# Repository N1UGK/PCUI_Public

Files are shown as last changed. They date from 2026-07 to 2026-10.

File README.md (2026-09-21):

# PCUI (Pocket Computer Universal Interface)
This is the official repo for firmware updates for the PCUI, owners manuals, and general information.  Further, this repo contains a collection of programs for various pocket computers and calculators supported by the PCUI.



## Development History

https://n1ugk.com/2025/12/pocket-computer-universal-interface/

## Features Summary

+ Provides cassette interface emulation to read and write programs and data directly to and from a micro SD card.
+ Provides a printer interface between the pocket computer or calculator and most standard “line printers” such as dot matrix, thermal receipt printers, serial, parallel, and Wi-Fi.
+ Supports printing of custom glyphs, including math, scientific and engineering symbols unique to each model.
+ Works independently without a computer and can be powered by a single 18650 lithium ion rechargeable battery.
+ OLED screen with user-friendly menu system and operating modes
+ Interface packs provide connectivity to each supported model, no need for OEM connection cables.
+ Updatable firmware and PC or Mac connectivity via USB for mounting micro SD card
+ Plotter emulation mode to provide printouts of plots using modern printers allowing programs which leveraged plotter features to be used on modern printers.
+ ASCII BASIC conversion to tokenized BASIC “on the fly”, allowing for program edits and program creation on a Mac or PC and directly sending it to a pocket computer.
+ Wi-Fi connectivity and web interface for program viewing, editing, UI control, printing, and status.
+ Online program library browsing and installing directly from GitHub allows you to view community released programs for various models of pocket computers directly from the PCUI.
+ True low-level cassette interface integration - byte level retrieval and storage of programs and data images, not just a simple "record" and "playback" mechanism.

## Supported Models

The following models are currently supported with more models in progress:

+ Texas Instruments	Graph Link Graphing Calculators
  + TI-82*, TI-85*, TI-86*, TI-89*, TI-92*, TI-92 Plus*, Voyage 200*
+ Sharp 9-pin “CE-121” / “CE-122” Compatibles
  + PC-1210, PC-1211, PC-1212, TRS-80 PC-1*
+ Sharp	Older 11-pin “CE-126P” Compatibles
  + PC-1245, PC-1246, PC-1246S, PC-1247, PC-1248, Tandy PC-8*
  + PC-1250, PC-1250A, PC-1251, PC-1251H, PC-1255, Tandy PC-3* and PC-3 A/B*, PC-1270
+ 11-pin “CE-126P” Compatibles
  + PC-1260, PC-1280
+ Sharp	Newer 11-pin “CE-126P” Compatibles
  + PC-1401, PC-1403*, PC-1421, PC-1430, PC-1450, EL-5500, EL-5500 II, EL-5500III*
+ Casio	12-pin PB-100 Series FP-12(S) Compatibles
  + PB-100, PB-110, PB-120, PB-200, PB-400, PB-410*, FX-700P, FX-710P, Tandy PC-4 Version B*, TRS-80 PC-4 Version A*
+ Casio	12-pin FX “Clamshell” Series
  + FX-770P, FX-780P, FX-781P, FX-785P, FX-790P, FX-791P, FX-795P, Tandy PC-5*, Tandy PC-6*
+ Casio	15-pin “FA-10” Compatibles
  + PB-700*, PB-770*
+ Casio	FX-702P*, FX-602P*

_*Tested and Verified, others should work since they use the same interface_

The PCUI Owners manual can be found in the [Documentation](./Documentation/) folder.

Firmware updates can be found in the [Firmware](./Firmware/) folder.

## Purchasing a Kit or Fully Assembled PCUI

A PCUI can be purchased as a kit or fully assembled.  

+ PCUI Kit - includes pre-flashed Pico 2 W, Main PCB and all components.  Interface pack kits are add-ons.  
  + Assembly instructions are located in the [Documentation](./Documentation/) folder.
  + The BOM, 3D model, KiCad Projects are located in the [Hardware](./Hardware/) folder.
+ PCUI Fully Assembled - includes a fully assembled PCUI and chosen interface pack add-ons.
+ A link to purchase either option will be added soon.

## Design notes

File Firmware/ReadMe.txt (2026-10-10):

Firmware Release Notes

Note - In order to update the firmware, you will need to place the PCUI into bootloader mode.  This can be done via the main menu, then Settings, then Update Firmware.  

The PCUI will reboot into it’s bootloader mode.  Plug the PCUI into a Mac or PC, and drag and drop the firmware file onto the removable drive that appears.  

The PCUI will decrypt the firmware file, verify the signature, and if it passes, it will pause for 5 seconds, flash, and reboot.  

Note that the PCUI bootloader is different from the Pico bootloader - if you use the bootsel button on the pico to get into the bootloader and drag and drop the PCUI firmware, it will be rejected as the Pico's bootloader cannot decrypt the firmware image.  You can easily determine which bootloader you are in by looking at the directory contents of the USB drive which appears on your computer.  If you see PCUI.txt, then you are in the PCUI's bootloader.  If you see another *UF2.txt file, then you are in the Pico's bootloader.

10-??-2026 - PCUI_V1.16_B????.uf2

Added 4 color pen support for plotter emulation, PNG and GIF, web live view (PB-700/PB-770).
Added Casio FP-100 plotter emulation.
Fixed HP LaserJet printer path for TI graphing calculators, as well as the scaling setting.
Added AP Setup mode for Wi-Fi - connect to the PCUI as an accesspoint and use your phone browser to enter SSID and PW

Backlog - Sharp Plotter Emulation

08-04-2026 - PCUI_V1.15_B2364.uf2

Added Hex Translation feature for printing from pocket computers with limited range of byte output.
Fixed plotter emulation for Casio models, bytes were not converted to ASCII before being dispatched to the plotter emulator.
Fixed plotter emulation for Sharp models, bytes were not routed to the plotter emulator.
Fixed race condition when exiting printer mode (CE-126 compatibles) during the 1.4 second EOL pause timer.
Added proper handling for when a PC or Mac host "ejects" our SD card passthrough.
Fixed issue where send menu options disappear when exiting SD card passthrough mode (some Sharp modes).
Added a settling delay for parallel port output before reading "busy" pin, enabled via Slow Printer in Printer menu.
Added Program Repo feature which allows browsing of the public GitHub Pocket Computer Programs folder to view and install programs per model, from the PCUI.
Added screen saver to prevent OLED burn in
Fixed issue where PNG and AGIF plotter emulation output was not saved if no printer is selected or if a non-graphics capable printer was selected.
Fixed PC-1245 tokenization issue with the "?" character and spacing causing keywords to fall through.

07-29-2026 - PCUI_V1.14_B2080.uf2

Fixed issue with Casio models which used the FA-3 cassette interface, timing issue with tape loading was present on the release build, debug builds unaffected.
Fixed issue with Sharp models, CE-126P compatibles, printing support in release mode, timing issue.
Fixed Casio FX-702P, open detect and printing support, timing issue in release mode.
Added RTS/CTS flow control support for RS-232 port.
Added preliminary Sharp PC-1260 and PC-1280 support, which is a combination of existing 1401 support (for tape) and 1245 support (for the printer).
Corrected last 4 pins displayed in self-set mode, buffer test.
Fixed display of mode "None" and menu option for this model/mode.  None now appears in the menu, and PCUI will be displayed on the home screen.
Updated frequency out generator in self-test mode for Pico2 (was set based on Pico1).
Added OE and Direction toggling for level shifting pocket computer buffer in self-test mode.

07-18-2026 - PCUI_V1.13_B1996.uf2

Fixed SD card mount issue after bootloader session, SD card mount failed.
Added debug output option when saving programs and variables.  This debug.bin will contain all framing and content received.

07-17-2026 - PCUI_V1.12_B1975.uf2

Fixed Sharp PC-1245 printer bug - an extra bit was introduced from an erroneous SEL2, BUSY pulse in some printing scenarios. 

07-16-2026 - PCUI_V1.11_B1968.uf2

Fixed tokenization and detokenization issues for Sharp PC-1245. 
Fixed SD card folder for Sharp PC-1245 (was incorrectly using PC-1246).
Added WIFI.TXT support (see owners manual for description).
Fixed issue where SD card removal (while powered on) would cause reboot if config is the same (unchanged).
SD card subfolders automatically created when mode is selected, rather than on-demand during save.
When in an empty BASIC folder, the web interface did not show the Create New button.

07-10-2026 - PCUI_V1.10_B1776.uf2

Support added for the Sharp PC-1210/PC-1211/PC-1212 (tested only on the PC-1211 / TRS-80 PC-1).  
Wi-Fi printer support using mDNS browser, HP LaserJet PCL modes only

07-04-2026 - PCUI_V1.01_B1658.uf2

This release addresses protocol bugs for the Casio PB-100 series devices and the Casio PB-700 series devices.  The printer and cassette interface was rewritten based on actual wire captures.  For the PB-700 series, ASCII mode program transfers are now reliable.

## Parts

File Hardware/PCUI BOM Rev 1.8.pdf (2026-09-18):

Id | Column2 | Footprint | Quantity Designation | Supplier and ref | Mouser
| 32 A01 | MODULE_SC0918 | 1 SC0918 | Pico 2W
| 7 C01, C02, C05, C28 | C1206 | 4 0.047uF | C1206C473J5RACTU | 80-C1206C473J5R (https://www.mouser.com/en/ProductDetail/KEMET/C1206C473J5RACTU?qs=nFy0p7co80TBuVc0Zw9RMQ%3D%3D)
| 3 C03, C04, C07, C18, C19, C20, C21, C22, C23, C24, C27, C31, C32, C33, C34 | CAPC3216X94N | 15 0.1uF | KAM31NR72A104KU | 581-KAM31NR72A104KU
| 21 C06, C08, C09, C10, C11, C12, C13, C14, C15, C16, C17 | CAPC3216X94N | 12 470pF | 12062A471KAT2A | 581-12062A471KAT2A
9 C25, C26, C29, C30 | CAPC1608X90N | 4 10uF | GRM188R60J106ME84D 81-GRM188R60J106ME4D
| 26 IC1 | SOIC127P1032X265-16N | 1 IIC 0x3A MAX7329AWE+T | MAX7329AWE+ | 700-MAX7329AWE
| 8 IC10, IC11, IC5, IC9 | SOIC127P1030X265-24N | 4 SN74LVC8T245DWRG4 | SN74LVC8T245DWRG4 | 595-74LVC8T245DWRG4
| 40 IC12 | SOP50P490X110-11N | 1 BQ24090DGQR | BQ24090DGQR | 595-BQ24090DGQR
| 15 IC2 | SOIC127P1032X265-16N | 1 IIC 0x39 MAX7329AWE+T | MAX7329AWE+ | 700-MAX7329AWE
| 22 IC3 | SOIC127P1032X265-16N | 1 IIC 0x38 MAX7329AWE+T | MAX7329AWE+ | 700-MAX7329AWE
| 35 IC4 | SOIC127P600X175-16N | 1 SP3232EEN-L_TR | SP3232EEN-L/TR | 701-SP3232EEN-L/TR
| 1 IC6 | SOP65P490X110-8N | 1 MCP1642B-50I_MS | MCP1642B-50I/MS | 579-MCP1642B-50I/MS
| 25 IC7 | SOIC127P1032X265-16N | 1 IIC 0x3B MAX7329AWE+T | MAX7329AWE+ | 700-MAX7329AWE
| 6 IC13, IC8 | SOT95P280X145-5N | 2 MAX40200AUK+T | MAX40200AUK+T | 700-MAX40200AUK+T
| 27 J01 | TSS-108-XX-YYY-D | 1 5V Connector
| 37 J02 | 23117661 | 1 2311766-1 | 2311766-1 | 571-2311766-1
| 19 J03 | PinHeader_1x02_P2.54mm_Vertical | 1 RX_J
| 5 J04, J05, J06, J07, J08, J09, J10, J11, J12, J13, J14, J16, J17, J18, J19, J20, J22, J23, J26, J28, J31, J32 | SAMTEC-HMTSW-101-24-X-S-290 | 22 SAMTEC-HMTSW-101-24-X-S-290
| 36 J15 | SJ2524SMTTR | 1 SJ-2524-SMT-TR | SJ-2524-SMT-TR | 490-SJ-2524-SMT-TR
| 20 J21 | PJS00821200 | 1 PJS008-2120-0
| 28 J24 | 6E17C009PBF221 | 1 RS-232 DB-9 | 6E17C009PBF221 | 523-6E17C009PBF221
| 30 J25 | PinHeader_1x02_P2.54mm_Vertical | 1 TX_J
| 39 J27 | SAMTEC_TSS-107-02-H-D | 1 3.3V Connector
| 16 J29 | PinHeader_1x02_P2.54mm_Vertical | 1 CTS_J
| 34 J30 | PinHeader_1x02_P2.54mm_Vertical | 1 RTS_J
| 18 L01 | EPL3015472MLC | 1 4.7uH | EPL3015-472MLC | 994-EPL3015-472MLC
| 11 LED1, LED2, LED3, LED4, LED5, LED7 | LEDM3528X200N | 6 HSMM-A100-S00J1 | HSMM-A100-S00J1 | 630-HSMM-A100-S00J1
| 23 LED6, LED8 | HSMSA100L00J1 | 2 HSMS-A100-L00J1 | HSMS-A100-L00J1 | 630-HSMS-A100-L00J1
| 17 Q01, Q02, Q03, Q04 | SOT95P240X120-3N | 4 BSS138 | BSS138 | 512-BSS138
| 10 R01, R03, R04, R32, R39, R40, R41, R42, R47 | RESC2013X65N | 9 3.3K | WCR0805-3K3FI | 756-WCR0805-3K3FI

4

| R02, R05, R06, R07, R08, R09, R10, R11, R12, R13, R15, R16, R17, R18, R19, R20, R21, R22, R23, R24,
| R25, R26, R27, R28, R29, R30, R31, R37, R44, R45, R46, R50, R55, R56, R57 | RESC2013X65N | 35 10K | WCR0805-10KFI | 756-WCR0805-10KFI
| 13 R38 | RESC2013X65N | 1 100K | CRCW0805100KJNECC | 71-CRCW0805100KJNECC
| 33 R43, R52 | RESC2013X65N | 2 150 | WCR0805-150RFI | 756-WCR0805-150RFI
| 24 R53 | RESC2013X65N | 1 2K | GWCR0805-2K0FT5 | 756-GWCR0805-2K0FT5
| 2 R54 | RESC2013X65N | 1 1K | WCR0805LF1001FPLT | 66-WCR0805LF1001FPLT
12 S01, S02, S03, S04 | TS026655BK160LCRD | 4 TS02-66-55-BK-160-LCR-D | TS02-66-55-BK-160-LCR-D 179-TS026655BK160LCR
| 29 S05 | MHSS1104 | 1 MHSS1104 | MHSS1104 | 642-MHSS1104
| 38 U03 | Display_128x64_096_I2C | 1 IIC 0x3C DM-OLED096-636
| 31 U05 | 1043 | 1 1043 | 1043 | 534-1043

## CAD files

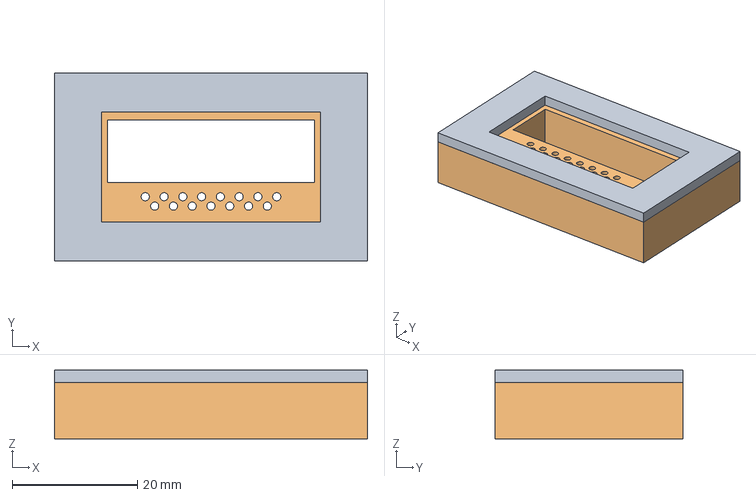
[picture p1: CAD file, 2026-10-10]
Hardware/KiCad/PB-700 Connector/PB-700 Jig.FCStd
50.0 x 30.0 x 11.0 mm

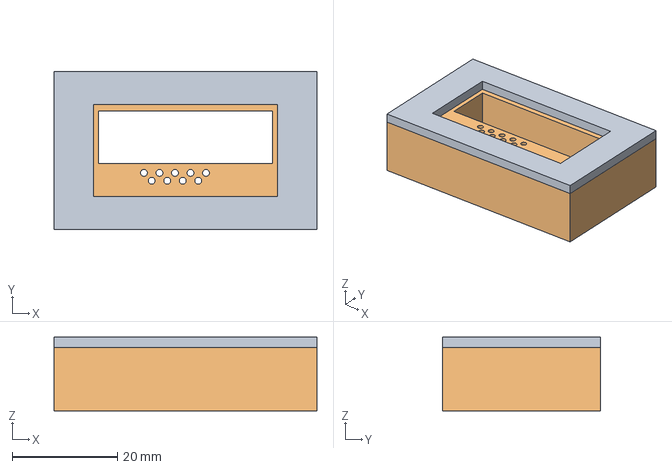
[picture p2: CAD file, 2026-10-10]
Hardware/KiCad/FX-702P Connector/FX-702P.FCStd
50.0 x 30.0 x 14.0 mm

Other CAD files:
Hardware/KiCad/FX-702P Connector/FX-702P Jig.stl
Hardware/KiCad/FX-750P Connector/FX-750P Connector.step
Hardware/KiCad/PC1 Connector/PC1 Connector.step
Hardware/KiCad/PC6 Connector/PC6 Connector.step
Hardware/KiCad/PC8 Connector/PC8 Connector.step
Hardware/KiCad/PocketComputerUniversalInterface/PocketComputerUniversalInterface.step
Hardware/KiCad/PB-700 Connector/PB-700 Connector.step
Hardware/KiCad/PB-700 Connector/PB-700 Jig.stl
Hardware/KiCad/PocketComputerUniversalInterface/PocketComputerUniversalInterface.stl

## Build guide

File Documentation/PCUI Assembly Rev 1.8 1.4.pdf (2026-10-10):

Pocket Computer Universal Interface (PCUI)
Hardware Version 1.8
Document Version 1.4
October 10, 2026

# Assembly Instructions

I. Introduction

Even though these instructions are intended to be as detailed as possible, some experience is absolutely required. Not only is assembly required, surface mount technology (SMT) is utilized throughout the design and sourcing of components for the PCUI.

Unfortunately, through-hole versions of components were not always available for some integrated circuits needed for this project. Therefore, experience soldering SMT components will be required.

Below are some of the tools needed for assembling the PCUI:

### 1. Soldering Iron

A good quality temperature stabilized, and temperature adjustable soldering iron is required. Further, due to SMT components used in this design, an SMT soldering iron tip is required. For example, I have had good results using this soldering tip for SMT: Hakko T18-BR02 - Bent Conical, 0.2mm Radius/30°

If you are prone to making a few mistakes, I recommend solder wick for removing solder.

Be sure to use a quality solder you are familiar with – whether it be leaded or lead-free, know the best temperature for your type of solder and

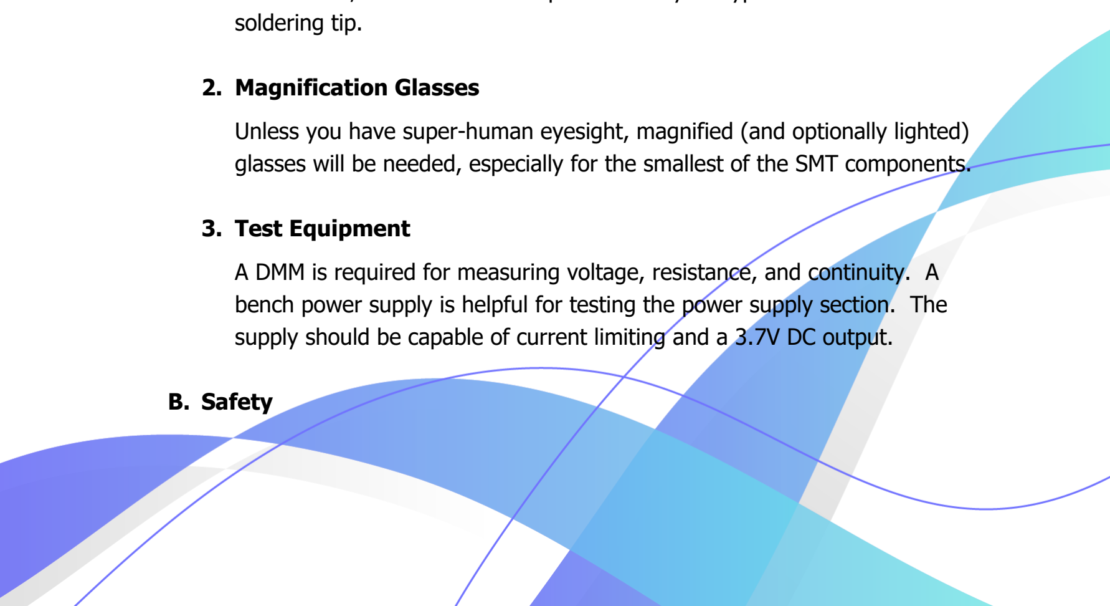
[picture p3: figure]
soldering tip.; 2. Magnification Glasses; 3. Test Equipment; B. Safety

Unless you have super-human eyesight, magnified (and optionally lighted) glasses will be needed, especially for the smallest of the SMT components.

A DMM is required for measuring voltage, resistance, and continuity. A bench power supply is helpful for testing the power supply section. The supply should be capable of current limiting and a 3.7V DC output.

This kit operates on 5 volts and 3.3 volts and is considered “low voltage”. However, safety procedures should be followed to prevent damage to USB ports, batteries, and other components. Lithium-ion batteries can discharge quickly and some are low quality and lack safety measures found in modern battery management systems (BMS). Not all lithium-ion batteries are created equal nor are they all protected from short circuits. Use caution when working with lithium-ion batteries and USB ports.

Regarding lithium-ion batteries, the PCUI is not shipped with a lithium-ion battery due to shipping regulations and safety. A battery is recommended but is not required for the PCUI. If not using a battery, then a USB power source would be required such as a power bank or computer.

C. Patience

Follow these instructions carefully and do not rush. Fully understand the instructions before proceeding. This will help prevent mistakes. Perhaps sharpen your soldering skills by practicing on spare boards and parts before jumping into this kit or a particular step in this build.

D. Hardware Versioning

Please be sure you are reading the most recent document version for the specific hardware version you have. Because the PCUI is distributed either assembled or as a kit, and there are several variants of the hardware that have been distributed, this document is updated accordingly.

The hardware version is provided as silkscreen lettering on the PCUI board. It will be marked similar to “Rev 1.8” as an example.

E. Order of Assembly

Do try and follow the order of assembly outlined in this guide. The reason for doing so is to be sure you can test along the way, reducing the risk of
damage to components should a mistake be made.

II. Inventory of Parts

A. Kit Variations

The PCUI kit you purchased may not have all the interface packs outlined in this guide. Interface packs might be different for each model of pocket computer or calculator you wish to use with the PCUI.

B. Identifying Components

Many components themselves are not labelled or are not necessarily easy to identify. It is recommended to leave components in their packaging or with their labelling until they are needed.

Please note that any pictures included in these assembly instructions are for example only. The actual components you receive might have variations in color or appearance, as substitutions may be made as needed due to parts availability and pricing.

It was intended that all PCUI components be readily available from multiple sources. If you inadvertently damage a component, chances are you can purchase a replacement yourself if you wish, or from the same source as you received the PCUI kit from.

C. Parts and Components

### 1. Raspberry Pi Pico 2 W

Your PCUI kit will contain a variant of the Raspberry Pi Pico 2 W. It has been pre-flashed with the bootloader and the firmware available at the time it was flashed. The firmware will most likely need updating and can be done by connecting the PCUI to a computer. Instructions for updating the firmware are included in the Owners Manual.

### 2. PCUI Main PCB

The PCUI is comprised of a single main PCB and one or more pocket computer interface pack PCBs (if applicable). The main PCB will be identified with a hardware version number – be sure the version number on your kit matches the version number of this guide.

### 3. Pocket Computer Interface Packs

Your PCUI kit might have one or more pocket computer interface packs. These packs contain a small PCB, a connector, and some have additional components. An interface pack is designed for a particular line of pocket computers that share a specific bus interface or pinout.

### 4. Lithium Ion Battery

The PCUI uses an 18650 lithium-ion battery for portable use. The battery itself is not included due to shipping regulations. 18650 batteries can be purchased from many online retailers such as Amazon and are very inexpensive. The PCUI currently does not have a charging circuit for the battery, and therefore the battery should be charged using an external charger.

Note that a battery is not required for PCUI operation. If a battery is not used, then a USB based power source would be required.

### 5. Test Headers

The PCUI includes test header pin locations on the PCB which are optional. These would be useful for debugging or troubleshooting. They are convenient for attaching test leads and can be added later if you need them.

III. Getting Started

A. Unpacking and Inspection

When you first receive your PCUI kit, make sure all components are intact, not damaged, and avoid removing components from their packaging or removing labels until those components are needed. Many components are not individually labelled.

1. Inspect the packaging for any signs of damage during shipping.
2. Check that all components are present, based on the particular kit options you selected.
B. PCUI Main Board

The fully assembled PCUI main board is shown below. Assembly instructions for each section if the main board is described in the next sections.

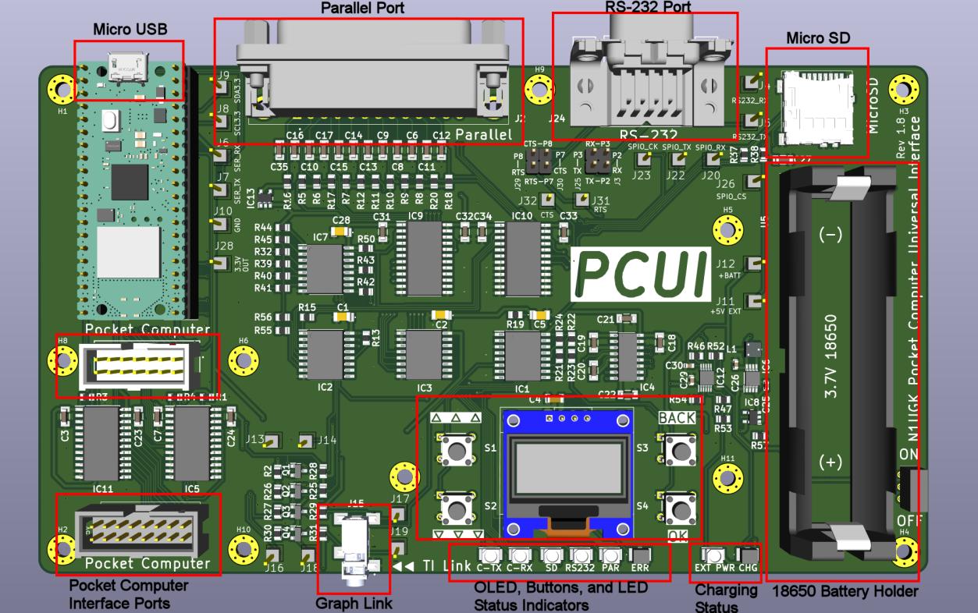
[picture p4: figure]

IV. PCUI Main Board Assembly Instructions

A. Power Supply Section

### 1. Assembly

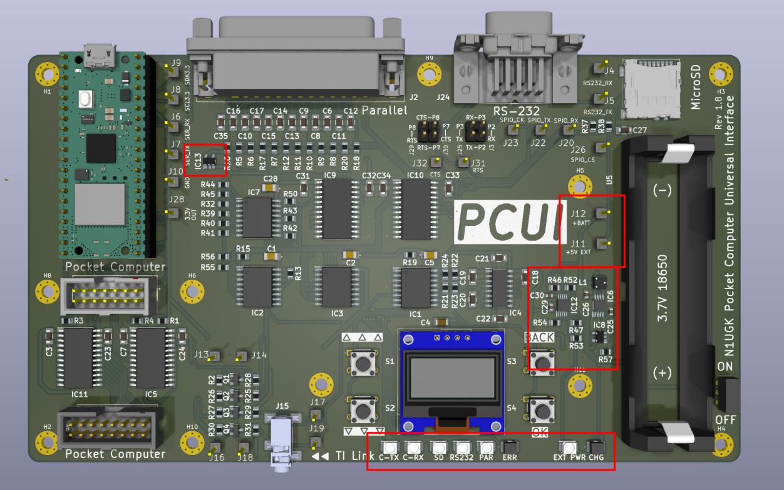
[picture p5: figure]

- Solder L1 (EPL3015-472MLC) then test the connection across the two pins of IC6 as shown below. It should indicate a “short”, meaning the inductor is correctly soldered and making contact. Avoid using too much heat on this inductor, and avoid touching the case with the iron, as it will melt.

I have found it easiest to place solder paste on one pad on the PCB, then position the inductor so that only about ½ of the surface of each leg (underside) is on the pads, exposing a good portion of the pads on the PCB for the iron to heat up effectively, pressing lightly down on the inductor when heating the pad with the solder paste. Then, once solidly affixed on one side, heat the other pad, add solder, and the solder should travel across the pad to the leg of the inductor.

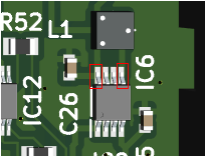
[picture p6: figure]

- Solder IC6 (BQ24090DGQR)
- Solder IC12 (MCP1642B-50I/MS)
- Solder IC8 and IC13 (MAX40200AUK+T Ideal Diode)
- Solder 2 150 ohm resistors R43, R52
- Solder 2 10K resistors R46, R57
- Solder 1 3.3K resistor R47
- Solder 1 2K resistor R53
- Solder 1 1K resistor R54
- Solder 4 10 uF capacitors C26, C25, C29, C30.
- Solder S5 (power switch).

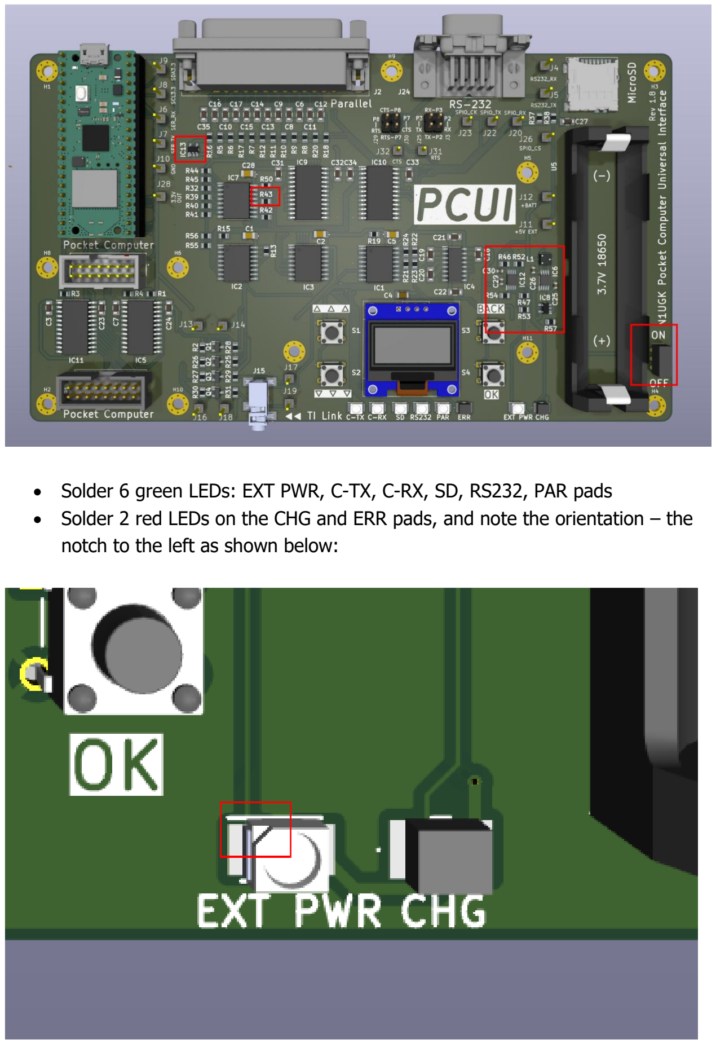
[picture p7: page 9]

- Solder 6 green LEDs: EXT PWR, C-TX, C-RX, SD, RS232, PAR pads
- Solder 2 red LEDs on the CHG and ERR pads, and note the orientation – the notch to the left as shown below:

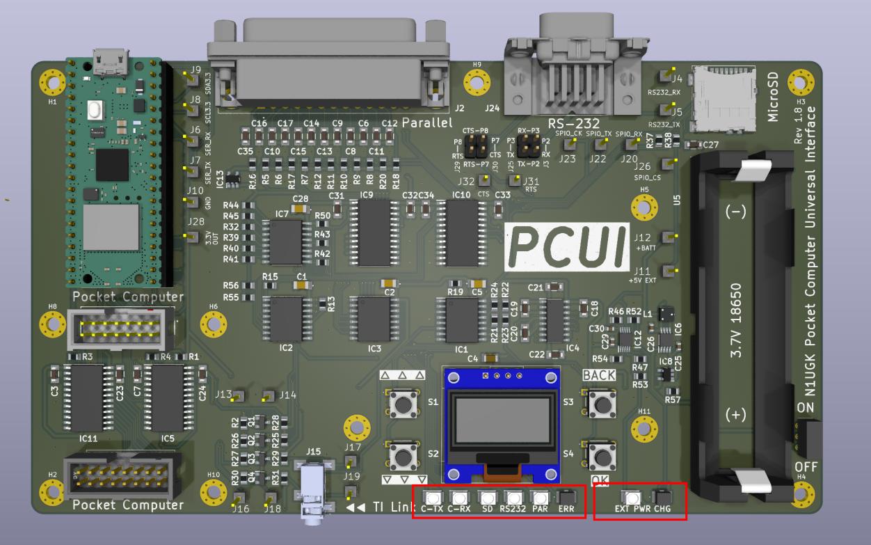
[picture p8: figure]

Note the cathode side is marked with a notch on the corner as shown in the image below. The cathode is the negative or GND side of the LED. This should point to the LEFT on the PCB for all LEDs.

- Solder a header pin to J12, J11, and J10.

### 2. Testing

Apply 3.7 volts DC to pin J12, and limit current to about 100mA. Use J10 as GND. Turn the power switch S5 on the PCUI ON. Measure the voltage from pin J11. You should see 5 volts DC on pin J11.

If you do not see 5 volts and excessive current, look for a solder bridge on the ICs you soldered. If you do not see 5 volts and no current draw, double check L1 and the capacitors you soldered – if there’s an “open” connection on any parts, the power supply will not output voltage. You can lightly press on each component and pin for example to check for missing connections or bad solder joints.

Once you get the DC/DC step up working (+5 volts from J11), connect your bench power supply to the top right most pin of the Pico board, which is VBUS. Set the supply to 5 volts DC, with a current limit of 100 mA. Use J10 for GND. Turn on the bench supply and check that the green EXT PWR light illuminates.

If the EXT PWR light does not illuminate, make sure the orientation of the LED is correct, and then check IC12 for solder bridges or pins without a good connection. Also check capacitors and resistors to make sure they are well connected.

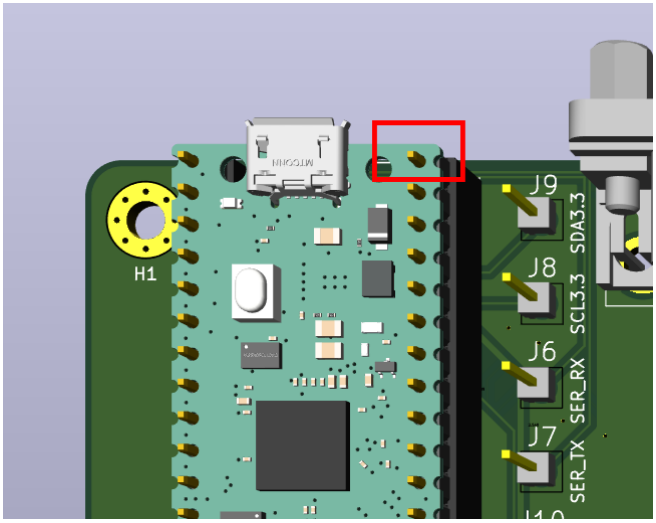
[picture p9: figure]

B. MAX 7329 AWE Port Expanders
- Solder 4 MAX 7329 AWE Port Expanders IC1, IC2, IC3, IC7:

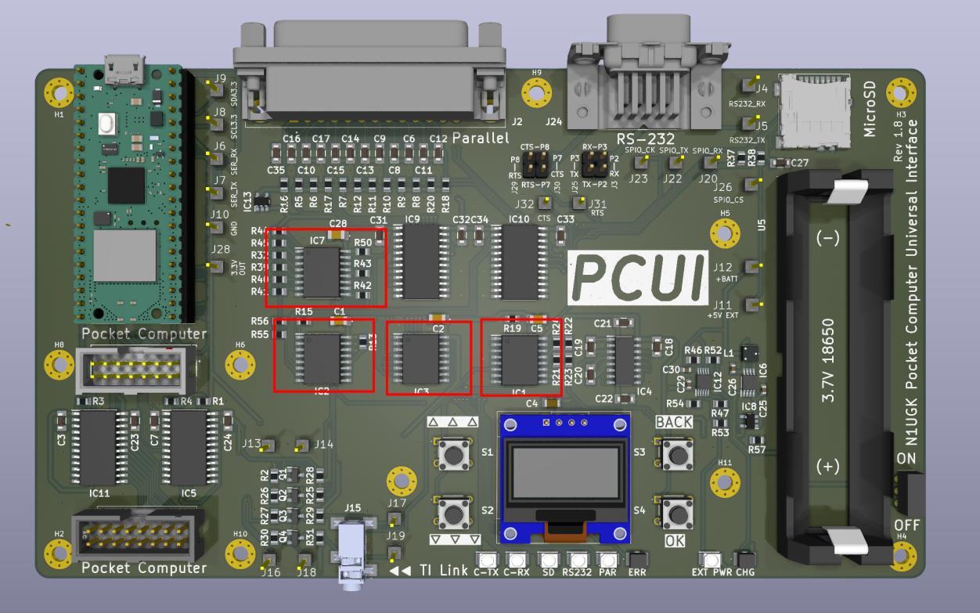
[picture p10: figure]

C. SP3232 RS-232 Interface IC
- An SP3232 RS-232 interface IC needs to be soldered onto the PCB where the silkscreen indicates IC4 (see highlighted area below):

Be sure to note the orientation of the SP3232 IC – Pin 1 is indicated on the silkscreen on the top right corner with a horizontal line.

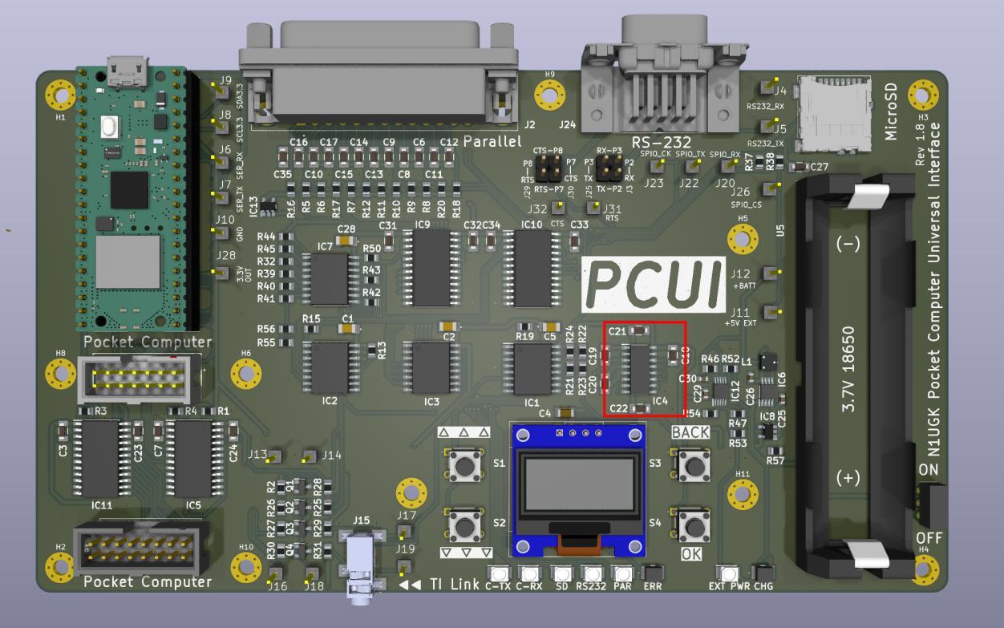
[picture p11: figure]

D. SN74LVC8T245DWRG4 Buffers
- 4 SN74LVC8T245DWRG4 buffer ICs need to be soldered onto the PCB where the silkscreen indicates IC11, IC5, IC9, and IC10 (see highlighted area below):

Be sure to note the orientation of the SN74LVC8T245DWRG4 IC – Pin 1 is indicated on the silkscreen on the top right corner with a horizontal line.

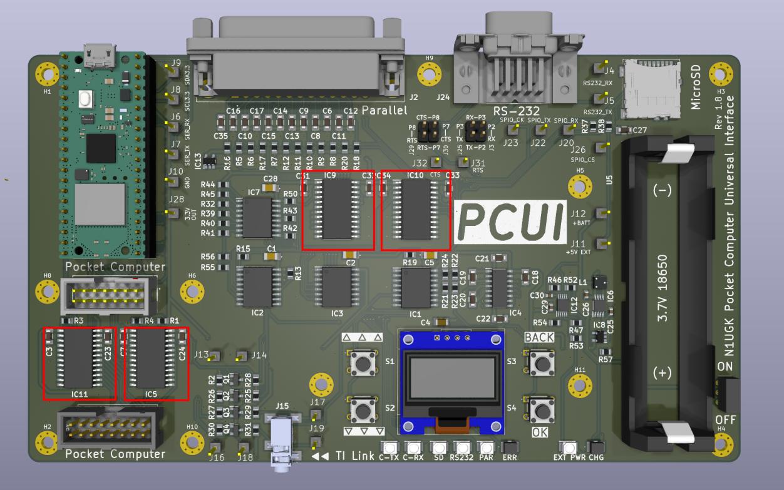
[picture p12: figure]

E. BSS138s
- Solder 4 BSS138s for Q1, Q2, Q3, and Q4.

See highlighted area below:

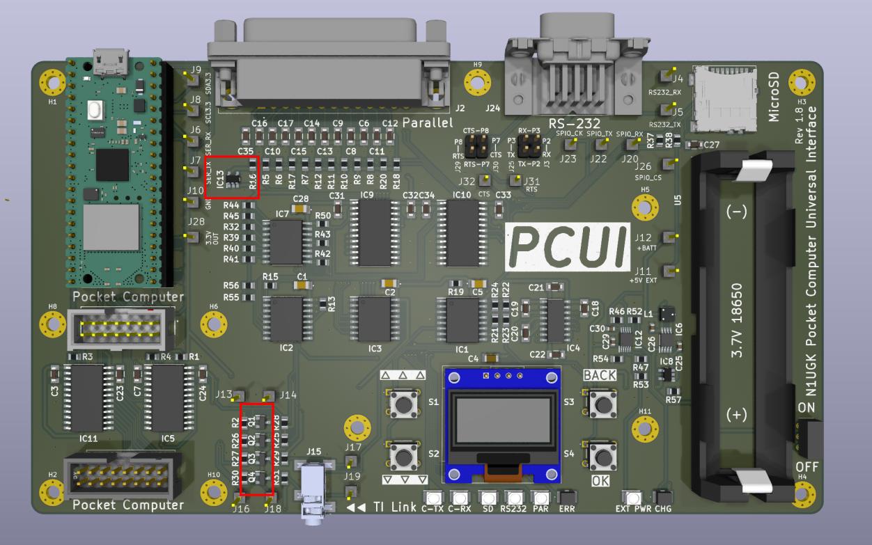
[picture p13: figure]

F. 0.1 uF SMT Capacitors
- Solder 15 0.1 uF capacitors C03, C04, C07, C18, C19, C20, C21, C22, C23, C24, C27, C31, C32, C33, C34

See highlighted areas below:

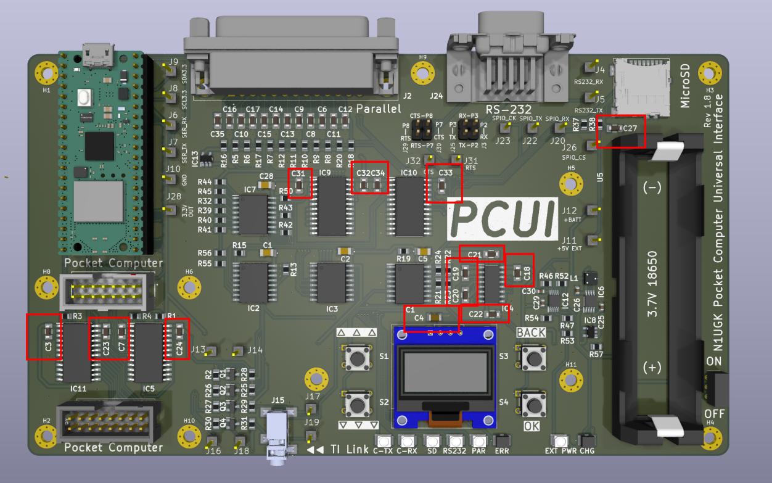
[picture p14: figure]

G. 470 pF SMT Capacitors
- Solder 12 470 pF capacitors C06, C08, C09, C10, C11, C12, C13, C14, C15, C16, C17.

See highlighted areas below:

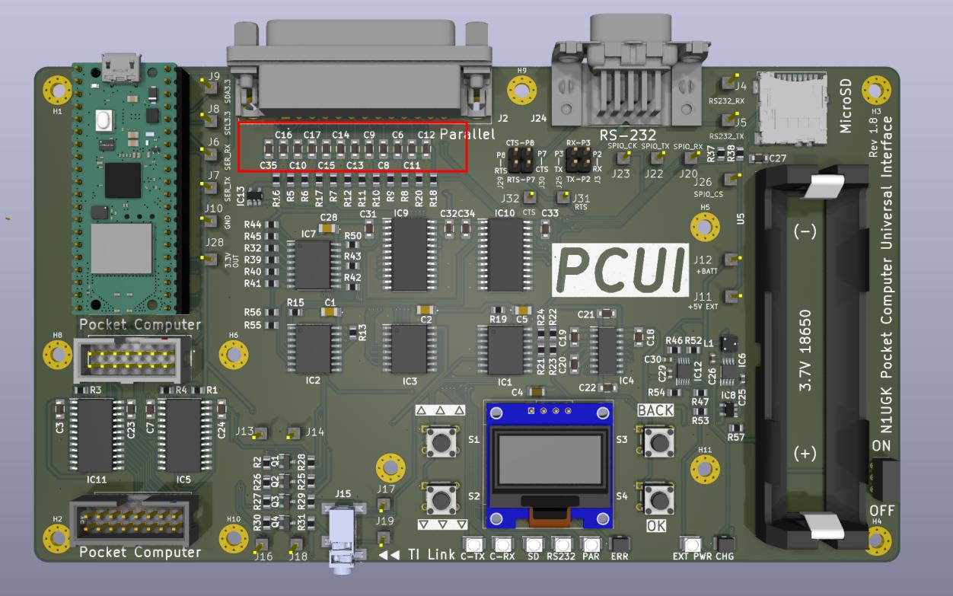
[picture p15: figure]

V. PCUI Main Board Assembly Instructions
A. Power Supply Section 3.3 K SMT Resistors
- Solder 8 3.3K resistors R01, R03, R04, R32, R39, R40, R41, R42.

See highlighted areas below:

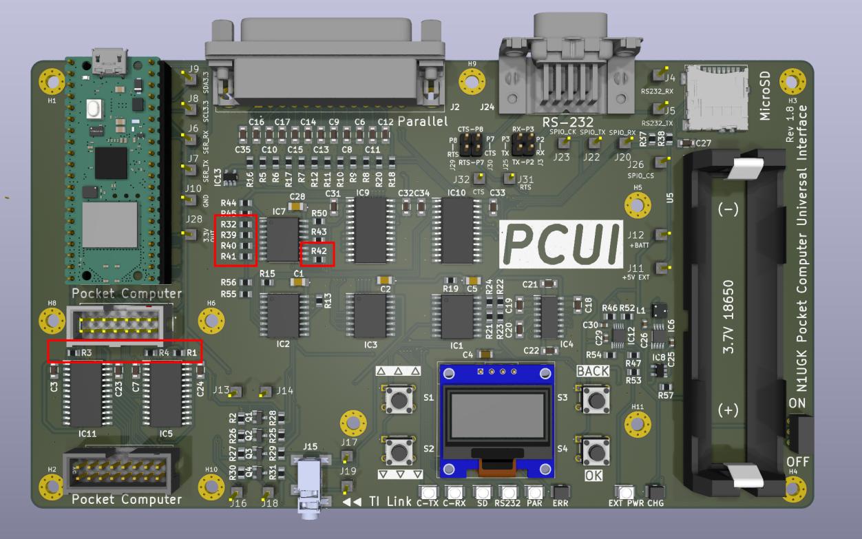
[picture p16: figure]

B. 100 K SMT Resistor
- Solder 1 100K resistor R38.

See highlighted areas below:

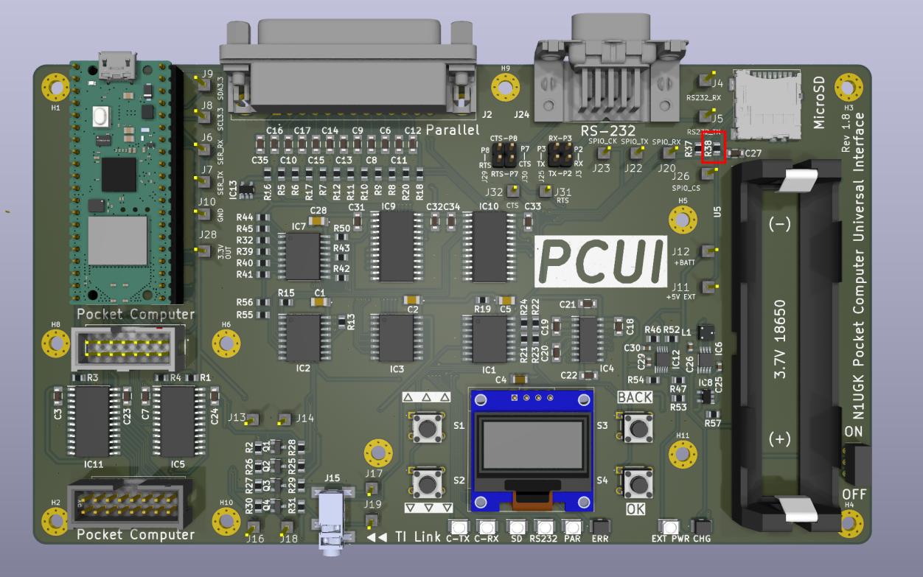
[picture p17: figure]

C. 10 K SMT Resistors
- Solder 33 10K resistors R02, R05, R06, R07, R08, R09, R10, R11, R12, R13, R15, R16, R17, R18, R19, R20, R21, R22, R23, R24, R25, R26, R27, R28, R29, R30, R31, R37, R44, R45, R50, R55, R56.

At this point in the assembly, all other resistor footprints/pads remaining are 10K. See highlighted areas below:

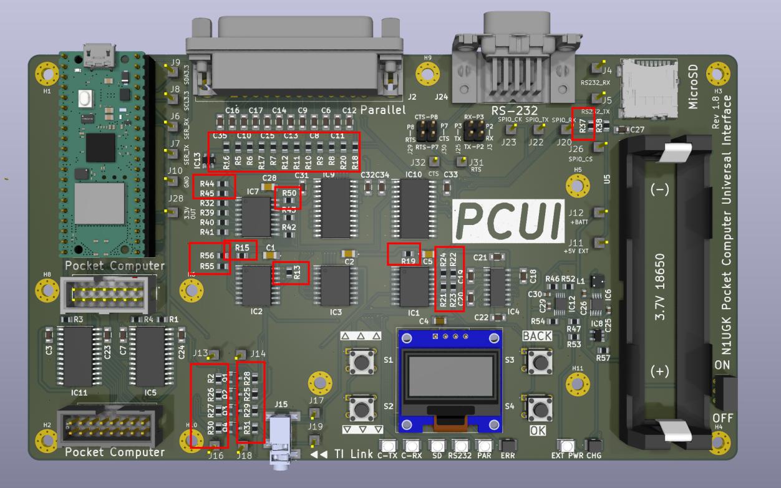
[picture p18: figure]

D. Micro SD
- Solder the micro SD holder.
- Insert the micro SD card into the slot after it is soldered.

See highlighted area below:

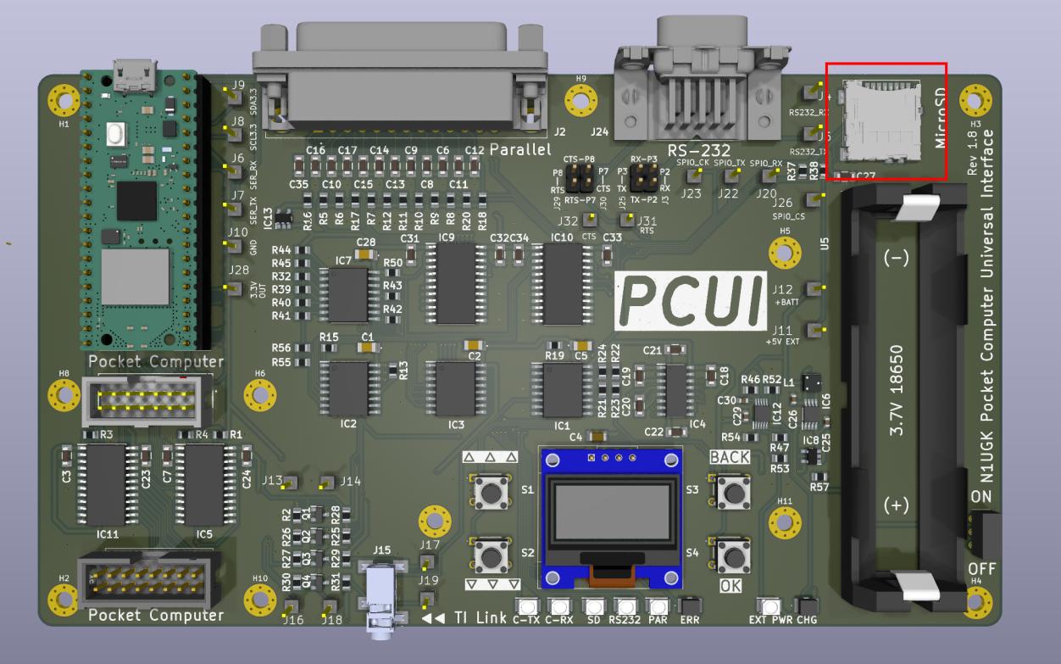
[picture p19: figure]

A micro SD holder needs to be soldered onto the PCB in the area labelled J21. Be extremely careful in soldering this holder onto the PCB. Use very little solder, as little as possible on the pin connections. Too much solder will result in clearance issues with the SD

card. Solder paste would be recommended.

Also note the card switch contact highlighted below. Use very little solder here, as this pin connector is very close to the metal housing which is grounded. If too much solder is used here, you will end up with a solder bridge to the housing and grounding this signal line. If this happens, SD card detection will not work properly, and the SD card functions will be disabled.

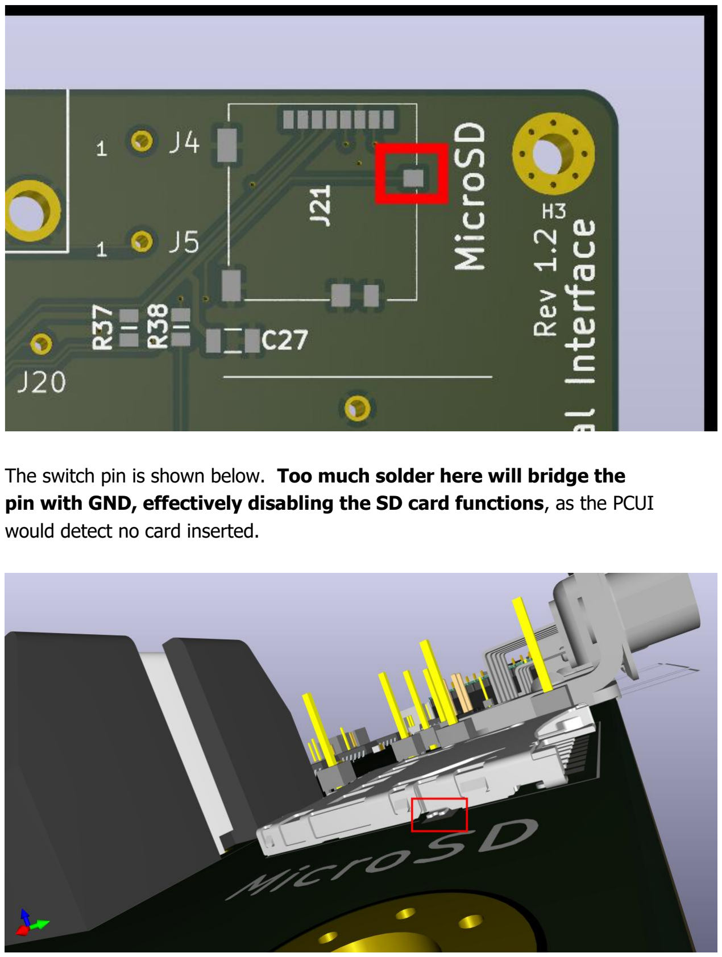
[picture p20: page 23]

The switch pin is shown below. Too much solder here will bridge the pin with GND, effectively disabling the SD card functions, as the PCUI would detect no card inserted.

E. RS-232 Jumpers and RS-232 DB-9 Connector
- Solder jumpers for RTS/CTS and RX/TX for the RS-232 port.
- Place jumpers in a vertical position over the RX/TX section, and leave the jumpers off for the RTS/CTS flow control.
- Solder the DB-9 connector onto the PCB. Be sure to solder all pins in order to provide adequate grounding / shielding as well as mechanical stability. Be sure to solder the metal binding posts as well. Soldering the binding posts will provide mechanical stability and prevent damage to the PCB and the connector from forces applied when plugging and unplugging connectors to and from this port.

See highlighted areas below:

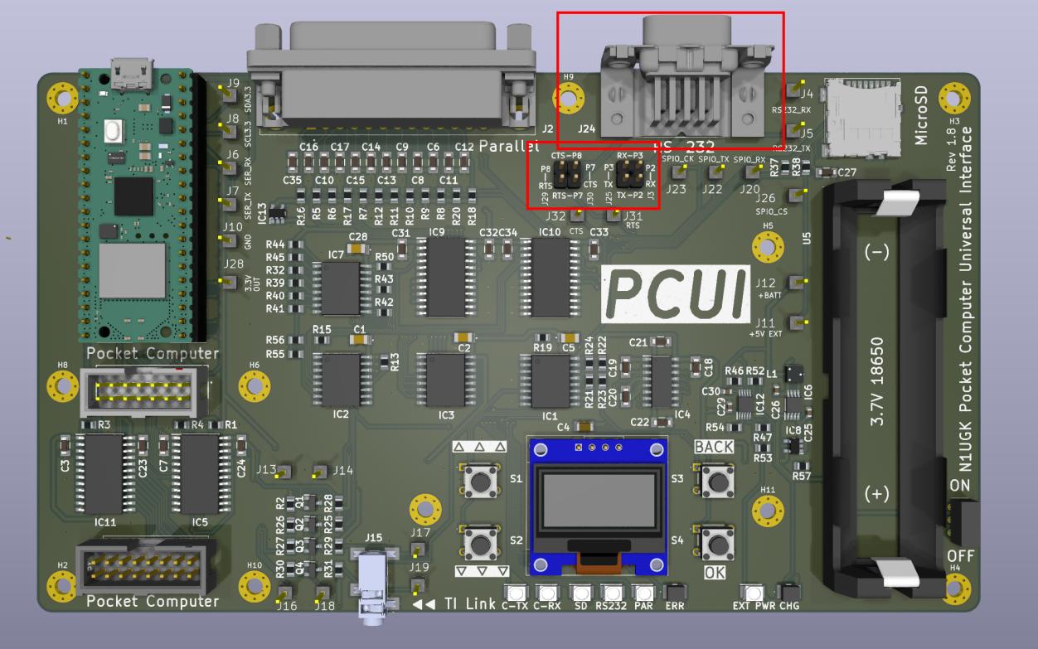
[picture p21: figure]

F. Parallel Port Connector
- Solder the 25-pin connector onto the PCB. Be sure to solder all pins in order to provide adequate grounding / shielding as well as mechanical stability. Be sure to solder the metal binding posts as well. Soldering the binding posts will provide mechanical stability and prevent damage to the PCB and the connector from forces applied when plugging and unplugging connectors to and from this port.

See highlighted areas below:

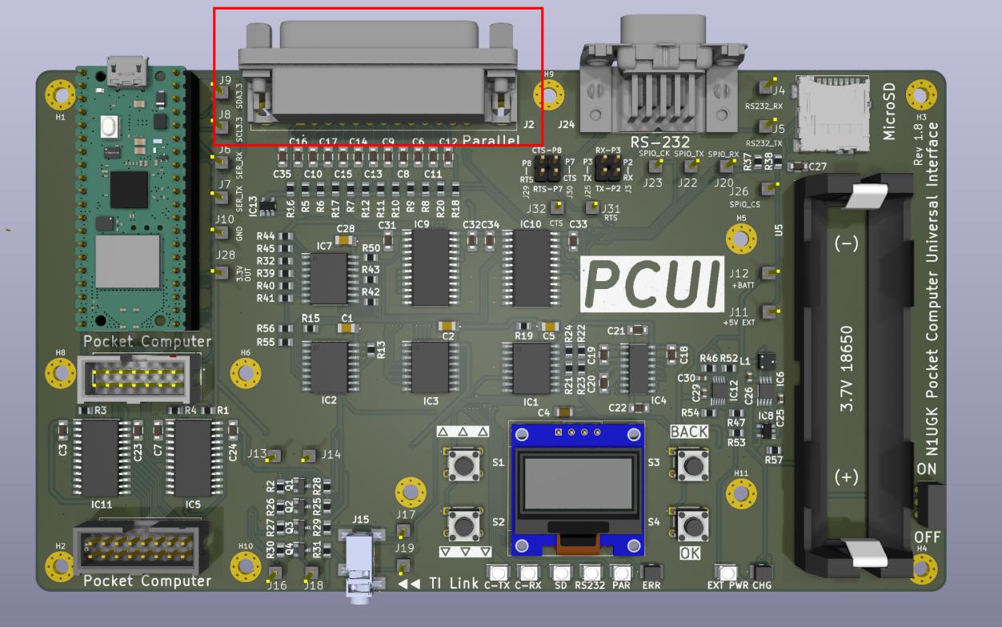
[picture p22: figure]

G. Pocket Computer 14 and 16-pin Connectors
- Solder the 14-pin IDC header for J27
- Solder the 16-pin IDC header for J1.

Be sure the “notch” faces upward toward the top of the PCB.

See highlighted areas below:

H. TI-Link Connector
- Solder the 3.5mm stereo connector for J15.

See highlighted area below:

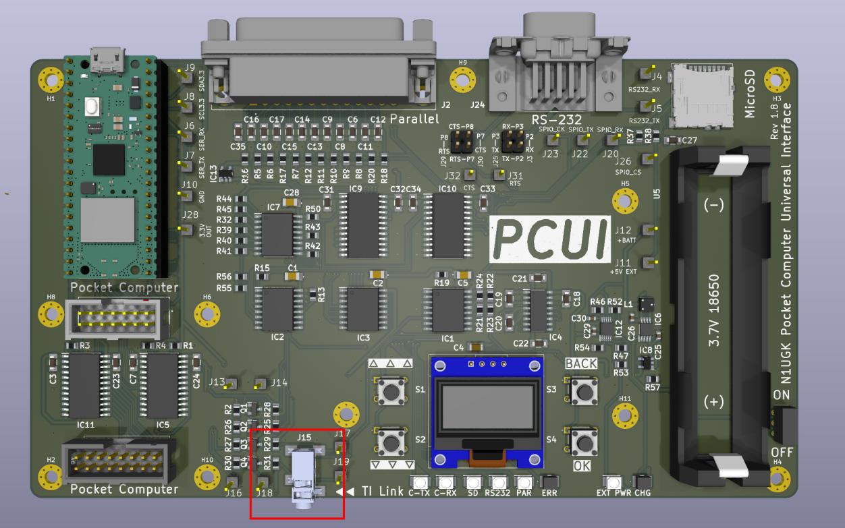
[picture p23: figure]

I. 18650 Battery Holder
- Solder the 18650 battery holder onto the PCB. Do not add an 18650 battery at this point.

See highlighted area below:

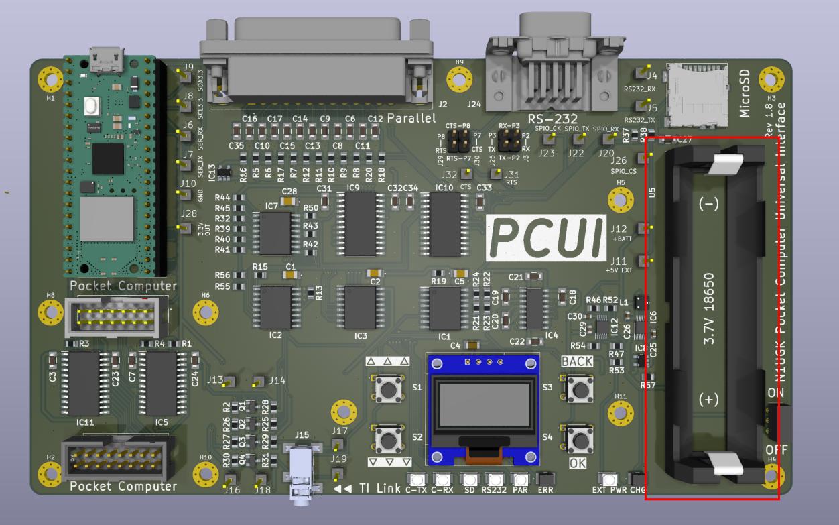
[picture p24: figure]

J. Pico 2 W
- Solder the Pico 2 W onto the PCB.

Be sure the USB connector on the Pico 2 faces the top of the board.

See highlighted area below:

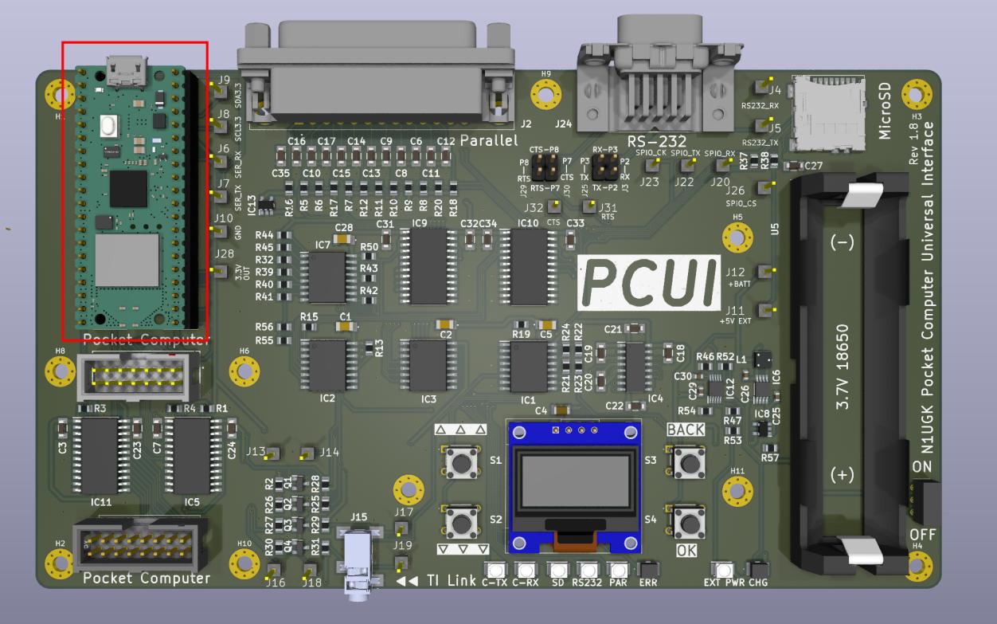
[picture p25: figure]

K. Micro Push Buttons and OLED
- Solder 4 micro pushbutton switches S1, S2, S3, S4.

See highlighted areas below:

Note that the pins on these micro switches should be oriented so that they are on the left and right sides of the switch (not the top and bottom of the switch)

Mounting bolts for the OLED need to be attached – use two nuts on each bolt (underside). For example, see pictures below:

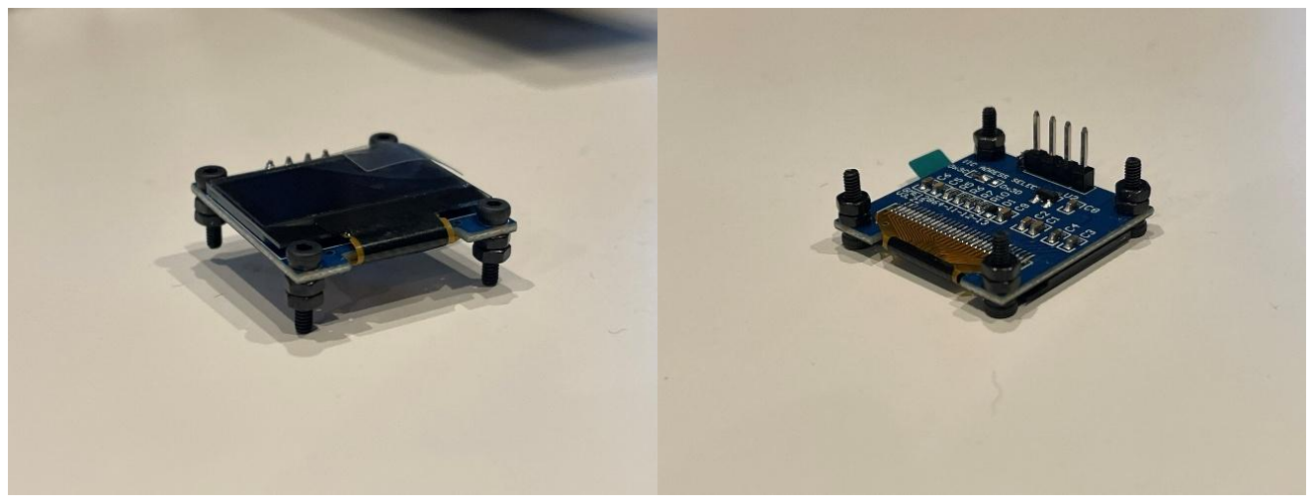
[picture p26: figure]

These nuts add spacing needed for leveling of the OLED against the PCB.

Then fasten the OLED onto the PCB with the 4 remaining nuts, then solder the 4 pins.

L. Nylon Standoffs

If you ordered a case for the PCUI, skip this step.

Install 11 nylon standoffs for H1, H2, H3, H4, H5, H6, H7, H8, H9, H10, H11.

See highlighted areas below:

VI. TRS-80 PC-1 / Sharp PC-1211 Interface Pack

The TRS-80 PC-1 / Sharp PC-1211 interface pack is a double sided PCB, meaning there are components on both sides.

A. 10K SMT Resistors
- Solder 5 10K SMT resistors R01, R03, R04, R05, R06, R07.
B. Green SMT LED
- Solder a green SMT LED, LED01. Note the notch on the LED should point to the left.
C. 16-Pin IDC Connector
- Solder a 16-pin IDC connector J2. Be sure to solder this connector on the correct side of the PCB. It is to be soldered on the side with the 4 resistors, not the side with the 1 resistor and 1 LED. Note the notch orientation points downward.
D. 9-Pin Pocket Computer Connector
- Solder the 9-pin pocket computer connector J1. Be sure to solder this connector on the correct side of the PCB. It is to be soldered on the side with the 1 LED and 1 resistor, not the side with 4 resistors and the J2 connector.

VII. Casio PB-700/PB-770 Interface Pack

The Casio PB-700 and PB-770 interface pack is a double sided PCB, meaning there are components on both sides.

A. 15-Pin Pocket Computer Connector
- Solder the 15-pin pocket computer connector. Be sure to solder this connector on the correct side of the PCB. It is to be soldered so that the pins come out on the side with the 1 LED and resistors, meaning the soldering happens on the same side as connector J1.
- Use the 3D printed mold to place the PCB with J1 upward. Then place the 15 pins straight down so that they protrude just a few millimeters above the surface of the PCB – then solder in place.
B. 10K SMT Resistors
- Solder 6 10K SMT resistors R01, R02, R03, R04, R06, R07.
C. Green SMT LED
- Solder a green SMT LED, LED01. Note the notch on the LED should point to the left.
D. 16-Pin IDC Connector
- Solder a 16-pin IDC connector J1. Be sure to solder this connector on the correct side of the PCB. It is to be soldered on the side without the resistors and 1 LED. Note the notch orientation points downward.

VIII.Casio FX-702P/FX-602P Interface Pack

The Casio FX-702P and FX-602P interface pack is a double sided PCB, meaning there are components on both sides.

A. 7-Pin Pocket Computer Connector
- Solder the 7-pin pocket computer connector. Be sure to solder this connector on the correct side of the PCB. It is to be soldered so that the pins come out on the side with the 1 LED and resistor, meaning the soldering happens on the same side as connector J27.
- Use the 3D printed mold to place the PCB with J27 upward. Then place the 7 pins straight down so that they protrude just a few millimeters above the surface of the PCB – then solder in place.

•

B. 10K SMT Resistor
- Solder 1 10K SMT resistor R06.
C. Green SMT LED
- Solder a green SMT LED, LED01. Note the notch on the LED should point to the left.
D. 14-Pin IDC Connector
- Solder a 14-pin IDC connector J27. Be sure to solder this connector on the correct side of the PCB. It is to be soldered on the side without the resistors and 1 LED. Note the notch orientation points downward.

IX. Casio PB-100 Interface Pack

The Casio PB-100 interface pack is a double sided PCB, meaning there are components on both sides.

A. 10K SMT Resistors
- Solder 5 10K SMT resistor R01, R02, R03, R04, R06.
B. Green SMT LED
- Solder a green SMT LED, LED01. Note the notch on the LED should point to the left.
C. 12-Pin Pocket Computer Connector
- Solder the 12-pin pocket computer connector. Be sure to solder this connector on the correct side of the PCB. It is to be soldered so that the pins come out on the side with the 1 LED and resistors, meaning the soldering happens on the same side as connector J2. It is recommended to solder just 1 pin first, then ensure the connector pins are “level”, adjusting the one soldered pin as needed. Once the connector is level, then solder the rest of the pins.
D. 16-Pin IDC Connector
- Solder a 16-pin IDC connector J2. Be sure to solder this connector on the correct side of the PCB. It is to be soldered on the side without the resistors and 1 LED. Note the notch orientation points downward, regardless of the silkscreen notation. Rev 1.5 of the PCB incorrectly indicated the notch points upward.

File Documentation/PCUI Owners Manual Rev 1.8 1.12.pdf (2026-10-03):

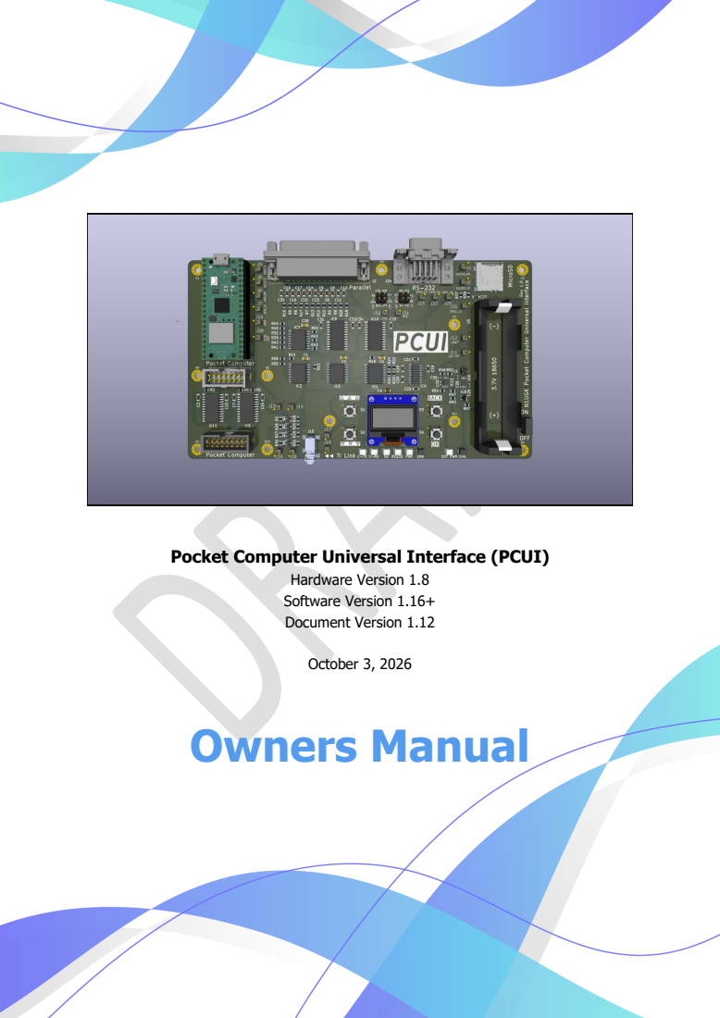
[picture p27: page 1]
Hardware Version 1.8; Software Version 1.16+; Document Version 1.12; October 3, 2026; Owners Manual

Pocket Computer Universal Interface (PCUI)

## Table of Contents

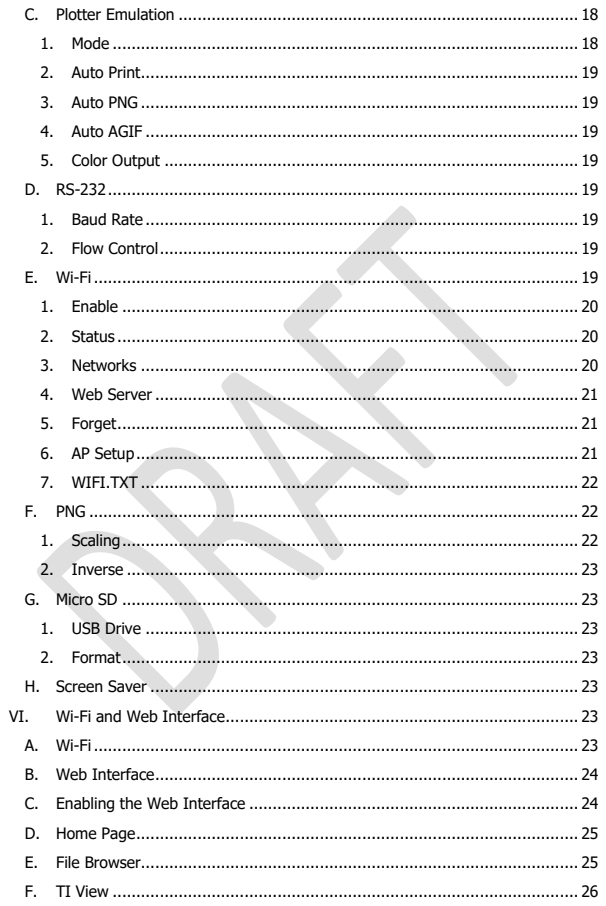
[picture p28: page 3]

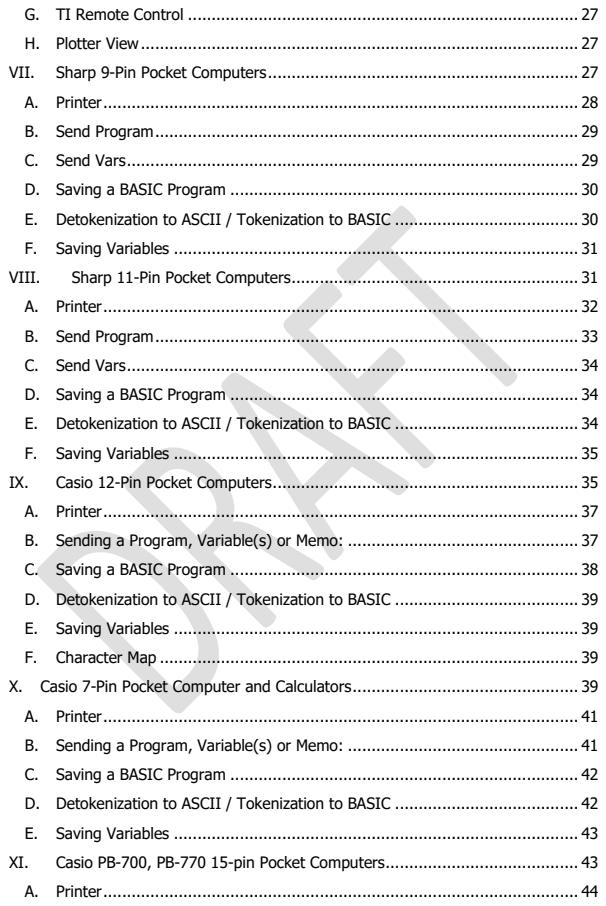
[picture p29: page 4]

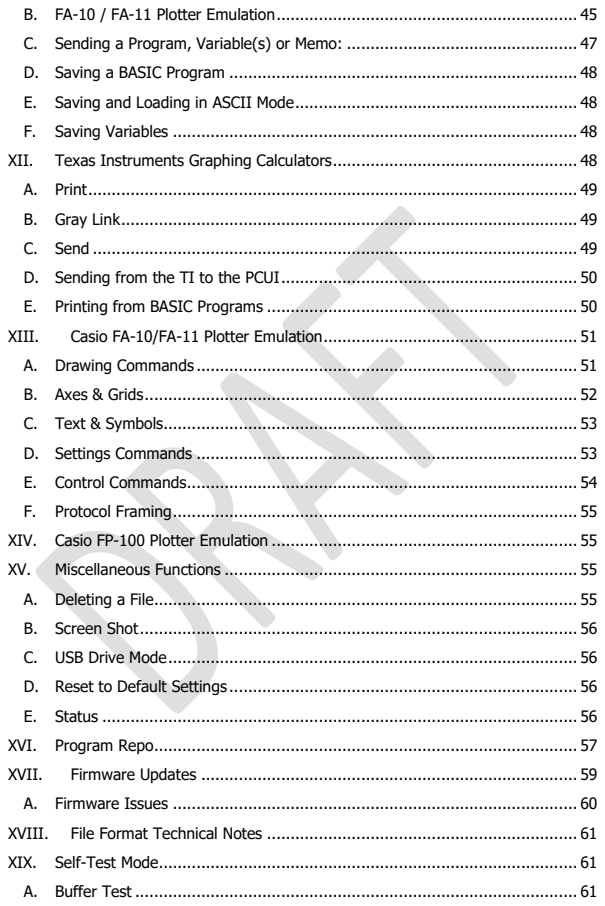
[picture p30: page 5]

I. Introduction
A. Purpose

The Pocket Computer Universal Interface (PCUI) provides a printer and storage interface for various models of vintage pocket computers and scientific / graphing calculators. Because many of these pocket computers’ printers and cassette interfaces are difficult to find these days, expensive, and use consumables that are difficult or impossible to find, the PCUI provides a modern replacement for those peripherals.

Although some pocket computers had printers which were thermal, and therefore in theory had consumables (such as the paper) still available today, others had plotters which used pens. Even though it is possible to find pens today, they are either used and potentially dried up, or will eventually dry up. Newly manufactured pens (hard to find) are made of plastic and do not work in vertical carousel plotters (such as the Casio FP-100 or the Sharp 515P, etc).

At least one pocket computer, the Casio FX-702P, used a “spark” printer, which requires aluminum coated paper, no longer made today.

For all of the reasons above, and perhaps others such as scarcity, expense, maintenance / repairs, the PCUI provides a modern printer interface to many of these vintage pocket computers and calculators.

Regarding the cassette storage options for these same pocket computers and calculators, the cassette interfaces are also sometimes difficult to find, expensive, and they are sometimes difficult to get the levels correct. Often times loads from cassette fail due to poor quality recordings, cassettes, or both.

The PCUI eliminates the frustration of loading from cassette or computers by using modern micro SD storage media. Further, edits can be made to programs on a PC or Mac, and then transferred to the pocket computer via a removable drive interface with the PCUI. The PCUI can “tokenize” or convert plain ASCII files to BASIC programs the pocket computer recognizes.

B. Features Summary
- Provides cassette interface emulation to read and write programs and data directly to and from a micro SD card.

- Provides a printer interface between the pocket computer or calculator and most standard "line printers" such as dot matrix, thermal receipt printers, serial, parallel, and Wi-Fi.
- Supports printing of custom glyphs, including math, scientific and engineering symbols unique to each model.
- Works independently without a computer and can be powered by a single 18650 lithium ion rechargeable battery.
- OLED screen with user-friendly menu system and operating modes
- Interface packs provide connectivity to each supported model, no need for OEM connection cables.
- Updatable firmware and PC or Mac connectivity via USB for mounting micro SD card
- Plotter emulation mode to provide printouts of plots using modern printers allowing programs which leveraged plotter features to be used on modern printers.
- ASCII BASIC conversion to and from tokenized BASIC "on the fly", allowing for program edits and program creation on a Mac or PC and directly sending it to a pocket computer.
- Wi-Fi connectivity and web interface for program viewing, editing, UI control, printing, and status.
- Online program library browsing and installing directly from GitHub allows you to view community released programs for various models of pocket computers directly from the PCUI.
- True low-level cassette interface integration - byte level retrieval and storage of programs and data images, not just a simple "record" and "playback" mechanism.
C. Supported Models
Brand | Model(s)
Texas Instruments | Graph Link Graphing Calculators TI-82*, TI-85*, TI-86*, TI-89*, TI-92*, TI-92 Plus*, Voyage 200*
Sharp Radio Shack | 9-Pin “CE-121” / “CE-122” Compatibles PC-1210, PC-1211, PC-1212, TRS-80 PC-1*

Sharp Tandy | Older 11-pin "CE-126P" Compatibles PC-1245, PC-1246, PC-1246S, PC-1247, PC-1248, Tandy PC-8* PC-1250, PC-1250A, PC-1251, PC-1251H, PC-1255, Tandy PC-3* and PC-3 A/B*, PC-1270
Sharp | 11-pin “CE-126P” Compatibles PC-1260, PC-1280
Sharp | Newer 11-pin "CE-126P" Compatibles PC-1401, PC-1403*, PC-1421, PC-1430, PC-1450, EL-5500, EL-5500 II, EL-5500III*
Casio Radio Shack Tandy | 12-pin PB-100 Series FP-12(S) Compatibles PB-100, PB-110, PB-120, PB-200, PB-400, PB-410*, FX-700P, FX-710P, Tandy PC-4 Version B*, TRS-80 PC-4 Version A*
Casio Tandy | 12-pin FX "Clamshell" Series FX-770P, FX-780P, FX-781P, FX-785P, FX-790P, FX-791P, FX-795P, Tandy PC-5*, Tandy PC-6*
Casio | 15-pin FA-10 / FA-11 Compatibles PB-700*, PB-770*
Casio | FX-702P*, FX-602P*

* Tested and Verified, others should work since they use the same interface

D. Parts and Components

### 1. PCUI Main PCB

The PCUI is comprised of a single main PC board (PCB) and one or more pocket computer interface pack PCBs (if applicable). The main PCB will be identified with a hardware version number – be sure the version number on your unit matches the version number of this guide.

### 2. Pocket Computer Interface Packs

Your PCUI kit might have one or more pocket computer interface packs. These packs contain a small PCB, a connector, and some have additional components. An interface pack is designed for a particular line of pocket computers that share a specific bus interface or pinout.

Use of the TTL pocket computer interface packs will plug into the 16-pin shrouded IDC style header on the main PCB. Use of the CMOS pocket computer interface packs will plug into the 14-pin shrouded IDC style header on the main PCB.

If using a Texas Instruments graphing calculator, a 2.5mm stereo jack is on the main PCB labelled TI Link. The connection cable itself is not included. Any standard “stereo” or 3 pin 2.5mm cable will work if you do not have the original Texas Instruments graph link cable.

### 3. Lithium Ion Battery

The PCUI uses an 18650 lithium ion battery for portable use. The battery itself is not included due to shipping regulations. 18650 batteries can be purchased from many online retailers such as Amazon and are very inexpensive. The PCUI can charge the battery when the PCUI is plugged into a USB port.

Note that a battery is not required for PCUI operation. If a battery is not used, then a USB based power source would be required.

### 4. Test Headers

The PCUI includes test header pin locations on the PCB which are optional. These would be useful for debugging or troubleshooting. They are convenient for attaching test leads and can be added later on if you need them.

II.Getting Started

A. Unpacking and Inspection

When you first receive your PCUI, make sure all components are intact, not damaged.

1. Inspect the packaging for any signs of damage during shipping.

2. Check that all components are present, based on the particular options you selected.
B. PCUI Main Board

The PCUI main board is shown below:

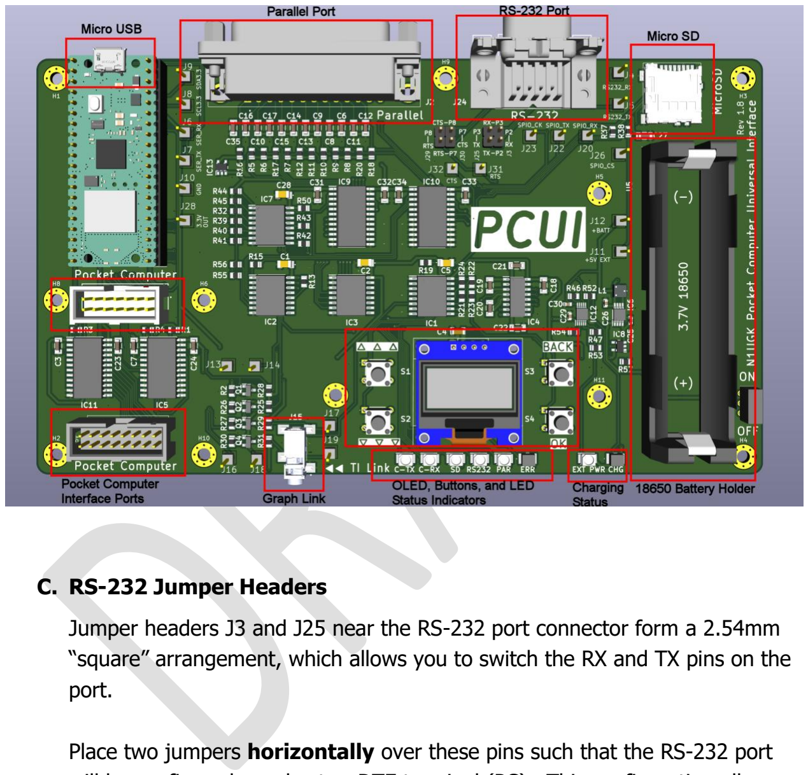
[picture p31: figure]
C. RS-232 Jumper Headers; port.

Jumper headers J3 and J25 near the RS-232 port connector form a 2.54mm “square” arrangement, which allows you to switch the RX and TX pins on the

Place two jumpers horizontally over these pins such that the RS-232 port will be configured as a host or DTE terminal (PC). This configuration allows for the use of a standard serial cable to connect between the PCUI and a serial printer or DCE device without a null modem cable.

Similarly, jumper headers J31 and J32 near the RS-232 port connector form a 2.54mm “square” arrangement, which allows you to switch the RTS and CTS pins on the port. Or, if you wish to disconnect these pins completely, remove the two jumpers.

If planning on connecting the PCUI to a PC or DTE device, or, if connecting to a printer with a null modem cable, then place the jumpers in a vertical orientation.

These jumpers allow for easy switching between DTE and DCE without the need for a null modem adapter.

III. Operation

The PCUI is designed to interface with various pocket computers and graphing calculators. Depending on the options you have chosen when purchasing your PCUI kit, some features may not be available.

Before using your PCUI, be sure to install an 18650 Lithium Ion battery (if using the PCUI in a portable environment), or, plug the PCUI into a USB power source such as a battery bank, PC, or Mac.

WARNING! Note the battery polarity indicator on the silkscreen on the PCB. Plus or positive points downward toward the OLED or near the on/off switch, whereas negative points upwards towards the micro SD holder. Irreversible damage to the PCUI and/or the battery will occur if polarity is reversed.

Also install a micro SD card into the micro SD holder. Note that the PCUI supports SDHC models only.

The OLED display is used for configuration and status of the PCUI, along with the four hotkey buttons around the OLED display provide the user interface.

Although there is labelling on the silkscreen for each of the hotkeys, depending on the context, the function of each key may change from what they are labelled as.

An example of the home screen for the Voyage 200 mode:

In this example, the upper left hotkey is for settings, the lower right hotkey is to perform a screen capture and print from the attached TI Voyage 200 graphing calculator.

WARNING! Be sure to use the correct interface pack for the pocket computer or calculator you have the mode set to and for your model! Otherwise, serious irreversible damage can be done to the PCUI and/or the attached device.

Also, be sure to plug the interface pack into the pocket computer or calculator with the correct orientation. The interface packs are labelled with direction on the silkscreen.

Lastly, be sure both devices are turned off before unplugging or plugging in any interface packs into either device.

Order of operations for powering up:

If connecting for the first time, or when switching modes (new model):

1. Start with both devices off (the PCUI and the pocket computer or calculator).
2. If you have yet to select the operating model/mode or are changing the operating mode, power up the PCUI without any interface pack plugged into the PCUI. Using the settings menu, choose the correct model from the calculator model selection.
3. Turn on the PCUI first. Double check the operating model/mode is correct.

4. Connect the interface pack to the pocket computer or calculator (device) first if it is not already connected.
5. Connect the other end of the interface pack to the PCUI.
6. Turn the pocket computer or calculator on.

Order of operations for powering down:

1. Turn off the pocket computer or calculator.
2. Turn off the PCUI.
3. Disconnect the interface pack from the PCUI (if necessary).
4. Disconnect the interface pack from the device (if necessary).

A bit of explanation is necessary for the above steps. The PCUI should always be off or the interface pack not connected to the PCUI when plugging the other end of the interface pack into the pocket computer or calculator. The reason is that many of the pocket computers have metal housing very close to where the interface pack is to be plugged into. This allows for an easy short circuit across the pins of the interface pack, which would damage the PCUI TTL buffer.

As a reminder, the green LED on the calculator side of the interface pack lights up when it is connected to the PCUI and the PCUI is turned on. Never plug in or unplug the interface pack to/from the calculator when the green LED is lit.

In addition, selecting the incorrect mode or model on the PCUI with a calculator connected can cause damage to either the PCUI and/or the calculator – the reason this is possible is different models have different pins assigned to inputs and outputs. If two outputs are connected, one or the other can be damaged. Starting up the PCUI without being connected to any calculator ensures that the correct mode is selected before making a connection.

The reason for powering up the PCUI first, before the pocket computer or calculator is this follows the same order as most instruction manuals for the printer and cassette interfaces designed for the pocket computer or calculator.

These precautions and process are important for the PCUI, since it is a multi-use device, not dedicated to any particular model.

IV. Battery Charging Circuit

The PCUI has a battery charging management circuit that will automatically charge an 18650 lithium ion battery. Avoid using other types of batteries as these may not be compatible with the charging profile assumed in the management IC.

There are two LEDs that indicate the charger circuit status:

A. EXT PWR

This LED indicates external power is connected to the USB port on the PCUI. This indicates power is available for the charging circuit.

B. CHG

This LED indicates the battery is currently being charged. It is recommended to leave the USB power connected until this indicator turns off – this way the battery receives a full constant current charge stage AND a constant voltage stage. Interrupting the charging cycle may not provide the best conditioning possible for the lithium ion battery. The charge cycle is completed when this indicator turns off.

V. Settings

The PCUI settings need to be configured based on the calculator you are connecting it to and the peripherals you have attached, such as a printer. The settings menu can be accessed from the home screen:

The settings screens combine pick lists and other interfaces to select or change options. The UP/DOWN hotkeys change the selection of a picklist, while the OK hotkey can be used for either selection of a choice in the list, or continuing onward to the next submenu. The BACK hotkey will jump back to the previous screen or menu.

A. Calc Model

Before using the PCUI, the calculator model must be chosen. This choice drives the functionality of the rest of the PCUI and making a selection here first may open other menus or choices which can be set later.

If using a TI graphing calculator, be sure to use the TI Link connector on the PCUI. If using any other supported pocket computer, use the Pocket Computer header for connection to your device and the appropriate connection pack.

B. Printer

If you wish to use a printer with the PCUI, choose a type of printer you are attaching. However, if you are not using a printer, be sure to set this choice to None. This will prevent lockups or attempts by the PCUI to print to an attached printer.

### 1. Type

The Generic printer choice should be chosen for any standard line printer which does not have any specific emulation support. Most vintage printers accept standard ASCII bytes for printing, and this should be selected for those printers.

The ESC/POS choice is for Epson ESC/POS thermal receipt printers.

The ProPrinter X24 choice should be chosen if your printer supports this emulation mode, while the Epson LQ choice is similarly available.

### 2. Port

You can attach either a parallel, serial, or Wi-Fi printer to the PCUI. Make your selection accordingly for the Port. Note that if you select RS-232, be sure to set the RS-232 parameters under the RS-232 settings menu.

If printing to a Wi-Fi printer, be sure it’s model is supported first, in the Type list, such as LaserJet, then be sure Wi-Fi is enabled first.

The PCUI will scan for printers using mDNS. Pick from the available list:

### 3. Pixel Width

This sets the horizontal pixel width of the attached printer. For ESC/POS this would be 512, for an IBM ProPrinter compatible, this would be 2880.

### 4. Scaling

Depending on the width of your printer and its graphics density, you may wish to increase the scaling or output size for the printouts. Note that a selection here does not guarantee your printer can print to the scale you choose. The PCUI will automatically limit the scaling accordingly.

### 5. Transpose

This option will rotate the printout by 90 degrees. Depending on the attached printer and paper size, this rotation results in a larger printout in most cases.

### 6. Auto Cut

This option will send the paper cut command to the printer once a screen shot is done printing. Note this is relevant only to models which support screen shots and the ESC/POS printer types.

### 7. Char Size

Because many vintage pocket computer printers had relatively small paper width and characters per row (20 chars for example), if using a larger printer on the PCUI with a wider character per row capability, you can increase the font or character size of the printer output if desired. A good setting here would be 2.

### 8. Hex Translation

Because many vintage pocket computers have limited capability to output bytes outside the printable output character range, such as 0x00, 0x25, etc. The result is some pocket computers cannot make use ESC/POS commands, or plotter escape sequences, or other control codes.

If enabled, the PCUI will intercept an escape sequence of “?X” and what follows is hexadecimal format of the bytes to send out to the attached printer. An example would be that the bytes 0x1C 0x25 are required for the Casio FA-10 plotter to switch to plotter mode. A Sharp PC-1401 cannot send these characters out over the printer port, they come over as 0x20. But, the Sharp PC-1401 can send “?X1C25” and the PCUI will see this and send 0x1C 0x25 out to the printer port.

### 9. Debug Mode

If you are seeing mismatched character outputs between an attached pocket computer, calculator or graphing calculator and the attached printer, enabling debug mode will output the character code in hex along with the character to help determine what characters are actually being sent to the attached printer.

### 10. Char Delay

If you are seeing errors printing such as buffer overflow, missed characters, or printer error messages, this may be due to a printer which is asserting the busy flag and the PCUI is missing it and overflowing the printer’s buffer. Enabling the char delay option will force the PCUI to pause between characters for the delay you specify here.

C. Plotter Emulation

The PCUI can emulate a plotter, such as the Casio FA-10/FA-11 for example. If this feature is enabled, and the attached pocket computer sends plotter commands, the PCUI will capture and process those commands in memory on a virtual canvas, and then print the result when character mode is enabled again.

### 1. Mode

This disables plotter emulation or enables the emulation for a given type of plotter.

### 2. Auto Print

If set to Yes, when the return to character mode plotter command is received, the virtual canvas will be printed to the attached printer.

### 3. Auto PNG

If set to Yes, when the return to character mode plotter command is received, the virtual canvas will be saved to the micro SD card as a PNG file. This will function even if you no not have a graphics capable printer attached, or no printer selected at all.

### 4. Auto AGIF

If set to Yes, when the return to character mode plotter command is received, the virtual canvas will be saved to the micro SD card as an animated GIF file. This will function even if you no not have a graphics capable printer attached, or no printer selected at all.

### 5. Color Output

If set to Yes, the PCUI will render the saved PNG and AGIF in color, according to the pen(s) selected during plotting. If you see memory overflow errors, set this to B&W.

D. RS-232

### 1. Baud Rate

If you wish to use a serial printer with the PCUI, set the appropriate baud rate here. Or, if you are using the PCUI RS-232 port for another function, the baud rate should be set appropriately.

### 2. Flow Control

If you wish to use hardware flow control, enable the RTS/CTS option. Otherwise, you can leave this disabled.

E. Wi-Fi

The PCUI can connect to a Wi-Fi network to get the current date and time as well as fetch programs and data from an online repository. If Wi-Fi is enabled and the PCUI is able to fetch the time and date, file(s) written to the micro SD card will use the current date and time value, otherwise no date and time will be stamped on files written to the micro SD card.

If Wi-Fi is enabled and the PCUI is connected to the Wi-Fi network, then the green LED will illuminate on the Pico 2 W. It will then blink with Wi-Fi activity.

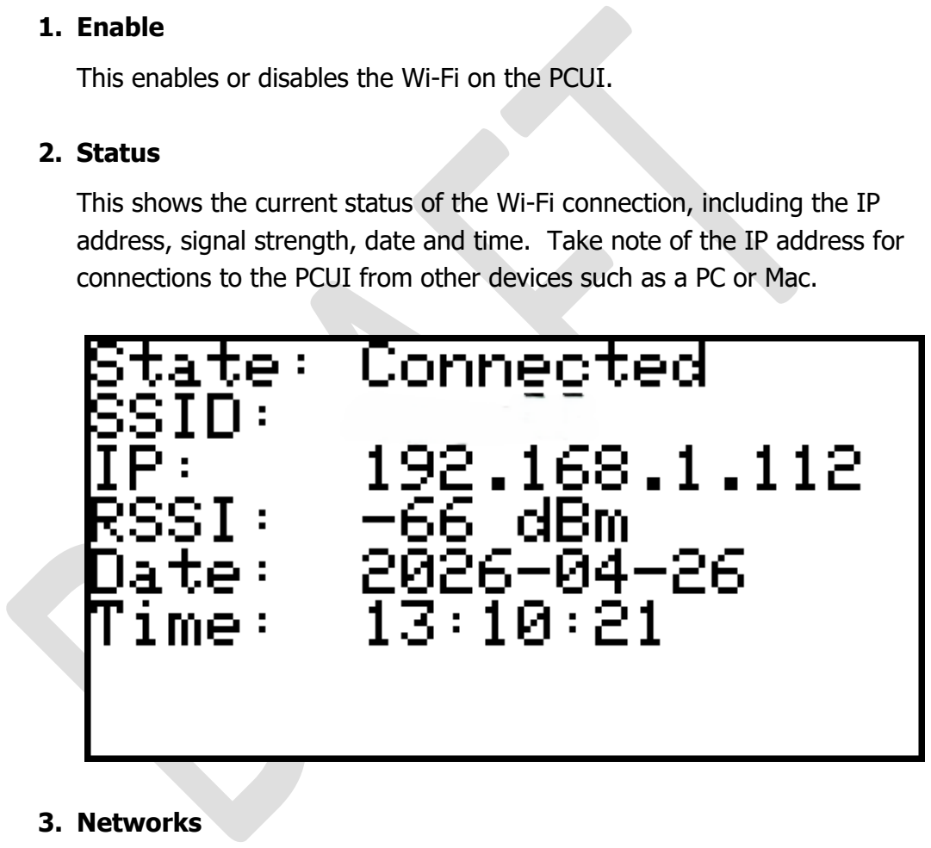
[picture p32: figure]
1. Enable; 2. Status; 3. Networks

This enables or disables the Wi-Fi on the PCUI.

This shows the current status of the Wi-Fi connection, including the IP address, signal strength, date and time. Take note of the IP address for connections to the PCUI from other devices such as a PC or Mac.

This is where you select a Wi-Fi network to join. The screen will show current visible networks. Scroll down to select the network you want to connect to. A password entry screen will then appear.

Note that the Wi-Fi password will be stored on the micro SD card. AES encryption is used to prevent casual viewing of the password should the SD card be removed and read. Further, the encryption key is tied to the unique device ID (Pico W in the PCUI), the password cannot be read in another PCUI.

Note that if Wi-Fi is enabled and authentication fails, the ERR LED will be illimunated.

Note: The PCUI will appear on your network as “PCUI”. You can find the IP address assigned to the PCUI on the Status screen.

### 4. Web Server

The PCUI has a basic web interface, if you wish to enable this feature, you can do so here.

### 5. Forget

Choosing this option will disconnect from the current Wi-Fi network and no longer connect automatically. The stored password will be removed.

### 6. AP Setup

Due to the limited screen size and lack of proper keyboard on the PCUI, it might be easier to use the AP Setup option. If you choose this option, the PCUI will become a WiFi access point. Using your PC, Mac, or smartphone, connect to the PCUI’s WiFi network, using the SSID and password shown on the display.

Your PC, Mac, or smartphone should direct you to the PCUI’s web setup page where you can enter the SSID and password of your WiFi network. Once you click Save, the PCUI will store this information, disable it’s access point network, and connect to your WiFi network.

If your PC, Mac, or smartphone do not automatically direct you to the PCUI’s web setup page, open a browser and go to the IP address shown on the OLED, which should be http://192.168.4.1.

### 7. WIFI.TXT

Due to the limited screen size and lack of proper keyboard on the PCUI, it might be easier to mount the SD card to an attached computer, provide the SSID and password in a text file, and have the PCUI load this information on startup.

To mount the SD card, either remove it from the PCUI and mount it directly in your computer, or, connect the PCUI via USB to your computer and simultaneously press the Back and Ok buttons to mount the drive over USB.

Create a WIFI.TXT file with the first line being the SSID of your Wi-Fi network and the second line being the password for your Wi-Fi network. Save the file and unmount the USB drive. The PCUI will read the WIFI.TXT file and update it’s internal configuration accordingly, then it will delete the WIFI.TXT file.

F. PNG

The PCUI can write screen shots or other outputs to the micro SD card. This menu allows changing the scaling of the PNG files generated as well as other options.

### 1. Scaling

This sets the scale for the captured PNG image(s).

### 2. Inverse

The PNG can be inverted such that the “on” pixels are black on a white background. If this is enabled, a black border is added to the screen capture.

G. Micro SD

The PCUI can write screen shots or other outputs to the micro SD card. The micro SD card will be used to store saved programs and data as well.

### 1. USB Drive

If the PCUI is plugged into a PC or Mac, the USB Drive feature will present the micro SD card as a USB Drive. You can then copy files, screen shots, or other data to and from the micro SD card.

### 2. Format

This will format the micro SD card, which erases all contents.

H. Screen Saver

During extensive testing and prototyping for the PCUI, it was discovered that many, if not all of the OLED screens used had experienced at least a minor form of “burn in” where the home screen LED pixels were slightly dimmer than pixels that were not on for the home screen. This is particularly noticeable during the self-test when the OLED is inverted.

It is recommended that the screen saver be enabled, which will engage after 5 minutes of no activity. Pressing any button will cancel the screen saver. In addition, any attached device with bus activity will also cancel the screen saver.

If this is not desirable, the screen saver can be disabled. Further, there are several “effects” you can choose from.

VI. Wi-Fi and Web Interface

A. Wi-Fi

The PCUI can connect to a Wi-Fi network for various functions, mainly for getting the current date and time. This is useful for the micro SD card writes, as without the date and time, all files modified or created on the SD card will be without a timestamp.

B. Web Interface

The PCUI provides a web interface for status, program viewing and editing, and more. In order to use the web interface, a standard browser is required. Wi-Fi must be enabled in order for the web interface to be enabled.

C. Enabling the Web Interface

To use the web interface, enable Wi-Fi and web server options in the settings menus. The PCUI will connect to the Wi-Fi network and request an IP address via DHCP. Then, browse to the IP address shown on the Wi-Fi status screen:

When Wi-Fi is enabled, mDNS is active and the PCUI will broadcast it’s device name as “device name”.local, and in the example above, the name would be PCUI-476dc70e.local, and therefore you can access the PCUI web interface at http://PCUI-476dc70e.local. Note that your router must allow mDNS and your device (Mac, PC, etc) must support mDNS – if not, simply use the IP address shown, such as http://192.168.1.199. Note that your router may have a different name for your network than “local”.

D. Home Page

The web interface has a navigation bar at the top indicating the device name along with the current firmware build, and navigation buttons to the right.

The home page includes a “live” view of the PCUI’s OLED display, along with the four interface buttons located around the display.

E. File Browser

The web interface includes a file browser which allows deleting, renaming, creation, and editing of programs.

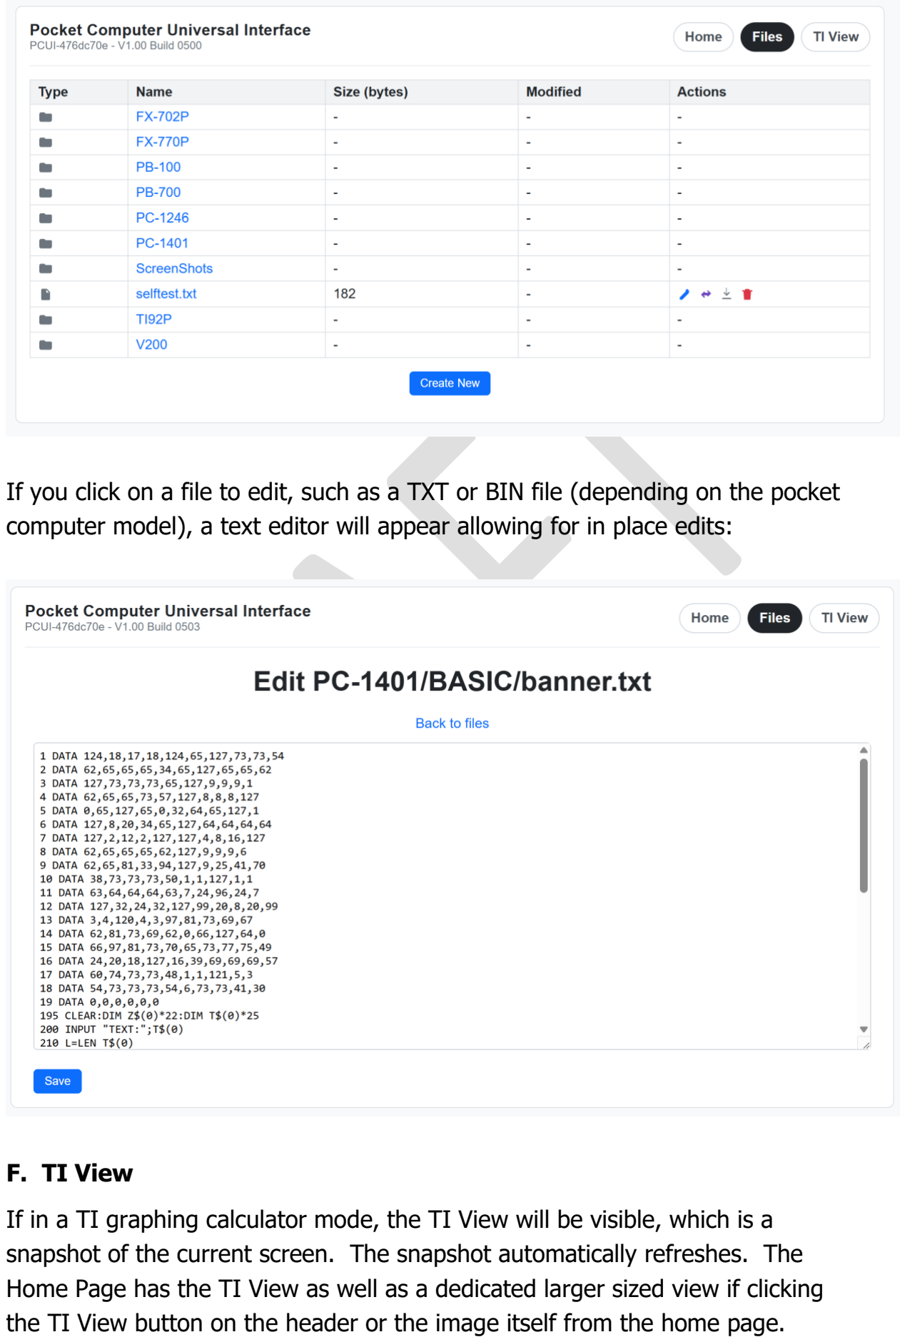
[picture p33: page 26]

If you click on a file to edit, such as a TXT or BIN file (depending on the pocket computer model), a text editor will appear allowing for in place edits:

F. TI View

If in a TI graphing calculator mode, the TI View will be visible, which is a snapshot of the current screen. The snapshot automatically refreshes. The Home Page has the TI View as well as a dedicated larger sized view if clicking the TI View button on the header or the image itself from the home page.

G. TI Remote Control

The PCUI will accept characters while typing with this page open, and translate and send them to the attached TI, such as the TI-92, TI-92+ and Voyage 200. Keys such as the arrow keys, F-keys, enter, backspace, and others have the required mapping to the TI remote keypress.

H. Plotter View

If the PCUI is currently in plotter mode (if plotter emulation is enabled), Plotter View will be available, which will show the current plotting progress (PB-700 mode only), and when plotting is completed, the PNG of the plot will be displayed.

VII. Sharp 9-Pin Pocket Computers

PC-1210, PC-1211*, TRS-80 Pocket Computer* / PC-1*

The asterisks indicate actual testing was done on these models. Other models mentioned use the same peripherals and should also be compatible.

For all models mentioned above, select PC-1211. A subfolder named “PC-1211” will be used as the root directory for all micro SD card functions for these models.

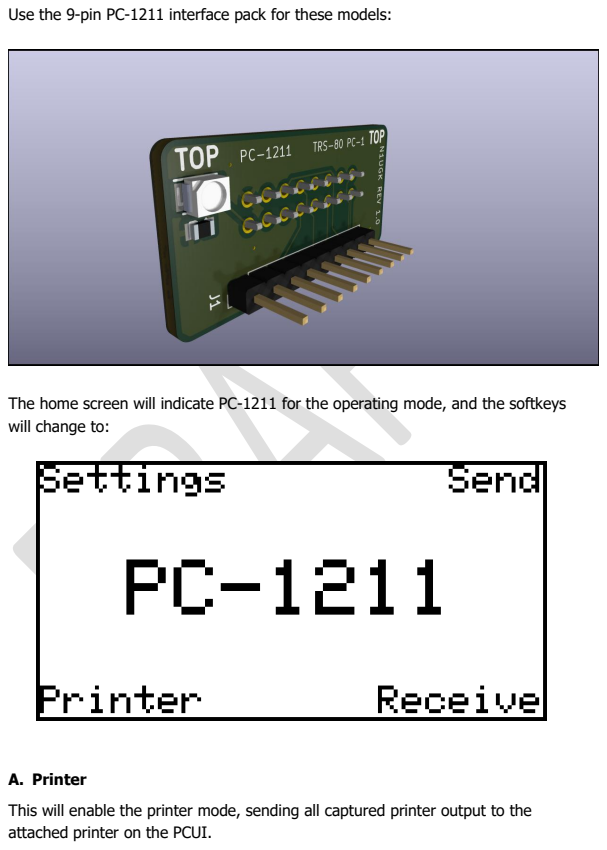
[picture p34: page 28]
A. Printer

Use the 9-pin PC-1211 interface pack for these models:

The home screen will indicate PC-1211 for the operating mode, and the softkeys
will change to:

This will enable the printer mode, sending all captured printer output to the
attached printer on the PCUI.

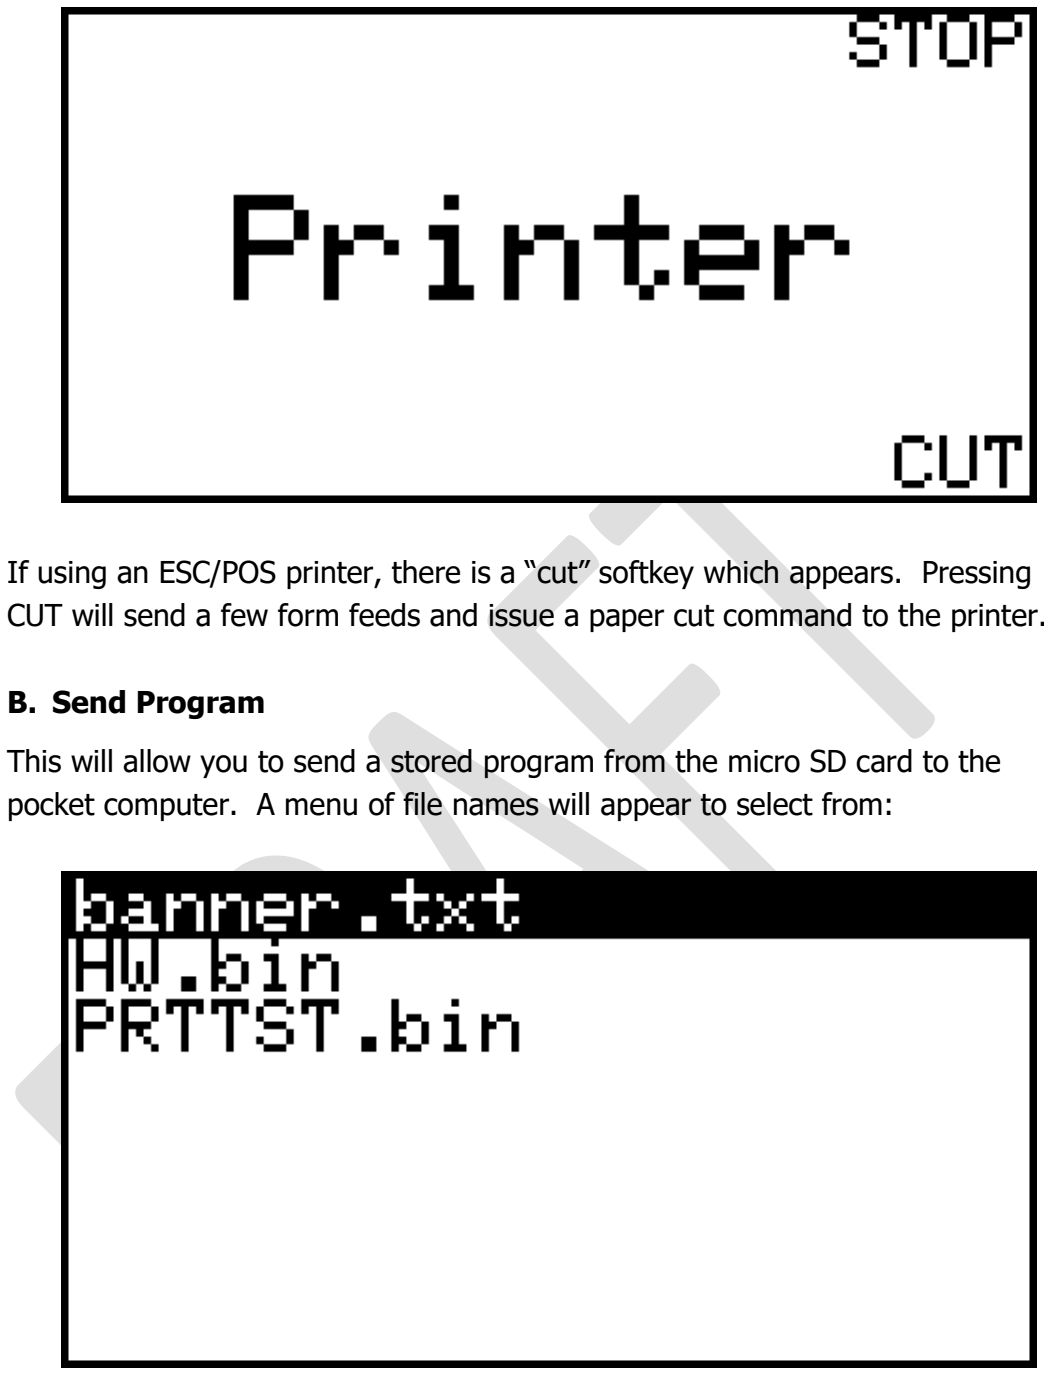
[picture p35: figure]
B. Send Program

If using an ESC/POS printer, there is a “cut” softkey which appears. Pressing CUT will send a few form feeds and issue a paper cut command to the printer.

This will allow you to send a stored program from the micro SD card to the pocket computer. A menu of file names will appear to select from:

Be sure to type CLOAD and enter on the pocket computer before sending a program. The file name for CLOAD on the pocket computer is required. For example CLOAD”BANNER”. The pocket computer will compare the file name you specify with the file name sent by the PCUI. If they do not match, then the pocket computer will not accept the incoming file.

C. Send Vars

This will allow you to send stored variables from the micro SD card to the pocket computer. A menu of file names will appear to select from:

Be sure to type INPUT#, the file name, and enter on the pocket computer before sending variable contents. The file name for INPUT# on the pocket computer is required. For example, INPUT#”BANMEM”. The pocket computer will compare the file name you specify with the file name sent by the PCUI. If they do not match, then the pocket computer will not accept the incoming file.

D. Saving a BASIC Program

To save a BASIC program to the micro SD card, press the Receive softkey on the PCUI, then type CSAVE, the file name, and enter on the pocket computer.

The file name for CSAVE on the pocket computer is required. For example, CSAVE”BANNER”.

E. Detokenization to ASCII / Tokenization to BASIC

Any BASIC program saved on the micro SD card as a BIN file will be automatically detokenized from BIN format to ASCII format and saved with the same name as a .txt file. This is the BASIC source and allows for easy viewing and editing via the web interface or if mounting the SD card as removable storage on a PC or Mac.

When sending a file to the pocket computer, if you select a .txt file, which should be an ASCII BASIC file, the PCUI will tokenize the file on the fly and send it to the pocket computer in a tokenized BASIC format. This allows you to create or edit a program using the web interface or if mounting the SD card as removable storage on a PC or Mac and send it without needing to convert it first.

F. Saving Variables

To save the variable contents on the pocket computer to the micro SD card, press the Receive softkey on the PCU, then type PRINT#, the file name, then enter on the pocket computer.

The file name for PRINT# on the pocket computer is required. For example, PRINT#”BANMEM”.

VIII.Sharp 11-Pin Pocket Computers

PC-1245, PC-1246*, PC-1246S, PC-1247, PC-1248, Tandy PC-8*
PC-1250 Tandy PC-3 and PC-3 A*, PC-1250A Tandy PC-3 B*, PC-1251, PC-1251H, PC-1255, PC-1270

The asterisks indicate actual testing was done on these models. Other models mentioned use the same peripherals and should also be compatible.

For all models mentioned above, select PC-1245 (the first in this series of pocket computers). A subfolder named “PC-1245” will be used as the root directory for all micro SD card functions for these models.

PC-1260, PC-1280

For all models mentioned above, select PC-1260 or PC-1280. A subfolder named “PC-1260” or “PC-1280” will be used as the root directory for all micro SD card functions for these models.

PC-1401, PC-1402, PC-1403*, EL-5500, EL-5500 II, EL-5500 III*

The asterisks indicate actual testing was done on these models. Other models mentioned use the same peripherals and should also be compatible.

For all models mentioned above, select PC-1401 (the first in this series of pocket computers). A subfolder named “PC-1401” will be used as the root directory for all micro SD card functions for these models.

Use the 11-pin PC-124x interface pack for these models:

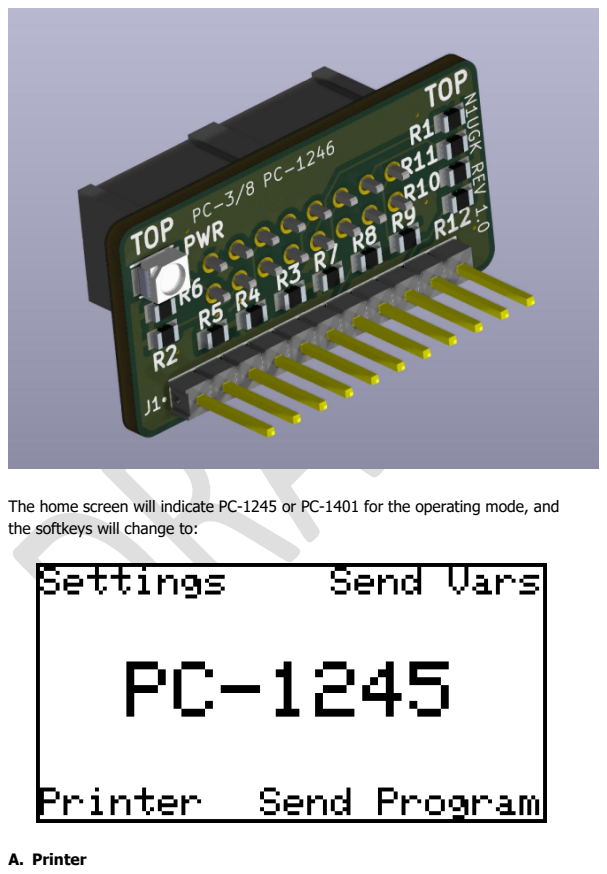
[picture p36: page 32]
A. Printer

The home screen will indicate PC-1245 or PC-1401 for the operating mode, and
the softkeys will change to:

This will enable the printer mode, sending all captured printer output to the attached printer on the PCUI.

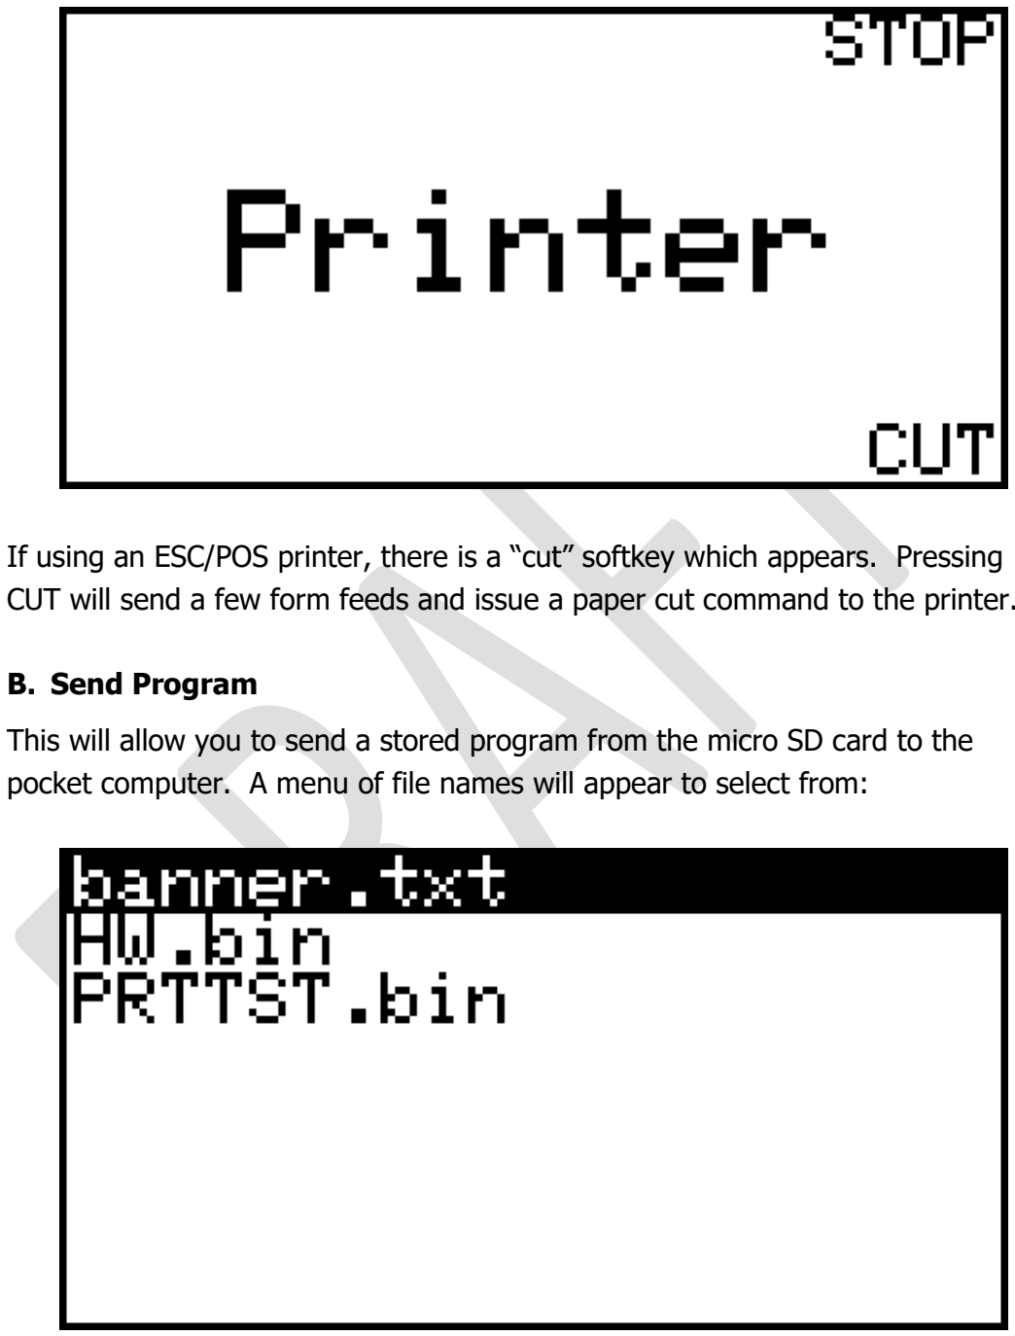
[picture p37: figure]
B. Send Program

If using an ESC/POS printer, there is a “cut” softkey which appears. Pressing CUT will send a few form feeds and issue a paper cut command to the printer.

This will allow you to send a stored program from the micro SD card to the pocket computer. A menu of file names will appear to select from:

Be sure to type CLOAD and enter on the pocket computer before sending a program. The file name for CLOAD on the pocket computer is optional. If you specify a file name, then the pocket computer will compare the file name you specify with the file name sent by the PCUI. If they do not match, then the pocket computer will not accept the incoming file.

C. Send Vars

This will allow you to send stored variables from the micro SD card to the pocket computer. A menu of file names will appear to select from:

Be sure to type INPUT# and enter on the pocket computer before sending variable contents. The file name for INPUT# on the pocket computer is optional. If you specify a file name, then the pocket computer will compare the file name you specify with the file name sent by the PCUI. If they do not match, then the pocket computer will not accept the incoming file.

D. Saving a BASIC Program

To save a BASIC program to the micro SD card, type CSAVE and enter on the pocket computer. Be sure to do this only when the PCUI is on the home screen, not when printer mode or any other menu or function is being displayed.

The file name for CSAVE on the pocket computer is optional. If you specify a file name, then the PCUI will save the incoming BASIC program onto the micro SD card with the name you specify. If you do not specify a file name, the PCUI will name the file BAS_xxx where xxx is a sequential number.

E. Detokenization to ASCII / Tokenization to BASIC

Any BASIC program saved on the micro SD card as a BIN file will be automatically detokenized from BIN format to ASCII format and saved with the same name as a .txt file. This is the BASIC source and allows for easy viewing and editing via the web interface or if mounting the SD card as removable storage on a PC or Mac.

When sending a file to the pocket computer, if you select a .txt file, which should be an ASCII BASIC file, the PCUI will tokenize the file on the fly and send it to the pocket computer in a tokenized BASIC format. This allows you to create or edit a program using the web interface or if mounting the SD card as removable storage on a PC or Mac and send it without needing to convert it first.

F. Saving Variables

To save the variable contents on the pocket computer to the micro SD card, type PRINT# and enter on the pocket computer. Be sure to do this only when the PCUI is on the home screen, not when printer mode or any other menu or function is being displayed.

The file name for PRINT# on the pocket computer is optional. If you specify a file name, then the PCUI will save the incoming variable contents onto the micro SD card with the name you specify. If you do not specify a file name, the PCUI will name the file mem_xxx where xxx is a sequential number.

IX. Casio 12-Pin Pocket Computers

12-pin PB-100 Series FP-12(S) Compatibles

PB-100, PB-110, PB-120, PB-200, PB-400, PB-410*, FX-700P, FX-710P, Tandy PC-4 Version B*, TRS-80 PC-4 Version A*

The asterisks indicate actual testing was done on this model. Other models mentioned use the same peripherals and should also be compatible.

For all models mentioned here, select PB-100 (the first in this series of pocket computers). A subfolder named “PB-100” will be used as the root directory for all micro SD card functions for these models.

FX-770P, FX-780P, FX-781P, FX-785P, FX-790P, FX-791P, FX-795P, Tandy PC-5*, Tandy PC-6*

The asterisks indicate actual testing was done on this model. Other models mentioned use the same peripherals and should also be compatible.

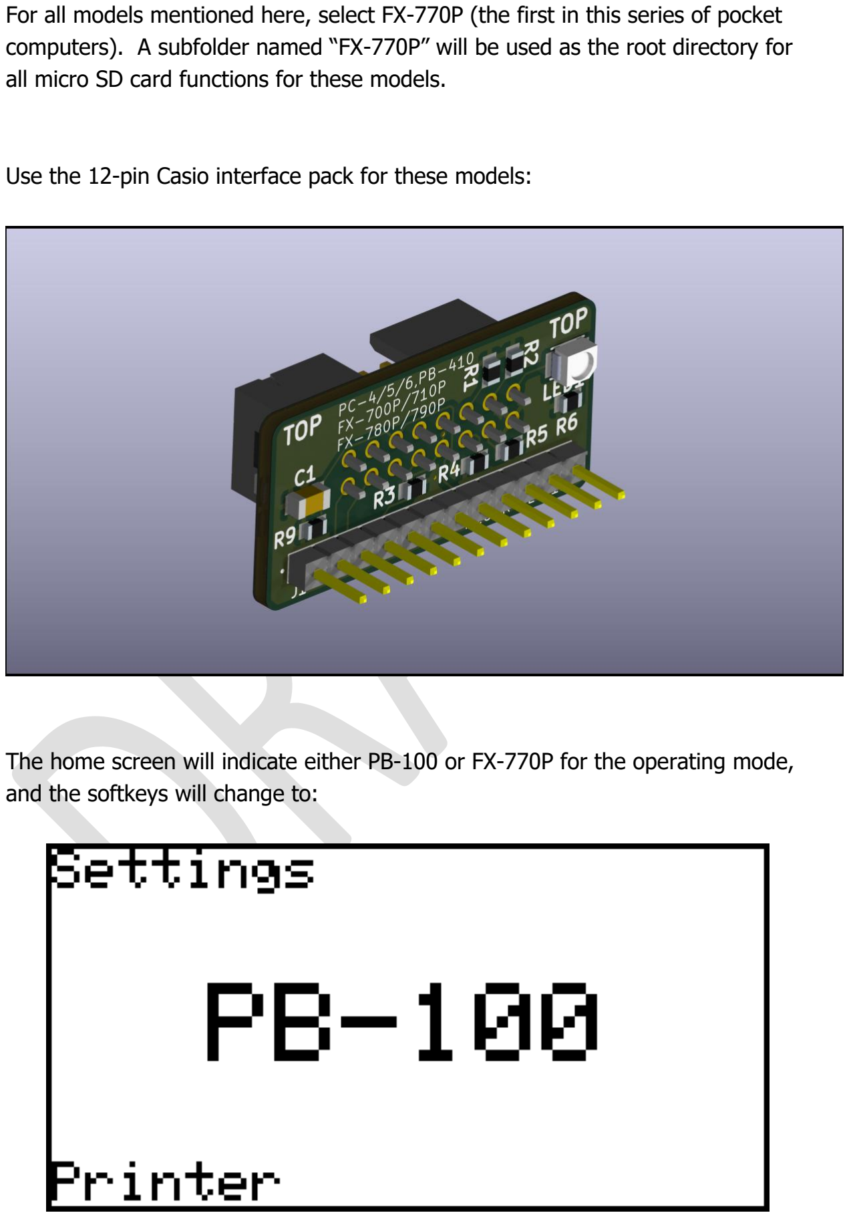
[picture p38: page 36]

For all models mentioned here, select FX-770P (the first in this series of pocket computers). A subfolder named “FX-770P” will be used as the root directory for all micro SD card functions for these models.

Use the 12-pin Casio interface pack for these models:

The home screen will indicate either PB-100 or FX-770P for the operating mode, and the softkeys will change to:

A. Printer

This will enable the printer mode, sending all captured printer output to the attached printer on the PCUI.

It should be noted that the Casio FP-12S printer (and it’s variants) had a maximum of 20 characters per line. However, there is no forced carriage return on the bus protocol for these pocket computers after 20 characters. Your BASIC programs can use the full width of the attached printer, beyond 20 characters. If using an ESC/POS printer, there is a “cut” softkey which appears. Pressing CUT will send a few form feeds and issue a paper cut command to the printer.

B. Sending a Program, Variable(s) or Memo:

This will allow you to send a stored program, variables, or memos from the micro SD card to the pocket computer. To initiate the transfer, type LOAD or GET on the PB-100. The PCUI will detect the status on the bus and automatically open the send menu:

Select the appropriate type of file to send (based on your LOAD/GET command) and then a menu of file names will appear to select from:

The file name for LOAD or GET on the pocket computer is optional. If you specify a file name, then the pocket computer will compare the file name you specify with the file name sent by the PCUI. If they do not match, then the pocket computer will not accept the incoming file.

C. Saving a BASIC Program

To save a BASIC program to the micro SD card, type SAVE and enter on the pocket computer. Be sure to do this only when the PCUI is on the home screen, not when printer mode or any other menu or function is being displayed.

The file name for SAVE on the pocket computer is optional. If you specify a file name, then the PCUI will save the incoming BASIC program onto the micro SD card with the name you specify. If you do not specify a file name, the PCUI will name the file BAS_xxx where xxx is a sequential number.

D. Detokenization to ASCII / Tokenization to BASIC

Any BASIC program saved on the micro SD card as a BIN file will be automatically detokenized from BIN format to ASCII format and saved with the same name as a .txt file. This is the BASIC source and allows for easy viewing and editing via the web interface or if mounting the SD card as removable storage on a PC or Mac.

When sending a file to the pocket computer, if you select a .txt file, which should be an ASCII BASIC file, the PCUI will tokenize the file on the fly and send it to the pocket computer in a tokenized BASIC format. This allows you to create or edit a program using the web interface or if mounting the SD card as removable storage on a PC or Mac and send it without needing to convert it first.

E. Saving Variables

To save the variable contents on the pocket computer to the micro SD card, type PUT and enter on the pocket computer. Be sure to do this only when the PCUI is on the home screen, not when printer mode or any other menu or function is being displayed.

The file name for PUT on the pocket computer is optional. If you specify a file name, then the PCUI will save the incoming variable contents onto the micro SD card with the name you specify. If you do not specify a file name, the PCUI will name the file mem_xxx where xxx is a sequential number.

F. Character Map

There are some characters in these models which do not have a direct ASCII mapping for line printers. If using an ESC/POS printer, these characters from the Casio character set will automatically be defined as custom characters in the ESC/POS printer attached.

X. Casio 7-Pin Pocket Computer and Calculators

FX-501P, FX-502P*, FX-601P, FX-602P*, FX-603P, FX-702P*

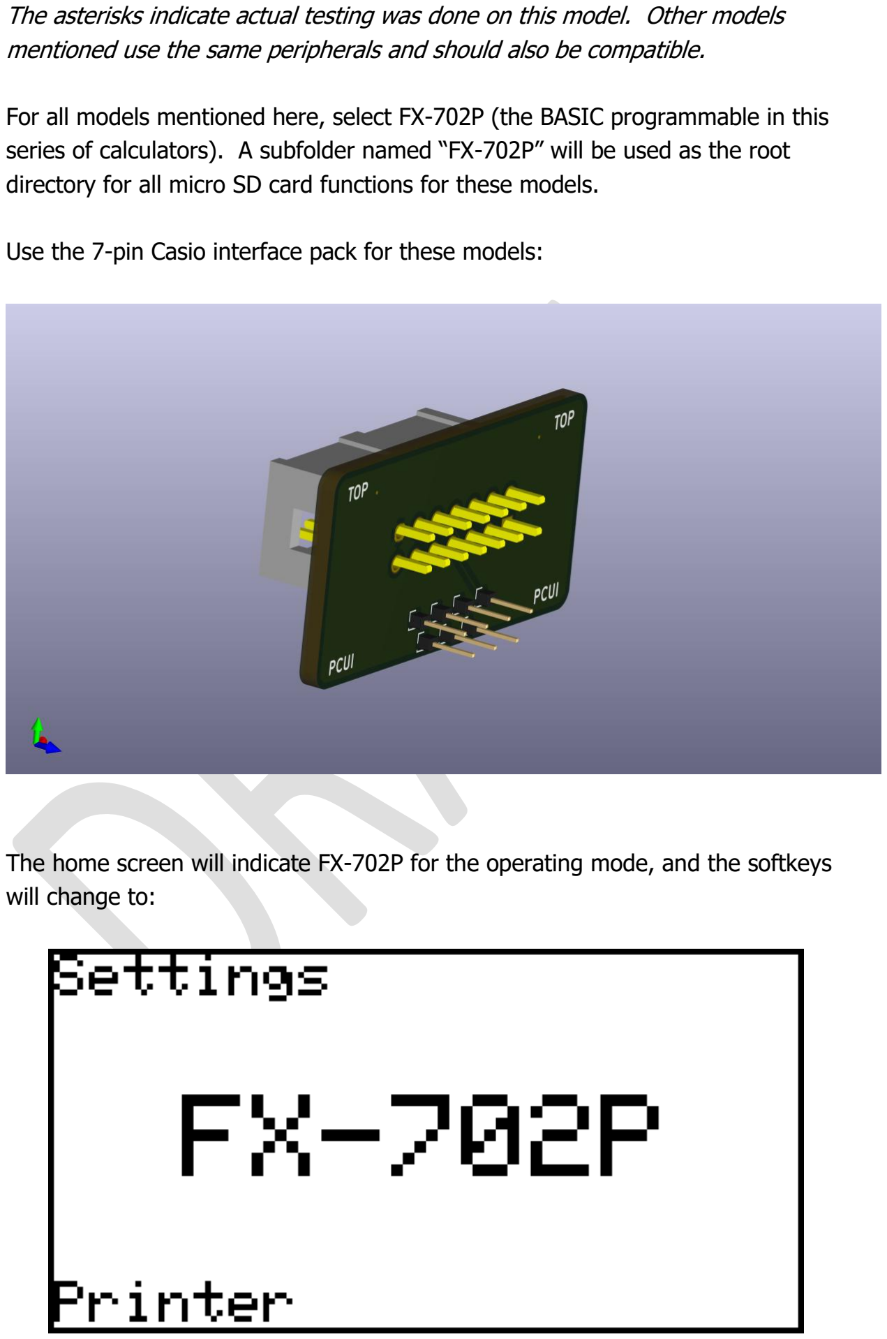
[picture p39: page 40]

The asterisks indicate actual testing was done on this model. Other models mentioned use the same peripherals and should also be compatible.

For all models mentioned here, select FX-702P (the BASIC programmable in this series of calculators). A subfolder named “FX-702P” will be used as the root directory for all micro SD card functions for these models.

Use the 7-pin Casio interface pack for these models:

The home screen will indicate FX-702P for the operating mode, and the softkeys will change to:

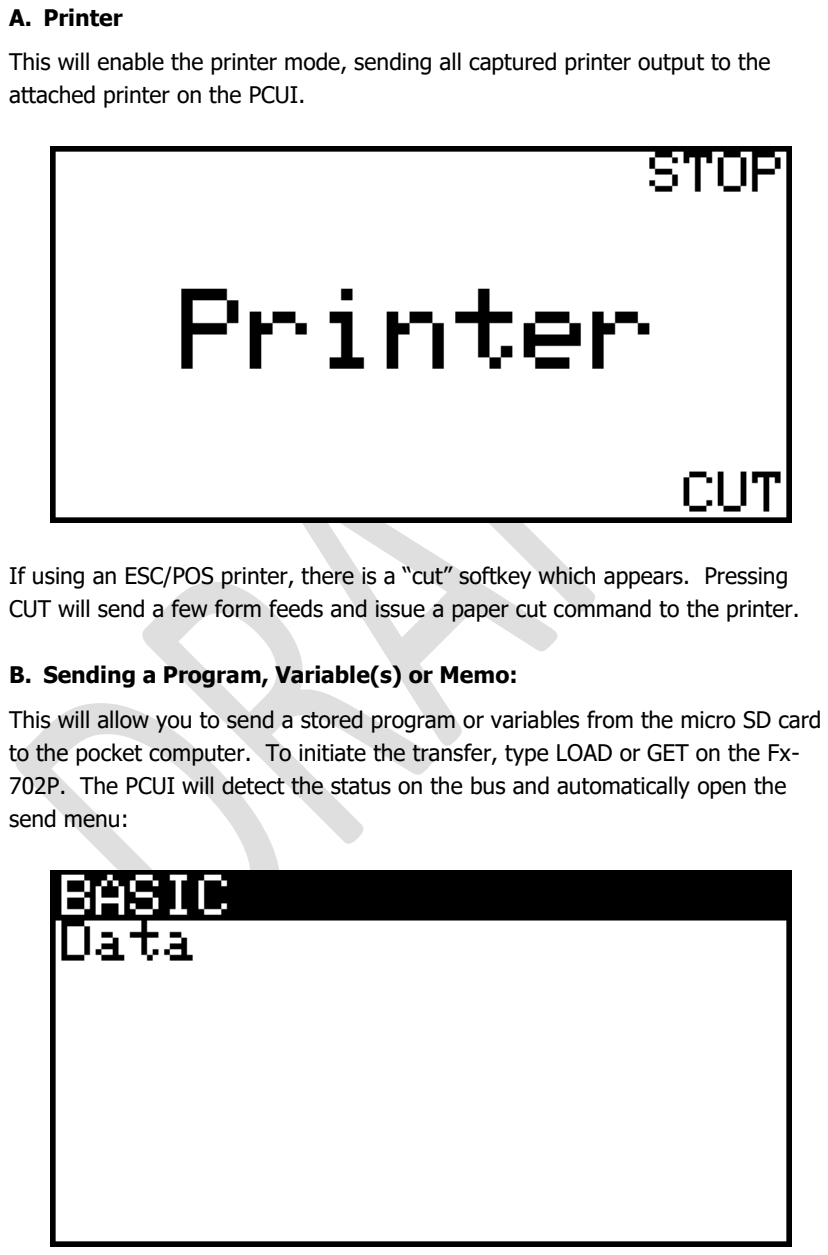
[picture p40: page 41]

A. Printer

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

B. Sending a Program, Variable(s) or Memo:

This will allow you to send a stored program or variables from the micro SD card to the pocket computer. To initiate the transfer, type LOAD or GET on the Fx-702P. The PCUI will detect the status on the bus and automatically open the send menu:

Select the appropriate type of file to send (based on your LOAD/GET command) and then a menu of file names will appear to select from:

The file name for LOAD or GET on the pocket computer is optional. If you specify a file name, then the pocket computer will compare the file name you specify with the file name sent by the PCUI. If they do not match, then the pocket computer will not accept the incoming file.

C. Saving a BASIC Program

To save a BASIC program to the micro SD card, type SAVE and enter on the pocket computer. Be sure to do this only when the PCUI is on the home screen, not when printer mode or any other menu or function is being displayed.

The file name for SAVE on the pocket computer is optional. If you specify a file name, then the PCUI will save the incoming BASIC program onto the micro SD card with the name you specify. If you do not specify a file name, the PCUI will name the file BAS_xxx where xxx is a sequential number.

D. Detokenization to ASCII / Tokenization to BASIC

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

E. Saving Variables

To save the variable contents on the pocket computer to the micro SD card, type PUT and enter on the pocket computer. Be sure to do this only when the PCUI is on the home screen, not when printer mode or any other menu or function is being displayed.

The file name for PUT on the pocket computer is optional. If you specify a file name, then the PCUI will save the incoming variable contents onto the micro SD card with the name you specify. If you do not specify a file name, the PCUI will name the file mem_xxx where xxx is a sequential number.

XI. Casio PB-700, PB-770 15-pin Pocket Computers

PB-700, PB-770

Actual testing was done on both of these models.

For both models mentioned here, select PB-700. A subfolder named “PB-700” will be used as the root directory for all micro SD card functions for these models.

Use the 15-pin Casio interface pack for these models:

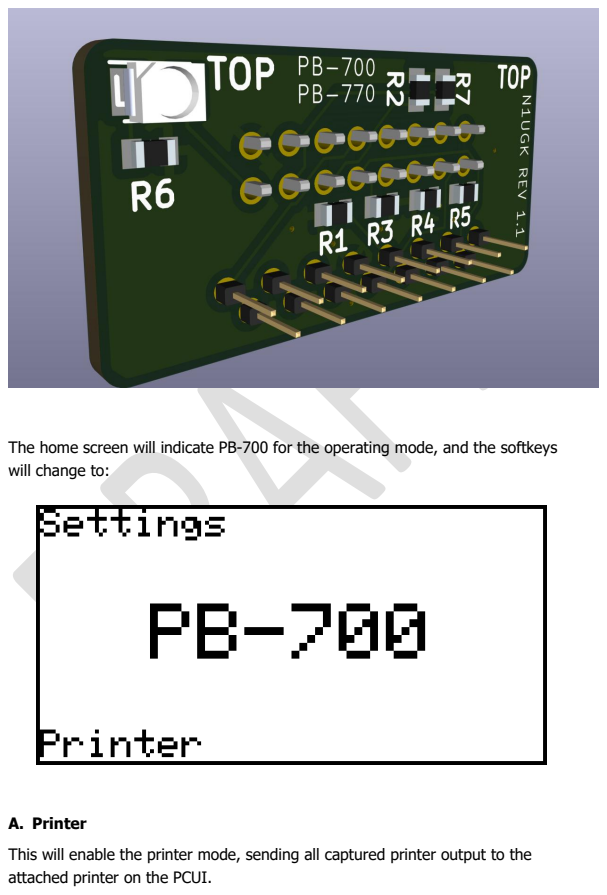
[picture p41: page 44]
A. Printer

The home screen will indicate PB-700 for the operating mode, and the softkeys
will change to:

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

B. FA-10 / FA-11 Plotter Emulation

The FA-10 plotter for the PB-700 and PB-770 provided for methods to plot lines, shapes, points, and text. The PCUI has a plotter emulation which will listen for the plotter commands, plot them on a canvas in memory, and then print out the canvas when the return to character mode is received.

In addition, a PNG file of the canvas will be saved. The PCUI can print the plots to a printer that supports either ESC/POS or ProPrinter modes.

Below is an example of a plot from the FA-10 owners manual, output by the PCUI in PNG format:

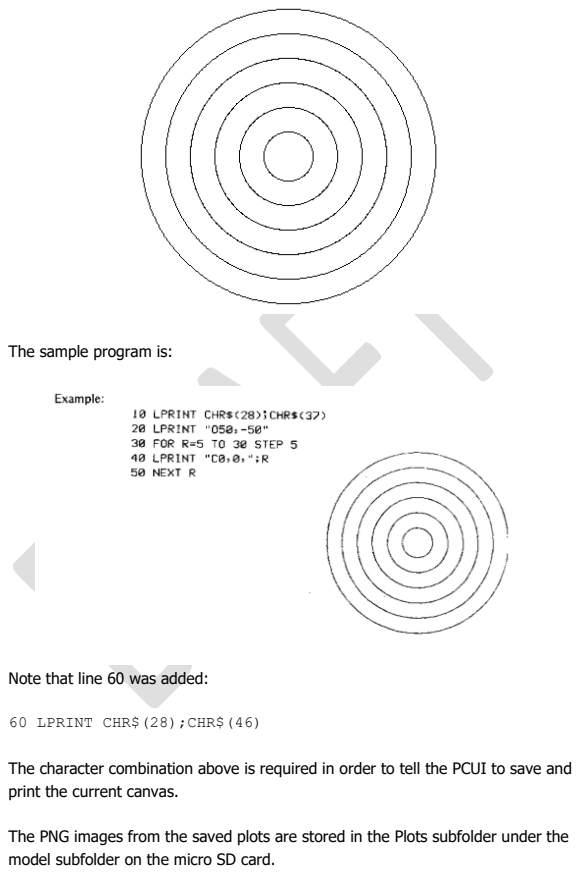
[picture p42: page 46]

The sample program is:

Note that line 60 was added:

60 LPRINT CHR$(28);CHR$(46)

The character combination above is required in order to tell the PCUI to save and
print the current canvas.

The PNG images from the saved plots are stored in the Plots subfolder under the
model subfolder on the micro SD card.

C. Sending a Program, Variable(s) or Memo:

This will allow you to send a stored program or variables from the micro SD card to the pocket computer. To initiate the transfer, type LOAD or GET on the pocket computer. The PCUI will detect the status on the bus and automatically open the send menu:


Select the appropriate type of file to send (based on your LOAD/GET command) and then a menu of file names will appear to select from:

The file name for LOAD or GET on the pocket computer is optional. If you specify a file name, then the pocket computer will compare the file name you specify with the file name sent by the PCUI. If they do not match, then the pocket computer will not accept the incoming file.

D. Saving a BASIC Program

To save a BASIC program to the micro SD card, type SAVE and enter on the pocket computer. Be sure to do this only when the PCUI is on the home screen, not when printer mode or any other menu or function is being displayed.

The file name for SAVE on the pocket computer is optional. If you specify a file name, then the PCUI will save the incoming BASIC program onto the micro SD card with the name you specify. If you do not specify a file name, the PCUI will name the file BAS_xxx where xxx is a sequential number.

E. Saving and Loading in ASCII Mode

The PB-700 and PB-770 allow saving BASIC programs to ASCII and loading from ASCII. The PCUI will save and load ASCII files, which is convenient for editing with a text editor on a computer and then loading directly into the pocket computer.

Use the SAVE,A and LOAD,A variants for this mode.

Note that unexpected format, lines longer than the PB-700 supports, and syntax issues will cause a RW Error to occur when loading. This is relevant if creating or editing a program from a PC or Mac. Also, be sure to terminate the file with two line feeds in a row (or two carriage return and line feed combos).

F. Saving Variables

To save the variable contents on the pocket computer to the micro SD card, type PUT and enter on the pocket computer. Be sure to do this only when the PCUI is on the home screen, not when printer mode or any other menu or function is being displayed.

The file name for PUT on the pocket computer is optional. If you specify a file name, then the PCUI will save the incoming variable contents onto the micro SD card with the name you specify. If you do not specify a file name, the PCUI will name the file mem_xxx where xxx is a sequential number.

XII. Texas Instruments Graphing Calculators

TI-82*, TI-85*, TI-86*, TI-89*, TI-92*, TI-92 Plus*, Voyage 200*

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

A subfolder named by model will be used as the root directory for all micro SD card functions for these models.

A. Print; enabled).; B. Gray Link; to communicate to the TI via the PCUI.

This will grab the current screen from the attached TI graphing calculator and save a PNG of the screen as well as print out to the attached printer (if printer is

This will enable the passthrough mode between the attached TI graphing calculator and the virtual COM port on the USB connector. This effectively emulates a “Gray Link” USB cable, allowing both TI software and TiLP software

C. Send

This will send a selected program, string, text, or other object type to the attached TI graphing calculator.

D. Sending from the TI to the PCUI

You can send a program, string, text, or other object at any time to the PCUI, provided the PCUI is on the home screen. The object will be stored in the appropriate subfolder on the micro SD card.

E. Printing from BASIC Programs

The PCUI adds printer support to BASIC programs with a creative hack. Since the PCUI can receive variables, and the TI BASIC allows for programs to send variables using the “sendcalc” function, the PCUI can intercept these variables and use the variable contents to drive settings and/or send data to the attached printer.

This functionality works by inspection of the variable name and then directing the contents according to the name. The following table outlines the specific variable names the PCUI recognizes and their purpose / function:

Variable Name | Variable Type | Purpose / Function
print | String | Sends a string to the attached printer
print | Integer | Sends the integer (byte value ranging from 0 – 255) to the printer
prtscr | String | If the PCUI receives this variable with any content, it will request a print screen from the

| | TI and print it to the attached printer
prtx | Integer | The x offset of the print screen location, default is 0
prty | Integer | The y offset of the print screen location, default is 0
prtw | Integer | The number of pixels for the width of the screen shot
prty | Integer | The number of pixels for the height of the screen shot
prtscl | Integer | The scaling factor for the screen shot printout
prtcut | Integer | If the value is 1, enables the automatic paper cut after printing the screen, default is zero.

Example:

“Test 123” → print
SendCalc(print)

XIII.Casio FA-10/FA-11 Plotter Emulation

The PCUI supports Casio FA-10/FA-11 plotters by recognizing the plotting commands and utilizing an in-memory canvas, save to PNG, and output to printer process.

Note that all commands must terminate a 0x0D character or any char between 0x01 and 0x0F. This is automatic on pocket computers which supported plotters but not necessarily those that do not.

The same commands noted in the Casio FA-10 or FA-11 owners manual are included here as a reference:

A. Drawing Commands

Cmd; Name; Syntax; Description; Draw; Relative; Move; Move pen by a relative; Quadrangle; Draw a rectangle defined by; Circle/Arc; B. Axes & Grids; Axis; X dir,div,count

Draw lines. First pair sets
starting point (pen move);
subsequent pairs draw line
segments. If the first
parameter is omitted
(D,x2,y2,...), drawing starts
from the current pen
position.

Draw lines using relative
offsets from the current pen
position. Multiple pairs chain
together.

Move pen to absolute
position (relative to ORG).
No drawing.

offset. No drawing.

two opposite corners.

Draw a circle or arc. Center
can be omitted
(,r,start,end) to use current
pen position. If start/end
angles are omitted, a full
circle is drawn. Angles in
degrees.

cx,cy,r[,start,end]

Draw an axis from the ORG
origin. dir: 0=+Y, 1=+X,
2=−Y, 3=−X. div: tick

Cmd; Name; Syntax; Description; Grid; C. Text & Symbols; Print; P<text>; Mark; N type; D. Settings Commands; Origin; Set the; coordinate origin.; No params =; current pen; position becomes; origin.; Line Type

spacing (mm). count:
number of divisions.

Draw a grid rectangle with
internal lines. dir:
1=horizontal stripes,
2=vertical
stripes. sep defaults to 1.

dir,xrange,yrange[,sep]

Print a character string at the current pen
position using the current scale, rotation,
and spacing settings. ASCII 0x20–0x7E.

Draw a marker symbol at the current pen
position. Types: 1=+, 2=×, 3=* (+ and

Set line style:
0=solid,
1=broken,
2=one-dot chain,
3=two-dot chain.

Cmd; Name; Syntax; Description; Line Scale; Alpha Scale; Alpha Rotate; Set text rotation:; CCW, 2=180°,; 3=270° CCW.; Space; charspace[,linespace]; Horizontal/Vertical; New Pen; E. Control Commands; Home; Line; Feed; Advance pen downward by n lines (based

Set pitch (mm)
for broken/chain
line types. Default

Set character size
(0–9). Rendered
as (n+1)× scale.

Set character
spacing and line
spacing (in plotter
units).

Set text direction:
0=horizontal,
1=vertical.

Set pen colour:
0=black, 1=blue,
2=green, 3=red.
(Stored but
rendered mono.)

With parameter: feed paper and reset
origin to (0,0). Without: return pen to
origin.

on current scale/spacing).

Cmd | Name | Syntax | Description
@ | Test | @ | Draw 4 small rectangles (colour-check pattern).
F. Protocol Framing
- Enter graphic mode: 0x1C 0x25 (FS %)
- Exit graphic mode: 0x1C 0x2E (FS .) — triggers rendering, PNG save, and printing
- Commands are terminated by any control character (0x01–0x1F) or by the start of the next command letter
- All command letters are case-insensitive
- Parameters are comma-separated signed decimals (integers or floats)
- Coordinates are in mm relative to the current ORG unless otherwise noted

Note that your program can issue a return to text mode CHR$(28);CHR$(46) which will cause the PCUI to automatically print the canvas and form feed or cut the paper (if this option is enabled). Alternatively, you can press the PRINT softkey manually to perform the same task.

XIV. Casio FP-100 Plotter Emulation

The PCUI supports Casio FP-100 plotters by recognizing the plotting commands and utilizing an in-memory canvas, similar to the FA-10/FA-11 emulation.

Note that all commands must terminate a 0x0D character or any char between 0x01 and 0x0F. This is automatic on pocket computers which supported plotters but not necessarily those that do not.

XV. Miscellaneous Functions

A. Deleting a File

On any file selection dialog, you can delete the file by pressing BACK and OK simultaneously.

B. Screen Shot

On most screens, a screen shot can be taken by pressing the UP and DOWN keys simultaneously. The file is saved in PNG format.

C. USB Drive Mode

On most screens, USB drive mode can be enabled by pressing the BACK and OK buttons simultaneously.

D. Reset to Default Settings

If you need to start up with default settings, press both the BACK and OK keys when powering on the PCUI, until the main screen appears.

E. Status

If you need to troubleshoot inputs such as buttons, micro SD card switch, or others, the Status menu under Settings will display those items. This is useful if for example you need to troubleshoot the micro SD card switch contact point, parallel port input(s), etc.

XVI. Program Repo; programs available for that model.

The PCUI public GitHub repo has pocket computer programs for various models. The PCUI can “browse” this repo, assuming you enable Wi-Fi and have internet access available through the Wi-Fi connection.

Depending on the model / mode you are currently in, the PCUI will fetch a catalog of

You can browse this repo from the Settings Menu, then Wi-Fi menu.

If there are programs available, then they will be listed by title and if there is enough room on the OLED, the version will be displayed as well:


Clicking OK on a title will bring up the menu allowing you to view the details of the
program, the “Read Me” for the program, and lastly an Install option to copy the
program’s files onto your SD card:

For example, details of a program are displayed as follows:

The Read Me can be displayed as well, and the Up/Down arrow keys can be used to

As with almost everything which has embedded software in it these days, the PCUI is no exception when it comes to the need for periodic firmware updates.

Updates may fix bugs and/or add new features. Check the web site often for updates, and if one is available, you can download the update and save it on your computer.

In order to update the firmware, you will need to place the PCUI into bootloader mode. This can be done via the main menu, then Settings, then Update Firmware.

The PCUI will reboot into it’s bootloader mode. Plug the PCUI into a Mac or PC, and drag and drop the firmware file onto the removable drive that appears.

The PCUI will decrypt the firmware file, verify the signature, and if it passes, it will pause for 5 seconds, flash, and reboot.

Note that the PCUI bootloader is different from the Pico bootloader - if you use the bootsel button on the pico to get into the bootloader and drag and drop the PCUI firmware, it will be rejected as the Pico's bootloader cannot decrypt the firmware

image. You can easily determine which bootloader you are in by looking at the directory contents of the USB drive which appears on your computer. If you see PCUI.txt, then you are in the PCUI's bootloader. If you see another *UF2.txt file,

You can confirm the current running firmware by clicking the Settings menu and

Sometimes issues occur with firmware updates or the firmware itself has a defect which prevents normal firmware update processes. The PCUI will reboot into the bootloader mode if the application cannot start up normally. Further, if this fails, pressing all four buttons while powering up the PCUI will force the application to reboot into the bootloader. This will allow you to flash a new bootloader or firmware image.

In the event of a hardware failure where the buttons do not work, press and hold the BOOTSEL button on the Pico 2 until the onboard LED flashes, then release BOOTSEL. The PCUI will reboot to the bootloader.

Note that the PCUI bootloader referenced here is the secondary bootloader, not the bootloader built into the Pi Pico 2. The Pi Pico 2 bootloader cannot be used to load PCUI firmware updates, as those images are encrypted.

XVIII. File Format Technical Notes

When the PCUI receives a bit stream from an attached pocket computer or calculator via the cassette save function, framing, leaders, stop/start bits, etc are removed before being saved to SD card. When sending the file back to the pocket computer, that information is added back. This allows for easier inspection of binary file content if needed.

There is a Debug Save feature in the settings menu. If this is enabled, a debug.bin folder will be saved in the root folder for the given model. The content is not only the file or variable data, but all of the framing is left intact. This is useful for debugging unsupported models or troubleshooting issues with supported models. By inspecting the framing and data, additional models can be supported.

XIX. Self-Test Mode

The PCUI firmware has several self-test routines, useful for debugging hardware issues. The various tests are designed to be run after PCB assembly to ensure components were soldered correctly and to ensure complete end-to-end connectivity between the PCUI and pocket computers.

The self-test can be activated from the main menu – before activating, be sure to disconnect the PCUI from any pocket computers and interface packs.

The first screen displays the firmware version and an OK button to begin the test routines.

The first test is an I2C communication test between the Pico 2 and the 4 port expanders.

The second test is for all four buttons, the OLED, and the LEDs.

A. Buffer Test

The buffer test is a routine that puts the bi-directional buffer between the PCUI and the pocket computer IDC header into input mode for all pins. It then displays the state of each pin, which should read zero (low level) with nothing attached. The display automatically refreshes in the background.

To test each input, use a 10K-ohm pull up resistor between the 5-volt VCC pin on J1, pin 15 and touch to each of the pins listed on the OLED. Pause on each briefly, until you see the transition from zero to 1 on the OLED. Be sure to look out for any other pin which reads a transition from zero to one, as this would indicate a short or crossed signal which needs to be corrected.

This test is performed after PCUI assembly, and since assembly is done by hand, it is usually the case that residual flux from the SMT soldering is causing a short. Use IPA (Isopropyl Alcohol, 90+%) on IC5 and a toothbrush with a clean cloth. Repeat until no shorts are indicated.

B. Frequency Generator Output

To test for noise from capacitance within an IDC cable and other issues with the buffer IC5 and the Pico 2, the frequency generator output test will place a 200khz square wave on each of the I/O pins for the pocket computer connector J1. This test will require either an oscilloscope or another PCUI in frequency in mode.

If using an oscilloscope, place your probe ground on pin 16 on J1, and then probe each of the pins indicated on the OLED, one by one. Use the
UP/DOWN softkeys to change the output pin, and ensure no other pins (1-13) other than the one you’re currently testing shows any output on the scope.

If using another PCUI for the test, put the other PCUI into frequency in mode, then connect the two via J1. The output PCUI should be used to generate the tone on each of the pins, while looking at the OLED on the input PCUI for the same pin and frequency to match the output.

C. Dir Toggle Test

To test for issues with the level shifting buffer IC and direction switching, this test toggles the direction at variable relatively low frequencies (actual usage patterns). You can select the A & B sides independently as well as the output enable toggling. This is useful to confirm the OE and DIR lines are working correctly.

D. TI Link

The TI Link test will check the cable inserted input pin – inserting a 2.5mm plug into the port will confirm operation of the input pin (or removal of the plug if one is already inserted).

E. SD Card

The SD card tests consist both of a card inserted input check as well as a read/write test. The test will first prompt for removal of the SD card if one is inserted, or insertion of a card if one is not inserted. It will then write a small file to the root folder and attempt to read the file back.

F. Parallel Port

The parallel port test will output a sample string to the port to test output.

G. Serial Port

The serial port test will output a sample string to the port to test output.

XX. Acknowledgments

I would like to thank the following for their documentation and projects:

Piotr for the excellent sample AVR code, documented bus timing and wiring diagrams for various Casio pocket computers: https://www.pisi.com.pl/piotr433/

Marcus von Cube for his work on the Casio Utilities and for software testing: https://www.mvcsys.de/doc/casioutil.html

Tim Singer and Romain Lievin for their work documenting the TI graphing calculator protocol: https://merthsoft.com/linkguide/

The Pocket Computer Museum for their Sharp tools: http://pocket.free.fr/

Hey Birt! – his YouTube videos for repairs, tools, methods, inspiration from the

and hardware. https://www.youtube.com/channel/UC2V0T-vGOewtuCW3pazzczQ; these models. https://github.com/codaris

backpack drive and CE-158X projects. In addition, help with testing the software

Codaris – His work on the SharpManager project helped bridge the gap between my 1246 support and the “new” 1401/1403 protocols the CE-126P was performing with

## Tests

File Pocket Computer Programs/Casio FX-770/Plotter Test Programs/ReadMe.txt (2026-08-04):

These programs are from the FA-10 plotter Owners Manual.  I used these to test the plotter emulation for the PCUI to ensure each sample plotter function was properly simulated in the PCUI internal canvas.

These programs were modified for the FX-770 as follows.  The FX-770 cannot output the escape codes necessary to enable graphics mode, those bytes come off the bus as spaces (they are outside the FP-12S printable character range).  The PCUI has a "hex translation" feature, which allows any byte to be pushed to the printer port on the PCUI using an escape sequence then the hexadecimal digit(s) to output.  For example "?X010203" would output 0x01 0x02 0x03.

This translation feature allows pocket computers such as the FX-770 (and similar models) to use the plotter emulation feature in the PCUI and/or real plotters connected to the PCUI.

PLOTTSTC.txt - Circles (Programming Example No. 2)

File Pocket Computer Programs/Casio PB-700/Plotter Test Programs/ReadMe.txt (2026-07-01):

These programs are from the FA-10 Owners Manual.  I used these to test the plotter emulation for the PCUI to ensure each sample plotter function was properly simulated in the PCUI internal canvas.

The only change to these programs was I added LPRINT CHR$(28);CHR$(46) at the end of the programs in order to signal to the PCUI to end plotter mode and print the internal canvas to the attached printer.

These should be loaded into the PB-700/PB-770 in ASCII mode:

Example:

LOAD "PLOTTST6",A

PLOTTST1.txt - DRAW
PLOTTST2.txt - Circles
PLOTTST3.txt - Relative Draw / Move
PLOTTST4.txt - Relative Move /Quadrangle
PLOTTST5.txt - Circles / Axis
PLOTTST6.txt - Grid / Line Type
PLOTTST7.txt - Line Scale
PLOTTST8.txt - Alpha Scale
PLOTTST9.txt - Alpha Rotate
PLOTTSTA.txt - Space
PLOTTSTB.txt - Programming Example No. 1
PLOTTSTC.txt - Programming Example No. 2
PLOTTSTD.txt - Trig Function Table
PLOTTSTE.txt - Pie Chart
PLOTTSTF.txt - Home 
PLOTTSTG.txt - Floor Plan

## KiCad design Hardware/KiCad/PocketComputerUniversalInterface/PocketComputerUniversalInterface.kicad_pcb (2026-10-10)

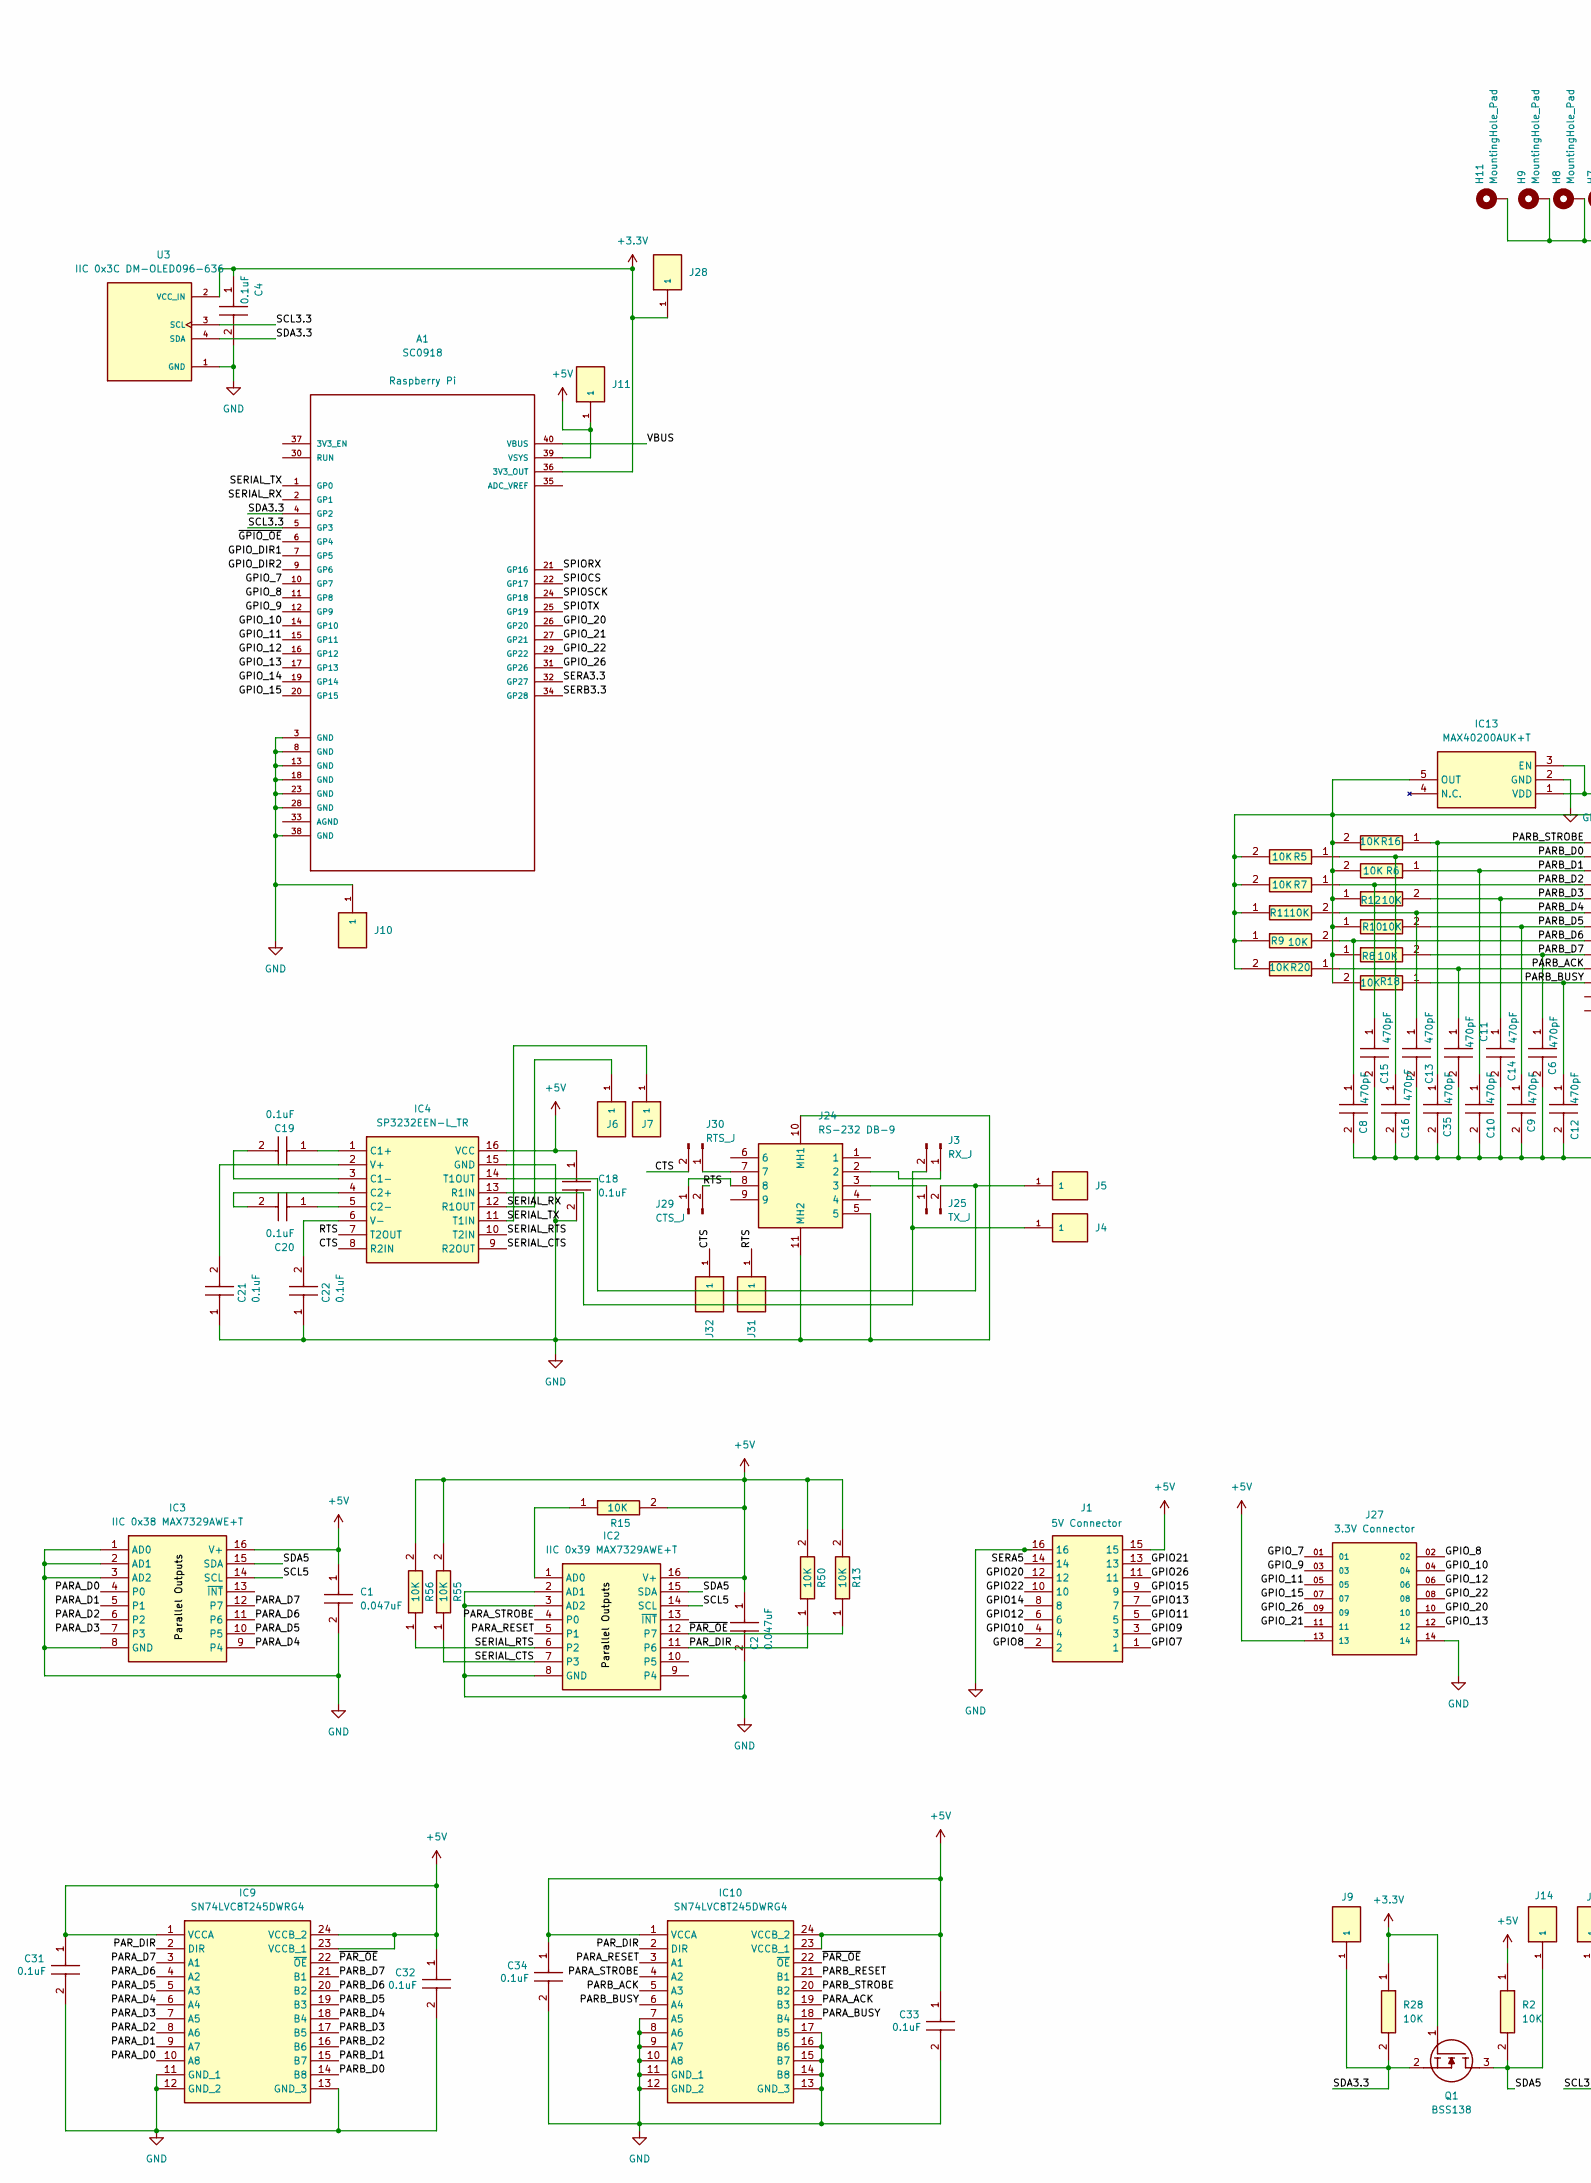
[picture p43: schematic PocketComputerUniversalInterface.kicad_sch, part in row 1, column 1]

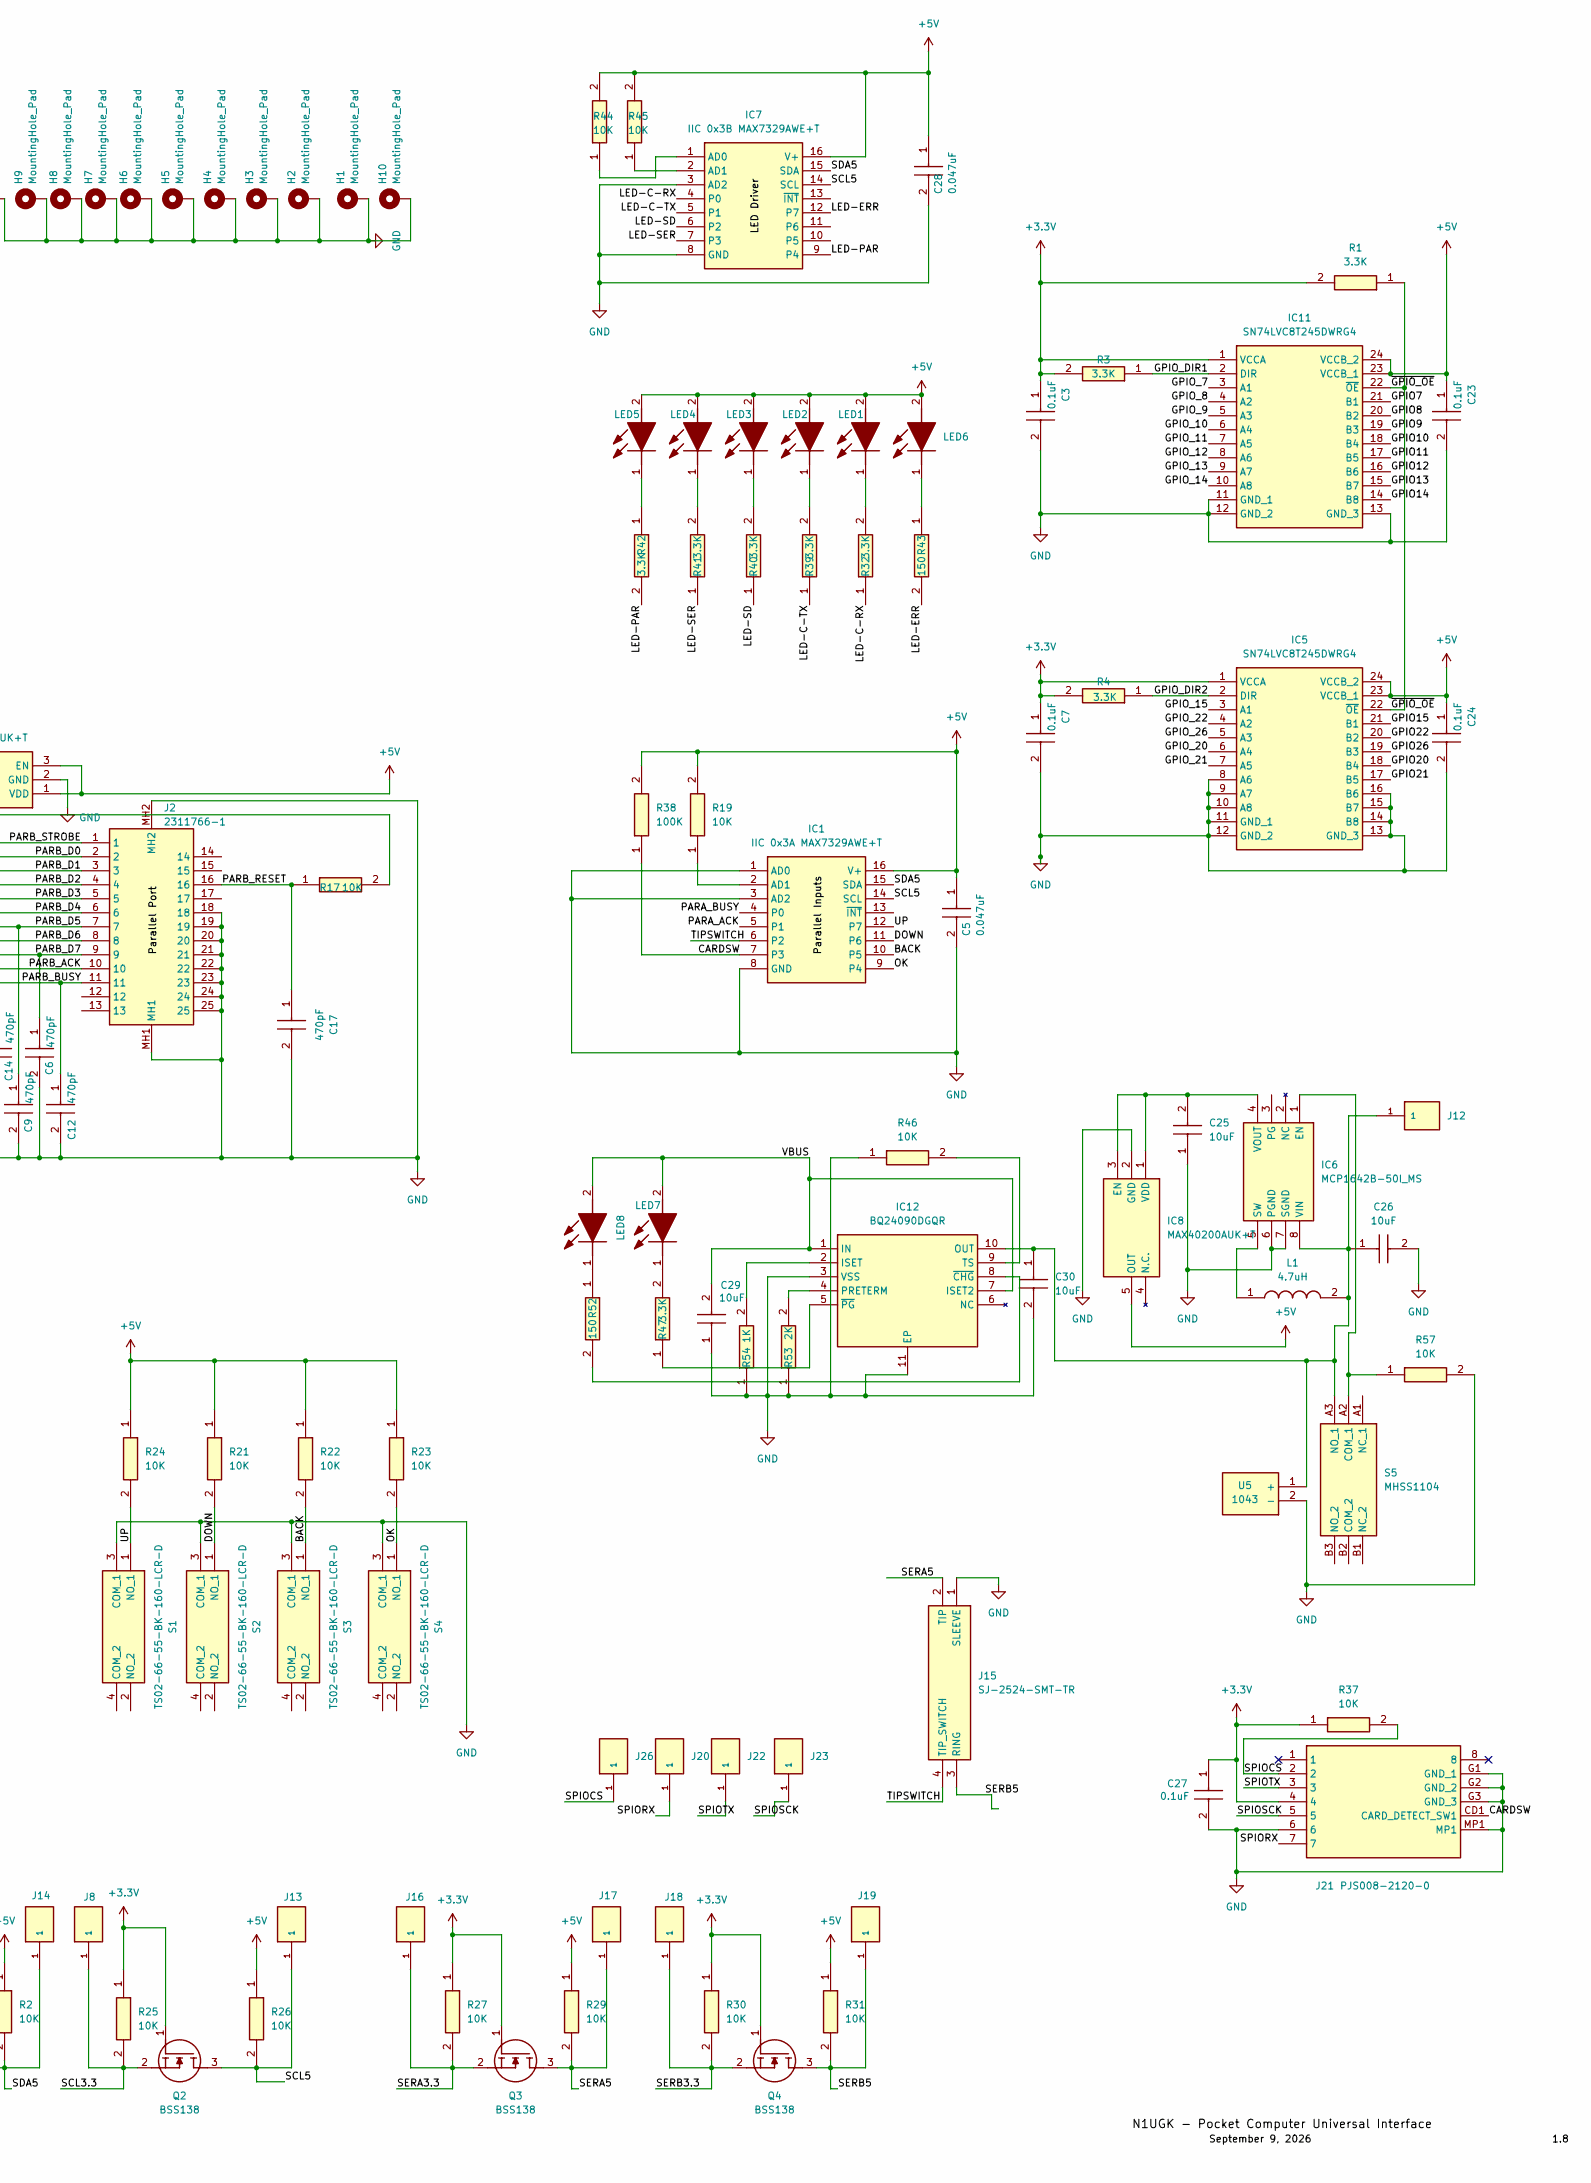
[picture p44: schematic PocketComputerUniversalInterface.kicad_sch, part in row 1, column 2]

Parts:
A1: SC0918; MODULE_SC0918; PARTREV 1.6
C1, C2, C5, C28: 0.047uF; C1206; Mouser Part Number 80-C1206C473J5R
C3, C4, C7, C23, C24: 0.1uF; CAPC3216X94N; Mouser Part Number 581-12062A471KAT2A
C6, C8, C9, C10, C11, C12, C13, C14, C15, C16, C17, C35: 470pF; CAPC3216X94N; Mouser Part Number 581-12062A471KAT2A
C18, C19, C20, C21, C22, C27, C31, C32, C33, C34: 0.1uF; CAPC3216X94N; Mouser Part Number 581-12061C103J
C25, C26, C29, C30: 10uF; CAPC1608X90N; Mouser Part Number 81-GRM188R60J106ME4D
H1, H2, H3, H4, H5, H6, H7, H8, H9, H10, H11: MountingHole_Pad; MountingHole_3.2mm_M3_Pad_Via
IC1: IIC 0x3A MAX7329AWE+T; SOIC127P1032X265-16N; Mouser Part Number 700-MAX7329AWET
IC2: IIC 0x39 MAX7329AWE+T; SOIC127P1032X265-16N; Mouser Part Number 700-MAX7329AWET
IC3: IIC 0x38 MAX7329AWE+T; SOIC127P1032X265-16N; Mouser Part Number 700-MAX7329AWET
IC4: SP3232EEN-L_TR; SOIC127P600X175-16N; Mouser Part Number 701-SP3232EEN-L/TR
IC5, IC9, IC10, IC11: SN74LVC8T245DWRG4; SOIC127P1030X265-24N; Mouser Part Number 595-74LVC8T245DWRG4
IC6: MCP1642B-50I_MS; SOP65P490X110-8N; Mouser Part Number 579-MCP1642B-50I/MS
IC7: IIC 0x3B MAX7329AWE+T; SOIC127P1032X265-16N; Mouser Part Number 700-MAX7329AWET
IC8, IC13: MAX40200AUK+T; SOT95P280X145-5N; Mouser Part Number 700-MAX40200AUK+T
IC12: BQ24090DGQR; SOP50P490X110-11N; Mouser Part Number 595-BQ24090DGQR
J1: 5V Connector; TSS-108-XX-YYY-D; Manufacturer_Part_Number TSS-108-02-L-D
J2: 2311766-1; 23117661; Mouser Part Number 571-2311766-1
J3: RX_J; PinHeader_1x02_P2.54mm_Vertical
J4, J5, J6, J7, J8, J9, J10, J11, J12, J13, J14, J16, J17, J18, J19, J20, J22, J23, J26, J28, J31, J32: SAMTEC-HMTSW-101-24-X-S-290
J15: SJ-2524-SMT-TR; SJ2524SMTTR; Mouser Part Number 490-SJ-2524-SMT-TR
J21: PJS008-2120-0; PJS00821200; Mouser Part Number 945-PJS008-2120-0
J24: RS-232 DB-9; 6E17C009PBF221; Manufacturer_Part_Number 6E17C009PBF221
J25: TX_J; PinHeader_1x02_P2.54mm_Vertical
J27: 3.3V Connector; SAMTEC_TSS-107-02-H-D; PARTREV R
J29: CTS_J; PinHeader_1x02_P2.54mm_Vertical
J30: RTS_J; PinHeader_1x02_P2.54mm_Vertical
L1: 4.7uH; EPL3015472MLC; Mouser Part Number 994-EPL3015-472MLC
LED1, LED2, LED3, LED4, LED5, LED7: HSMM-A100-S00J1; LEDM3528X200N; Mouser Part Number 630-HSMM-A100-S00J1
LED6, LED8: HSMS-A100-L00J1; HSMSA100L00J1; Mouser Part Number 630-HSMS-A100-L00J1
Q1, Q2, Q3, Q4: BSS138; SOT95P240X120-3N; Mouser Part Number 512-BSS138
R1, R3, R4, R32, R39, R40, R41, R42, R47: 3.3K; RESC2013X65N; Mouser Part Number 756-WCR0805-10KFI
R2, R5, R6, R7, R8, R9, R10, R11, R12, R13, R15, R16, R17, R18, R19, R20, R21, R22, R23, R24, R25, R26, R27, R28, R29, R30, R31, R37, R44, R45, R46, R50, R55, R56, R57: 10K; RESC2013X65N; Mouser Part Number 756-WCR0805-10KFI
R38: 100K; RESC2013X65N; Mouser Part Number 756-WCR0805-10KFI
R43, R52: 150; RESC2013X65N; Mouser Part Number 756-WCR0805-10KFI
R53: 2K; RESC2013X65N; Mouser Part Number 756-WCR0805-10KFI
R54: 1K; RESC2013X65N; Mouser Part Number 756-WCR0805-10KFI
S1, S2, S3, S4: TS02-66-55-BK-160-LCR-D; TS026655BK160LCRD; Mouser Part Number 179-TS026655BK160LCR
S5: MHSS1104; Mouser Part Number 642-MHSS1104
U3: IIC 0x3C DM-OLED096-636; MODULE_DM-OLED096-636; PARTREV 2018-09-10
U5: 1043; Mouser Part Number 534-1043

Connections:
+3.3V: A1.36 (3V3_OUT), C3.1 (C1), C4.1, C7.1 (C1), C27.1 (C1), IC5.1 (VCCA), IC11.1 (VCCA), J21.4, J28.1, Q1.1 (G), Q2.1 (G), Q3.1 (G), Q4.1 (G), R1.2, R3.2, R4.2, R25.1, R27.1, R28.1, R30.1, R37.1, U3.2 (VCC_IN)
+5V: A1.39 (VSYS), C1.1, C2.1, C5.1, C18.1 (C1), C23.1 (C1), C24.1 (C1), C28.1, C31.1 (C1), C32.1 (C1), C33.1 (C1), C34.1 (C1), IC1.16 (V+), IC2.16 (V+), IC3.16 (V+), IC4.16 (VCC), IC5.23 (VCCB_1), IC5.24 (VCCB_2), IC7.16 (V+), IC8.5 (OUT), IC9.1 (VCCA), IC9.23 (VCCB_1), IC9.24 (VCCB_2), IC10.1 (VCCA), IC10.23 (VCCB_1), IC10.24 (VCCB_2), IC11.23 (VCCB_1), IC11.24 (VCCB_2), IC13.1 (VDD), IC13.3 (EN), J1.15, J11.1, J27.13, LED1.2 (A), LED2.2 (A), LED3.2 (A), LED4.2 (A), LED5.2 (A), LED6.2 (A), R2.1, R13.2, R15.2, R19.2, R21.1, R22.1, R23.1, R24.1, R26.1, R29.1, R31.1, R38.2, R44.2, R45.2, R50.2, R55.2, R56.2
/BACK: IC1.10 (P5), R22.2, S3.1 (NO_1)
/CARDSW: IC1.7 (P3), J21.CD1 (CARD_DETECT_SW1), R38.1
/CTS: IC4.8 (R2IN), J30.2, J32.1
/DOWN: IC1.11 (P6), R21.2, S2.1 (NO_1)
/GPIO7: IC11.21 (B1), J1.1
/GPIO8: IC11.20 (B2), J1.2
/GPIO9: IC11.19 (B3), J1.3
/GPIO10: IC11.18 (B4), J1.4
/GPIO11: IC11.17 (B5), J1.5
/GPIO12: IC11.16 (B6), J1.6
/GPIO13: IC11.15 (B7), J1.7
/GPIO14: IC11.14 (B8), J1.8
/GPIO15: IC5.21 (B1), J1.9
/GPIO20: IC5.18 (B4), J1.12
/GPIO21: IC5.17 (B5), J1.13
/GPIO22: IC5.20 (B2), J1.10
/GPIO26: IC5.19 (B3), J1.11
/GPIO_7: A1.10 (GP7), IC11.3 (A1), J27.01
/GPIO_8: A1.11 (GP8), IC11.4 (A2), J27.02
/GPIO_9: A1.12 (GP9), IC11.5 (A3), J27.03
/GPIO_10: A1.14 (GP10), IC11.6 (A4), J27.04
/GPIO_11: A1.15 (GP11), IC11.7 (A5), J27.05
/GPIO_12: A1.16 (GP12), IC11.8 (A6), J27.06
/GPIO_13: A1.17 (GP13), IC11.9 (A7), J27.12
/GPIO_14: A1.19 (GP14), IC11.10 (A8)
/GPIO_15: A1.20 (GP15), IC5.3 (A1), J27.07
/GPIO_20: A1.26 (GP20), IC5.6 (A4), J27.10
/GPIO_21: A1.27 (GP21), IC5.7 (A5), J27.11
/GPIO_22: A1.29 (GP22), IC5.4 (A2), J27.08
/GPIO_26: A1.31 (GP26), IC5.5 (A3), J27.09
/GPIO_DIR1: A1.7 (GP5), IC11.2 (DIR), R3.1
/GPIO_DIR2: A1.9 (GP6), IC5.2 (DIR), R4.1
/LED-C-RX: IC7.4 (P0), R32.1
/LED-C-TX: IC7.5 (P1), R39.1
/LED-ERR: IC7.12 (P7), R43.2
/LED-PAR: IC7.9 (P4), R42.2
/LED-SD: IC7.6 (P2), R40.1
/LED-SER: IC7.7 (P3), R41.1
/OK: IC1.9 (P4), R23.2, S4.1 (NO_1)
/PARA_ACK: IC1.5 (P1), IC10.19 (B3)
/PARA_BUSY: IC1.4 (P0), IC10.18 (B4)
/PARA_D0: IC3.4 (P0), IC9.10 (A8)
/PARA_D1: IC3.5 (P1), IC9.9 (A7)
/PARA_D2: IC3.6 (P2), IC9.8 (A6)
/PARA_D3: IC3.7 (P3), IC9.7 (A5)
/PARA_D4: IC3.9 (P4), IC9.6 (A4)
/PARA_D5: IC3.10 (P5), IC9.5 (A3)
/PARA_D6: IC3.11 (P6), IC9.4 (A2)
/PARA_D7: IC3.12 (P7), IC9.3 (A1)
/PARA_RESET: IC2.5 (P1), IC10.3 (A1)
/PARA_STROBE: IC2.4 (P0), IC10.4 (A2)
/PARB_ACK: C11.1 (C1), IC10.5 (A3), J2.10, R20.1
/PARB_BUSY: C12.1 (C1), IC10.6 (A4), J2.11, R18.1
/PARB_D0: C16.1 (C1), IC9.14 (B8), J2.2, R5.1
/PARB_D1: C10.1 (C1), IC9.15 (B7), J2.3, R6.1
/PARB_D2: C15.1 (C1), IC9.16 (B6), J2.4, R7.1
/PARB_D3: C14.1 (C1), IC9.17 (B5), J2.5, R12.2
/PARB_D4: C13.1 (C1), IC9.18 (B4), J2.6, R11.2
/PARB_D5: C9.1 (C1), IC9.19 (B3), J2.7, R10.2
/PARB_D6: C8.1 (C1), IC9.20 (B2), J2.8, R9.2
/PARB_D7: C6.1 (C1), IC9.21 (B1), J2.9, R8.2
/PARB_RESET: C17.1 (C1), IC10.21 (B1), J2.16, R17.1
/PARB_STROBE: C35.1 (C1), IC10.20 (B2), J2.1, R16.1
/PAR_DIR: IC2.11 (P6), IC9.2 (DIR), IC10.2 (DIR), R50.1
/RTS: IC4.7 (T2OUT), J29.2, J31.1
/SCL3.3: A1.5 (GP3), J8.1, Q2.2 (S), R25.2, U3.3 (SCL)
/SCL5: IC1.14 (SCL), IC2.14 (SCL), IC3.14 (SCL), IC7.14 (SCL), J13.1, Q2.3 (D), R26.2
/SDA3.3: A1.4 (GP2), J9.1, Q1.2 (S), R28.2, U3.4 (SDA)
/SDA5: IC1.15 (SDA), IC2.15 (SDA), IC3.15 (SDA), IC7.15 (SDA), J14.1, Q1.3 (D), R2.2
/SERA3.3: A1.32 (GP27), J16.1, Q3.2 (S), R27.2
/SERA5: J1.14, J15.2 (TIP), J17.1, Q3.3 (D), R29.2
/SERB3.3: A1.34 (GP28), J18.1, Q4.2 (S), R30.2
/SERB5: J15.3 (RING), J19.1, Q4.3 (D), R31.2
/SERIAL_CTS: IC2.7 (P3), IC4.9 (R2OUT), R55.1
/SERIAL_RTS: IC2.6 (P2), IC4.10 (T2IN), R56.1
/SERIAL_RX: A1.2 (GP1), IC4.12 (R1OUT), J6.1
/SERIAL_TX: A1.1 (GP0), IC4.11 (T1IN), J7.1
/SPIOCS: A1.22 (GP17), J21.2, J26.1, R37.2
/SPIORX: A1.21 (GP16), J20.1, J21.7
/SPIOSCK: A1.24 (GP18), J21.5, J23.1
/SPIOTX: A1.25 (GP19), J21.3, J22.1
/TIPSWITCH: IC1.6 (P2), J15.4 (TIP_SWITCH)
/UP: IC1.12 (P7), R24.2, S1.1 (NO_1)
/VBUS: A1.40 (VBUS), C29.2, IC12.1 (IN), IC12.7 (ISET2), LED7.2 (A), LED8.2 (A)
/~GPIO_OE: A1.6 (GP4), IC5.22 (~OE), IC11.22 (~OE), R1.1
/~PAR_OE: IC2.12 (P7), IC9.22 (~OE), IC10.22 (~OE), R13.1
GND: A1.3 (GND), A1.8 (GND), A1.13 (GND), A1.18 (GND), A1.23 (GND), A1.28 (GND), A1.38 (GND), C1.2, C2.2, C3.2 (C2), C4.2, C5.2, C6.2 (C2), C7.2 (C2), C8.2 (C2), C9.2 (C2), C10.2 (C2), C11.2 (C2), C12.2 (C2), C13.2 (C2), C14.2 (C2), C15.2 (C2), C16.2 (C2), C17.2 (C2), C18.2 (C2), C21.1 (C1), C22.1 (C1), C23.2 (C2), C24.2 (C2), C25.1, C26.2, C27.2 (C2), C28.2, C29.1, C30.2, C31.2 (C2), C32.2 (C2), C33.2 (C2), C34.2 (C2), C35.2 (C2), H1.1, H2.1, H3.1, H4.1, H5.1, H6.1, H7.1, H8.1, H9.1, H10.1, H11.1, IC1.1 (AD0), IC1.3 (AD2), IC1.8 (GND), IC2.2 (AD1), IC2.3 (AD2), IC2.8 (GND), IC3.1 (AD0), IC3.2 (AD1), IC3.3 (AD2), IC3.8 (GND), IC4.15 (GND), IC5.8 (A6), IC5.9 (A7), IC5.10 (A8), IC5.11 (GND_1), IC5.12 (GND_2), IC5.13 (GND_3), IC5.14 (B8), IC5.15 (B7), IC5.16 (B6), IC6.6 (PGND), IC6.7 (SGND), IC7.3 (AD2), IC7.8 (GND), IC8.2 (GND), IC9.11 (GND_1), IC9.12 (GND_2), IC9.13 (GND_3), IC10.7 (A5), IC10.8 (A6), IC10.9 (A7), IC10.10 (A8), IC10.11 (GND_1), IC10.12 (GND_2), IC10.13 (GND_3), IC10.14 (B8), IC10.15 (B7), IC10.16 (B6), IC10.17 (B5), IC11.11 (GND_1), IC11.12 (GND_2), IC11.13 (GND_3), IC12.3 (VSS), IC12.11 (EP), IC13.2 (GND), J1.16, J2.18, J2.19, J2.20, J2.21, J2.22, J2.23, J2.24, J2.25, J2.MH1, J2.MH2, J10.1, J15.1 (SLEEVE), J21.6, J21.G1 (GND_1), J21.G2 (GND_2), J21.G3 (GND_3), J21.MP1, J24.5, J24.10 (MH1), J24.11 (MH2), J27.14, R46.1, R53.1, R54.1, R57.2, S1.3 (COM_1), S2.3 (COM_1), S3.3 (COM_1), S4.3 (COM_1), U3.1 (GND), U5.2 (-)
unnamed: C19.1 (C1), IC4.1 (C1+)
unnamed: C19.2 (C2), IC4.3 (C1-)
unnamed: C20.1 (C1), IC4.5 (C2-)
unnamed: C20.2 (C2), IC4.4 (C2+)
unnamed: C21.2 (C2), IC4.2 (V+)
unnamed: C22.2 (C2), IC4.6 (V-)
unnamed: IC1.2 (AD1), R19.1
unnamed: IC2.1 (AD0), R15.1
unnamed: IC4.13 (R1IN), J3.2, J4.1
unnamed: IC4.14 (T1OUT), J5.1, J25.2
unnamed: IC6.1 (EN), R57.1, S5.A2 (COM_1)
unnamed: IC6.5 (SW), L1.1
unnamed: C25.2, IC6.4 (VOUT), IC8.1 (VDD), IC8.3 (EN)
unnamed: IC7.1 (AD0), R44.1
unnamed: IC7.2 (AD1), R45.1
unnamed: IC12.2 (ISET), R54.2
unnamed: C26.1, C30.1, IC6.8 (VIN), IC12.10 (OUT), J12.1, L1.2, S5.A3 (NO_1), U5.1 (+)
unnamed: IC12.4 (PRETERM), R53.2
unnamed: IC12.9 (TS), R46.2
unnamed: IC12.8 (~CHG), R52.2
unnamed: IC12.5 (~PG), R47.1
unnamed: IC13.5 (OUT), R5.2, R6.2, R7.2, R8.1, R9.1, R10.1, R11.1, R12.1, R16.2, R17.2, R18.2, R20.2
unnamed: J3.1, J24.2
unnamed: J24.3, J25.1
unnamed: J24.8, J29.1
unnamed: J24.7, J30.1
unnamed: LED1.1 (K), R32.2
unnamed: LED2.1 (K), R39.2
unnamed: LED3.1 (K), R40.2
unnamed: LED4.1 (K), R41.2
unnamed: LED5.1 (K), R42.1
unnamed: LED6.1 (K), R43.1
unnamed: LED7.1 (K), R47.2
unnamed: LED8.1 (K), R52.1

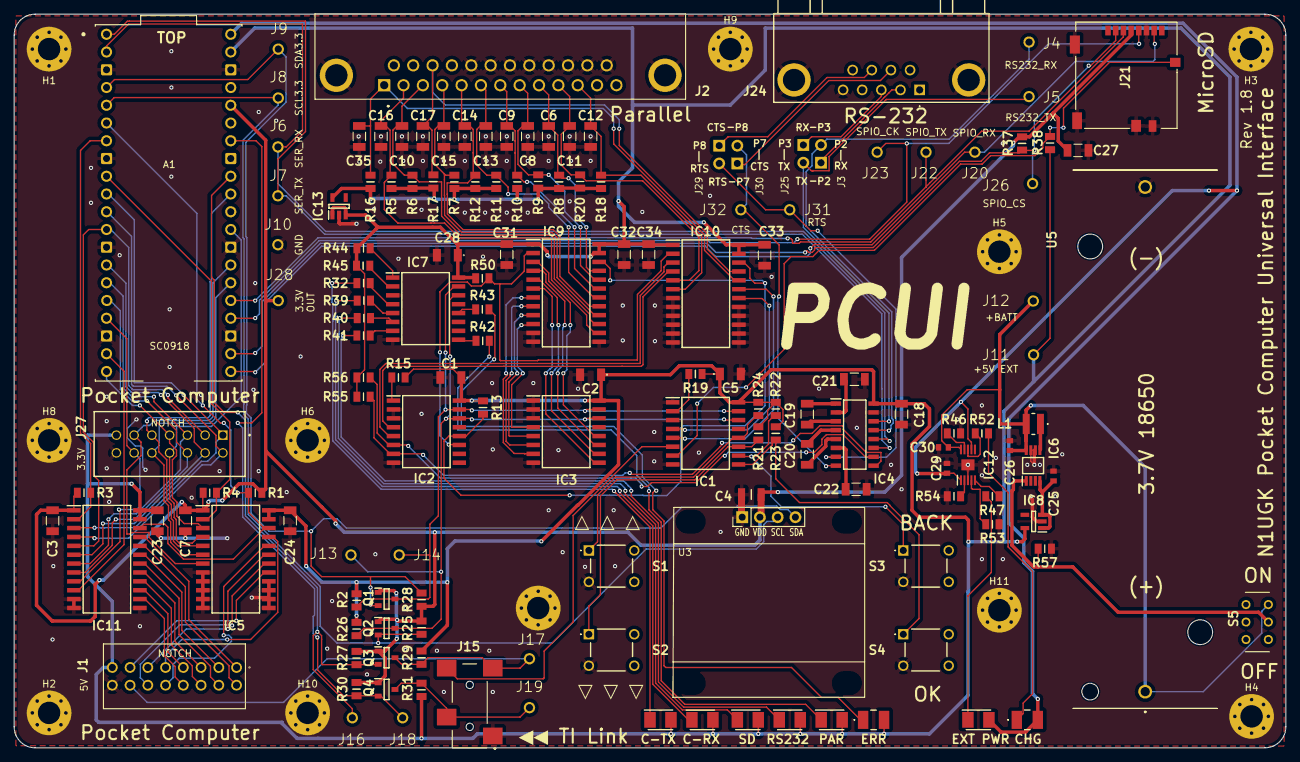
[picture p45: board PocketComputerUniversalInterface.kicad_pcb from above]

Board: 2 copper layers, 182.0 x 105.0 mm, 161 parts (0 on the bottom side), 123 nets.

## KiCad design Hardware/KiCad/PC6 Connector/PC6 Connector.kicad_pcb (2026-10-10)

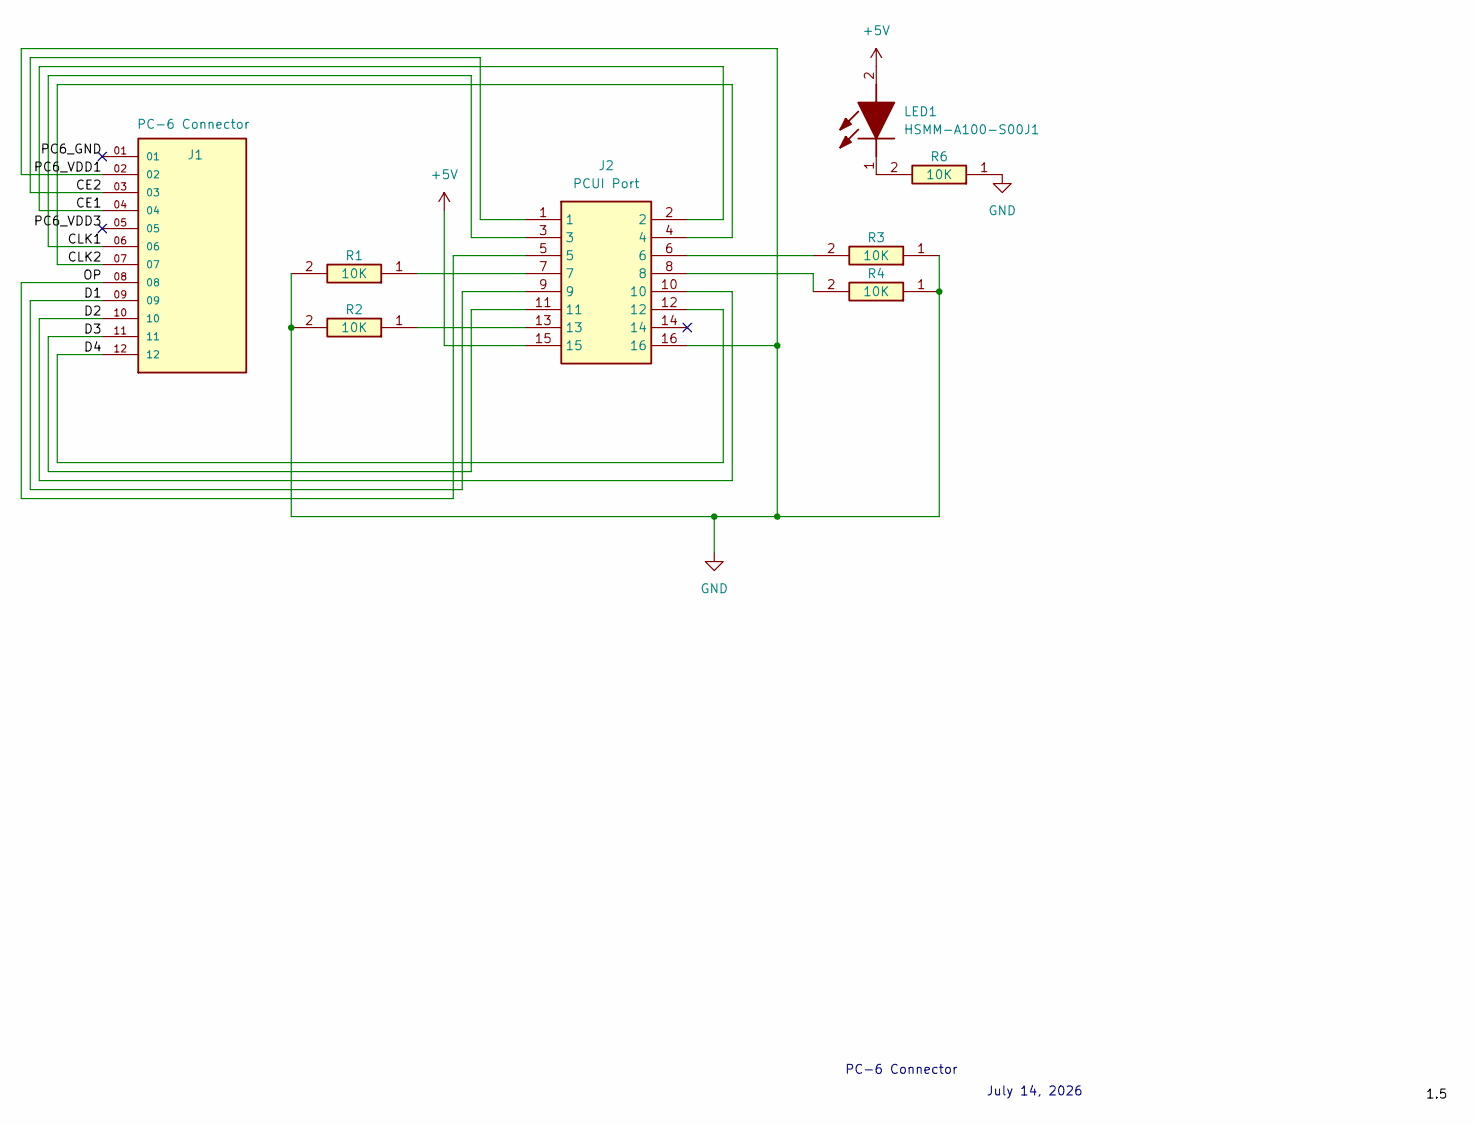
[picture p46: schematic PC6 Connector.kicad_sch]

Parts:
J1: PC-6 Connector; SAMTEC_TSW-112-07-L-S-LL; PARTREV R
J2: PCUI Port; TSS-108-XX-YYY-D; Manufacturer_Part_Number TSS-108-02-L-D
LED1: HSMM-A100-S00J1; LEDM3528X200N; Mouser Part Number 630-HSMM-A100-S00J1
R1, R2, R3, R4, R6: 10K; RESC2013X65N; Mouser Part Number 756-WCR0805-10KFI

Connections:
+5V: J2.15, LED1.2 (A)
/CE1: J1.04, J2.2
/CE2: J1.03, J2.1
/CLK1: J1.06, J2.3
/CLK2: J1.07, J2.4
/D1: J1.09, J2.9
/D2: J1.10, J2.10
/D3: J1.11, J2.11
/D4: J1.12, J2.12
/OP: J1.08, J2.5
/PC6_GND: J1.01
/PC6_VDD3: J1.05
GND: J1.02, J2.16, R1.2, R2.2, R3.1, R4.1, R6.1
unnamed: J2.6, R3.2
unnamed: J2.7, R1.1
unnamed: J2.8, R4.2
unnamed: J2.13, R2.1
unnamed: LED1.1 (K), R6.2

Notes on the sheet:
July 14, 2026
PC-6 Connector

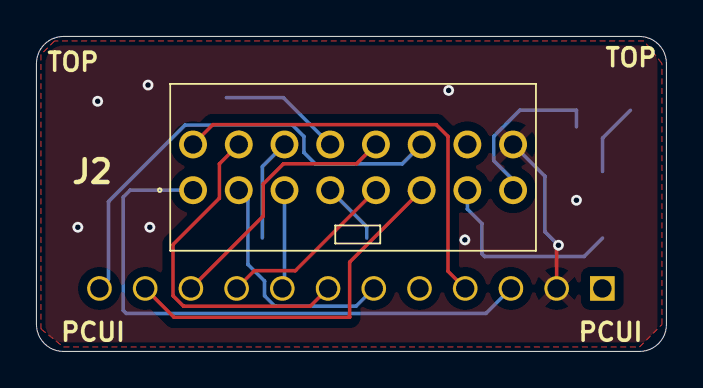
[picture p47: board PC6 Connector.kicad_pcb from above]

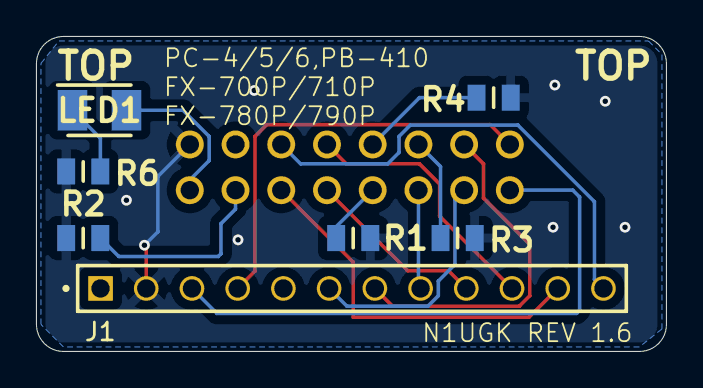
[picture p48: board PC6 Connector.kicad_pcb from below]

Board: 2 copper layers, 35.0 x 17.5 mm, 8 parts (7 on the bottom side), 16 nets.

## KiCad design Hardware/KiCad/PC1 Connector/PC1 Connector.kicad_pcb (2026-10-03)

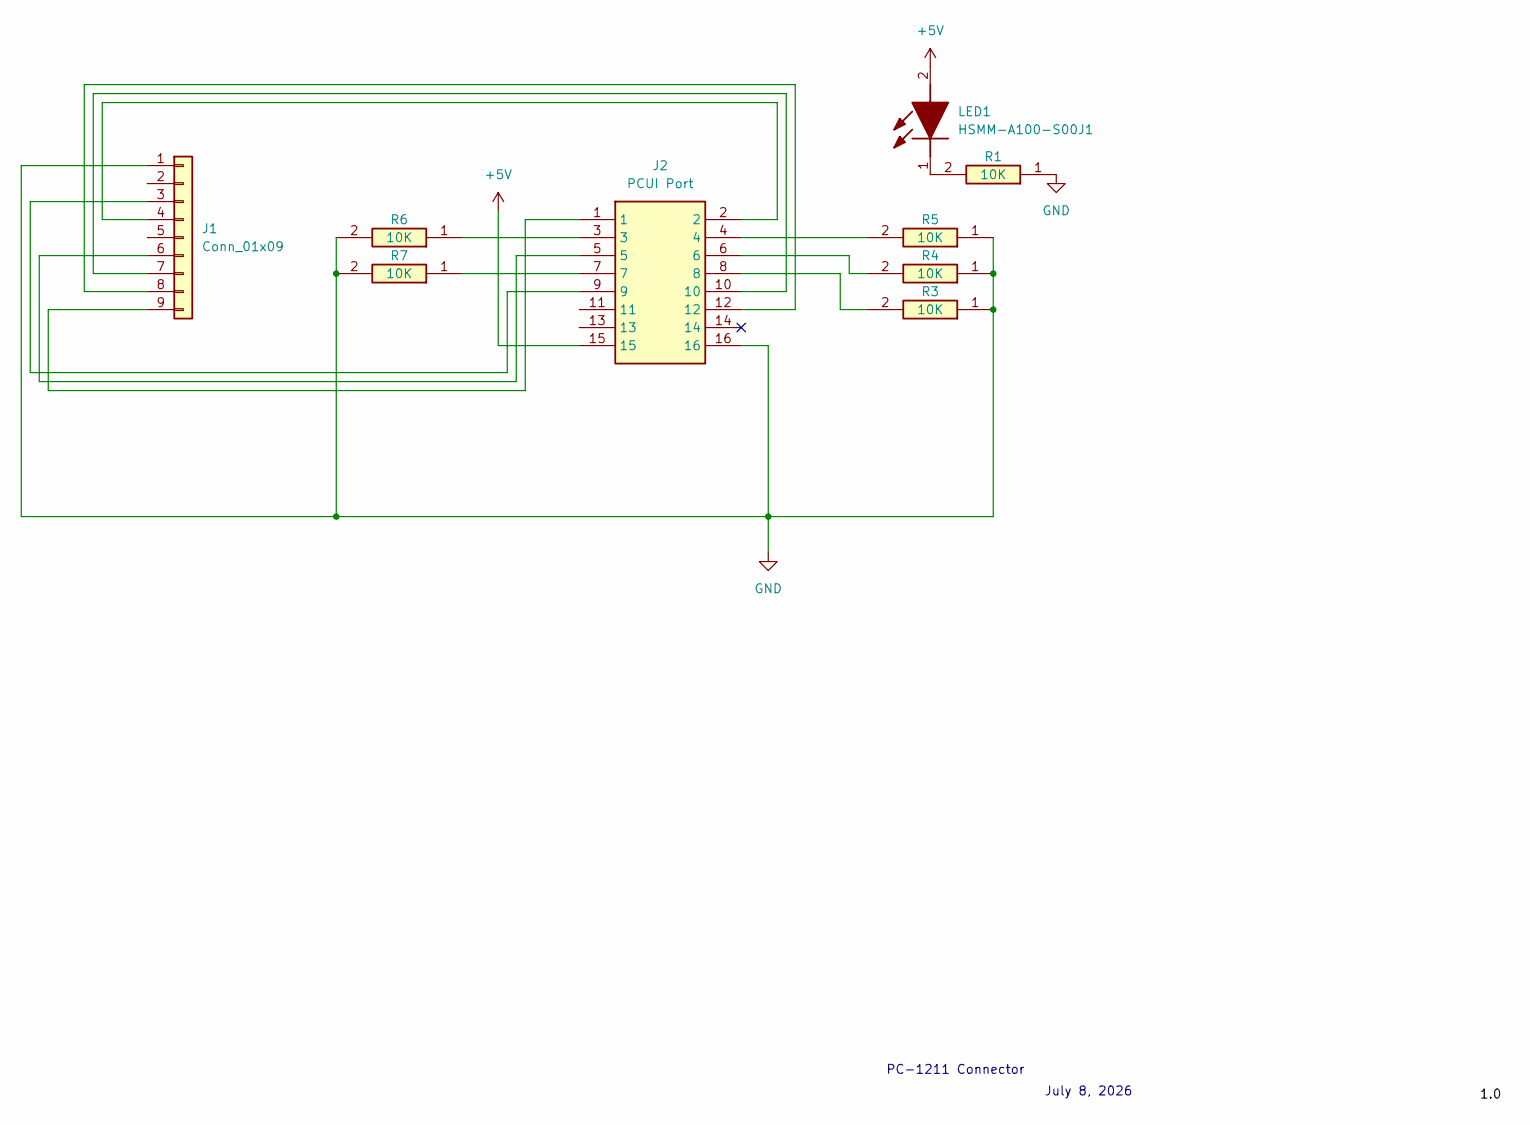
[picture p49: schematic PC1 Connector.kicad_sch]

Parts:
J1: Conn_01x09; PinHeader_1x09_P2.54mm_Vertical
J2: PCUI Port; TSS-108-XX-YYY-D; Manufacturer_Part_Number TSS-108-02-L-D
LED1: HSMM-A100-S00J1; LEDM3528X200N; Mouser Part Number 630-HSMM-A100-S00J1
R1, R3, R4, R5, R6, R7: 10K; RESC2013X65N; Mouser Part Number 756-WCR0805-10KFI

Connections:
+5V: J2.15, LED1.2 (A)
GND: J1.1, J2.16, R1.1, R3.1, R4.1, R5.1, R6.2, R7.2
unnamed: J1.3, J2.9
unnamed: J1.4, J2.2
unnamed: J1.6, J2.5
unnamed: J1.7, J2.10
unnamed: J1.8, J2.12
unnamed: J1.9, J2.1
unnamed: J2.3, R6.1
unnamed: J2.4, R5.2
unnamed: J2.6, R4.2
unnamed: J2.7, R7.1
unnamed: J2.8, R3.2
unnamed: LED1.1 (K), R1.2

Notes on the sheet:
July 8, 2026
PC-1211 Connector

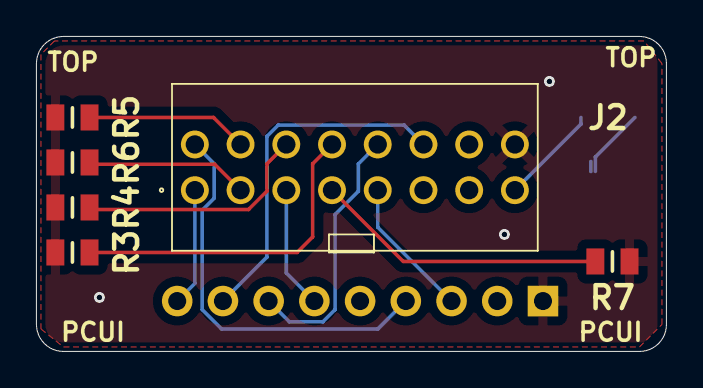
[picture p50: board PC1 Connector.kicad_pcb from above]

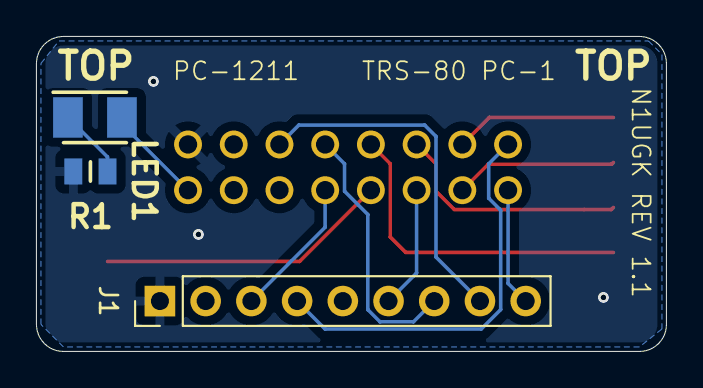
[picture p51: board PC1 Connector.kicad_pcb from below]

Board: 2 copper layers, 35.0 x 17.5 mm, 9 parts (3 on the bottom side), 14 nets.

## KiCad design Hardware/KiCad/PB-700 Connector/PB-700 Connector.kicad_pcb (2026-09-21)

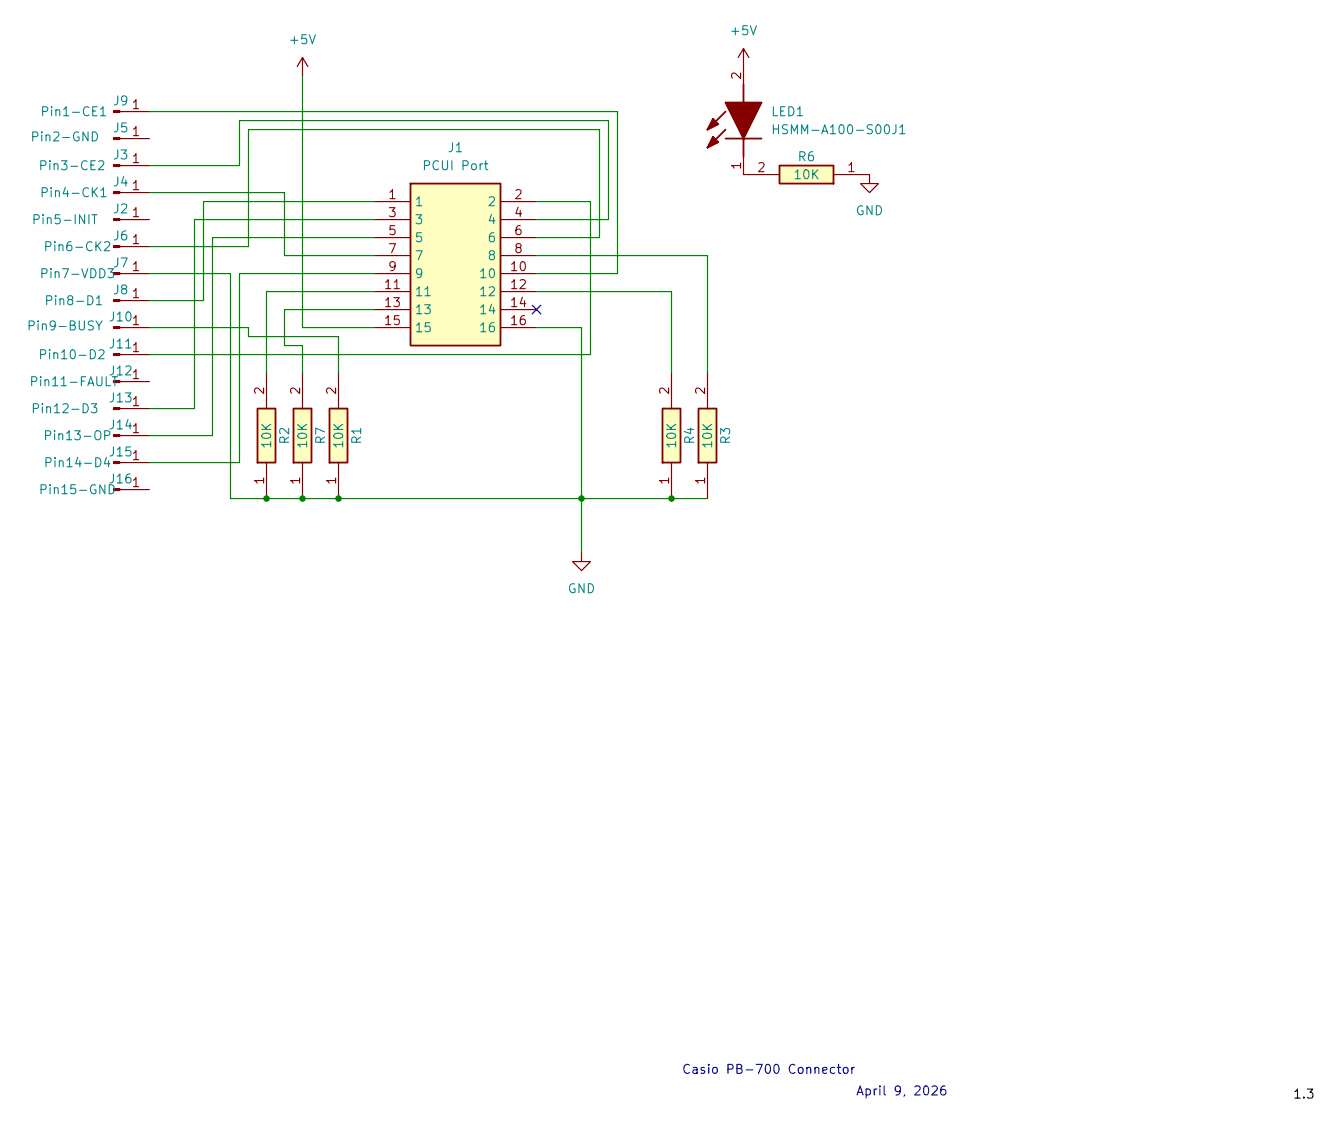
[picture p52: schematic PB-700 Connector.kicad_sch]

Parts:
J1: PCUI Port; TSS-108-XX-YYY-D; Manufacturer_Part_Number TSS-108-02-L-D
J2: Pin5-INIT; TH_1mm_1.5mm
J3: Pin3-CE2; TH_1mm_1.5mm
J4: Pin4-CK1; TH_1mm_1.5mm
J5: Pin2-GND; TH_1mm_1.5mm
J6: Pin6-CK2; TH_1mm_1.5mm
J7: Pin7-VDD3; TH_1mm_1.5mm
J8: Pin8-D1; TH_1mm_1.5mm
J9: Pin1-CE1; TH_1mm_1.5mm
J10: Pin9-BUSY; TH_1mm_1.5mm
J11: Pin10-D2; TH_1mm_1.5mm
J12: Pin11-FAULT; TH_1mm_1.5mm
J13: Pin12-D3; TH_1mm_1.5mm
J14: Pin13-OP; TH_1mm_1.5mm
J15: Pin14-D4; TH_1mm_1.5mm
J16: Pin15-GND; TH_1mm_1.5mm
LED1: HSMM-A100-S00J1; LEDM3528X200N; Mouser Part Number 630-HSMM-A100-S00J1
R1, R2, R3, R4, R6, R7: 10K; RESC2013X65N; Mouser Part Number 756-WCR0805-10KFI

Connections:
+5V: J1.15, LED1.2 (A)
GND: J1.16, J7.1, R1.1, R2.1, R3.1, R4.1, R6.1, R7.1
unnamed: J1.8, R3.2
unnamed: J1.11, R2.2
unnamed: J1.12, R4.2
unnamed: J1.13, R7.2
unnamed: J1.4, J3.1
unnamed: J1.7, J4.1
unnamed: J1.6, J6.1
unnamed: J1.1, J8.1
unnamed: J1.10, J9.1
unnamed: J10.1, R1.2
unnamed: J1.2, J11.1
unnamed: J1.3, J13.1
unnamed: J1.5, J14.1
unnamed: J1.9, J15.1
unnamed: LED1.1 (K), R6.2

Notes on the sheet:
April 9, 2026
Casio PB-700 Connector

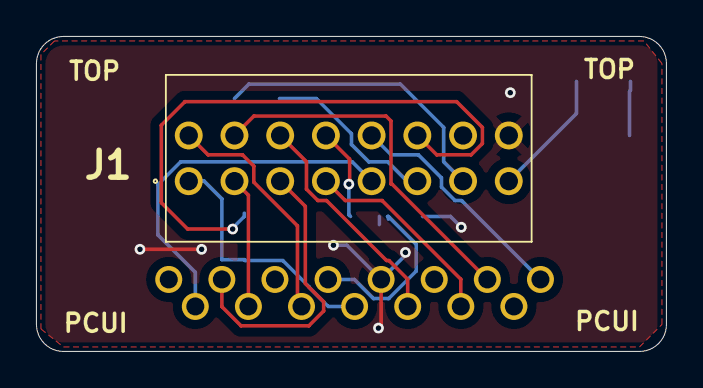
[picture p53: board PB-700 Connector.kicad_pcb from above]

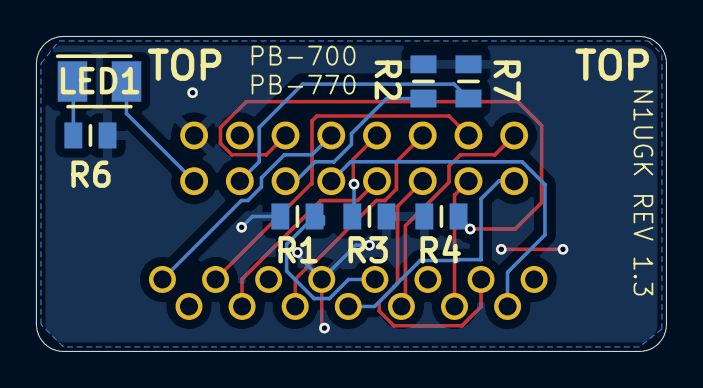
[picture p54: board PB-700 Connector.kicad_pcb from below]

Board: 2 copper layers, 35.0 x 17.5 mm, 23 parts (22 on the bottom side), 17 nets.

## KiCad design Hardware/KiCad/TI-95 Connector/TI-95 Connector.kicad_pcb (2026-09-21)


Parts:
C1, C2: 10uF; CP_EIA-3528-15_AVX-H_HandSolder
J1: Conn_01x10_Socket; PinSocket_1x10_P2.54mm_Vertical
J2: Conn_01x10; PinHeader_1x10_P2.54mm_Vertical
J27: CMOS Connector; SAMTEC_TSS-107-02-H-D; PARTREV R
LED1: HSMM-A100-S00J1; LEDM3528X200N; Mouser Part Number 630-HSMM-A100-S00J1
PS1: LM1117IMPX-3.3_NOPB; SOT230P700X180-4N; Mouser Part Number 926-LM1117IMPX33NOPB
Q1, Q2, Q3, Q4: BSS138DW-7-F; SOT65P210X110-6N; Mouser Part Number 621-BSS138DW-F
R1, R2, R3, R4, R5, R6, R7, R8, R9, R11, R12, R13, R14, R15, R16, R17, R18: 10K; RESC2013X65N; Mouser Part Number 756-WCR0805-10KFI

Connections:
+3.3V: C1.1, PS1.4 (VOUT), Q1.2 (G2), Q1.5 (G1), Q2.2 (G2), Q2.5 (G1), Q3.2 (G2), Q3.5 (G1), Q4.2 (G2), Q4.5 (G1), R1.2, R2.2, R3.2, R4.1, R5.1, R6.1, R14.1, R17.2
+5V: C2.1, J27.13, LED1.2 (A), PS1.3 (INPUT), R7.1, R8.1, R9.1, R11.2, R12.2, R13.2, R15.1, R16.2
/+5V-NC: J1.1, J2.1
/BAV: J1.8, J2.8, Q3.6 (D2), R13.1
/D0: J1.3, J2.3, Q1.3 (D1), R7.2
/D1: J1.4, J2.4, Q1.6 (D2), R11.1
/D2: J1.5, J2.5, Q2.3 (D1), R8.2
/D3: J1.6, J2.6, Q2.6 (D2), R12.1
/HSK: J1.7, J2.7, Q3.3 (D1), R9.2
GND: C1.2, C2.2, J1.10, J2.10, J27.14, PS1.1 (ADJ/GND), R18.1
unnamed: J1.2, J2.2
unnamed: J1.9, J2.9
unnamed: LED1.1 (K), R18.2
unnamed: J27.01, Q1.4 (S1), R1.1
unnamed: J27.02, Q1.1 (S2), R4.2
unnamed: J27.03, Q2.4 (S1), R2.1
unnamed: J27.04, Q2.1 (S2), R5.2
unnamed: J27.05, Q3.4 (S1), R3.1
unnamed: J27.06, Q3.1 (S2), R6.2
unnamed: Q4.3 (D1), R15.2
unnamed: Q4.6 (D2), R16.1
unnamed: J27.12, Q4.4 (S1), R17.1
unnamed: Q4.1 (S2), R14.2

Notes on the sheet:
July 10, 2026
TI-95 Connector



Board: 2 copper layers, 37.5 x 21.5 mm, 28 parts (23 on the bottom side), 23 nets.

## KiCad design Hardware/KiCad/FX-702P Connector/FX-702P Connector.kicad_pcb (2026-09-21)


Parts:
J1: Pin1-CE1; TH_1mm_1.5mm
J2: Pin3-D5; TH_1mm_1.5mm
J3: Pin5-OP1; TH_1mm_1.5mm
J4: Pin7-SP1; TH_1mm_1.5mm
J5: Pin2; TH_1mm_1.5mm
J6: Pin4; TH_1mm_1.5mm
J7: Pin6-GND1; TH_1mm_1.5mm
J27: CMOS Connector; SAMTEC_TSS-107-02-H-D; PARTREV R
LED1: HSMM-A100-S00J1; LEDM3528X200N; Mouser Part Number 630-HSMM-A100-S00J1
R6: 10K; RESC2013X65N; Mouser Part Number 756-WCR0805-10KFI

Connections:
+5V: J27.13, LED1.2 (A)
GND: J7.1, J27.14, R6.1
unnamed: J1.1, J27.02
unnamed: J2.1, J27.07
unnamed: J3.1, J27.03
unnamed: J4.1, J27.12
unnamed: LED1.1 (K), R6.2

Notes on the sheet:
October 2, 2025
Casio FX-702P Connector


Board: 2 copper layers, 35.0 x 17.5 mm, 10 parts (1 on the bottom side), 7 nets.

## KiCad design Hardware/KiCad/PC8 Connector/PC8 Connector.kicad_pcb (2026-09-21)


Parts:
J1: PC-1245 Connector; SAMTEC_TSW-111-14-G-S; PARTREV R
J2: PCUI Port; TSS-108-XX-YYY-D; Manufacturer_Part_Number TSS-108-02-L-D
LED1: HSMM-A100-S00J1; LEDM3528X200N; Mouser Part Number 630-HSMM-A100-S00J1
R1, R2, R3, R4, R6, R7: 10K; RESC2013X65N; Mouser Part Number 756-WCR0805-10KFI
R8, R9, R10, R11, R12: 220K; RESC2013X65N; Mouser Part Number 756-WCR0805-10KFI

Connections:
+5V: J2.15, LED1.2 (A); also elsewhere on the board
GND: J1.03, J2.16, R1.2, R2.2, R3.1, R4.1, R6.1, R7.1, R8.2, R9.2, R10.2, R11.2, R12.2
unnamed: J1.04, J2.5, R12.1
unnamed: J1.05, J2.4, R11.1
unnamed: J1.06, J2.9
unnamed: J1.07, J2.1, R10.1
unnamed: J1.08, J2.11
unnamed: J1.09, J2.10
unnamed: J1.10, J2.2, R9.1
unnamed: J1.11, J2.3, R8.1
unnamed: J2.6, R7.2
unnamed: J2.7, R1.1
unnamed: J2.8, R3.2
unnamed: J2.12, R4.2
unnamed: J2.13, R2.1
unnamed 15: LED1.1 (K), R6.2; also elsewhere on the board

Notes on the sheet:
October 2, 2025
PC-1245 Connector



Board: 2 copper layers, 35.0 x 17.5 mm, 14 parts (13 on the bottom side), 16 nets.

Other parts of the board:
PWR: HSMM-A100-S00J1; LEDM3528X200N

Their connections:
+5V: PWR.2 (A); also elsewhere on the board
unnamed 15: PWR.1 (K); also elsewhere on the board

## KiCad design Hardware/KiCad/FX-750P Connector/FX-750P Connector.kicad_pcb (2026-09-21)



Board: 2 copper layers, 35.0 x 17.5 mm, 8 parts (7 on the bottom side), 15 nets.

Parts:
J1: FX-750P Connector; SAMTEC_TSW-112-07-L-S-LL
J2: PCUI Port; TSS-108-XX-YYY-D
LED1: HSMM-A100-S00J1; LEDM3528X200N
R1, R2, R3, R4, R6: 10K; RESC2013X65N

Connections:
+5V: J2.15, LED1.2 (A)
/CE1: J1.03, J2.2
/CE2: J1.02, J2.1
/CK1: J1.10, J2.3
/CK2: J1.09, J2.4
/D1: J1.04, J2.9
/D2: J1.08, J2.10
/D3: J1.07, J2.11
/GPIO11: J2.5, R2.1
/GPIO12: J2.6, R3.2
/GPIO13: J2.7, R1.1
/GPIO14: J2.8, R4.2
/GPIO21: J1.06, J2.13
GND: J1.01, J2.16, R1.2, R2.2, R3.1, R4.1, R6.1
unnamed: LED1.1 (K), R6.2

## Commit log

2026-05-11 Added first public firmware release and 2 sample programs for the 1401 series.
2026-05-21 Added sample programs
2026-07-31 New sample program
2026-09-11 Added 3D model of main board
2026-09-21 Update README with purchasing information for PCUI
    Added details about purchasing options for PCUI kits and fully assembled units.
2026-09-21 Added KiCad Projects
    [FX-702P Connector.kicad_pcb, FX-702P Connector.kicad_sch, FX-750P Connector.kicad_pcb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]
2026-09-21 Added 3D exports for hardware
    [FX-702P Connector.step, FX-750P Connector.step, PB-700 Connector.step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]
2026-09-26 Updated assembly guide.
2026-10-03 Updated owners manual and PC-1 Connector.
    [PC1 Connector.kicad_pcb]
2026-10-10 Updates to PCBs, added 3D models for molds for 702P and 700/770; Update to PC-6 PCB and PB-700 mold; Assembly instruction updates, model updates (track .step/.stl via Git LFS)
    [FX-702P Connector.step, FX-702P Jig.stl, FX-702P.FCStd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]
2026-10-10 Stop tracking KiCad fp-info-cache (local machine cache)
2026-10-10 Updates to assembly guide
2026-10-10 Lowered height of 702P mold
2026-10-10 Assembly instructions updates
2026-10-12 Fabrication outputs and updated assembly instructions
2026-11-06 Added PCUI Case 3D model files
2026-11-09 Updated Pocket Computer connectors on top half of case.
2026-11-10 Updates to case.
